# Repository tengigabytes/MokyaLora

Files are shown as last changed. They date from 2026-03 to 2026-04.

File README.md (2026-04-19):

# MokyaLora

An open-hardware standalone Meshtastic feature phone built around the RP2350B dual-core MCU,
with a 36-key physical keyboard, 2.4″ IPS display, SX1262 LoRa radio, and GNSS.
Licensed under CERN-OHL-S-2.0 (hardware) and CC-BY-SA-4.0 (documentation).

## Project Status

### Hardware

| Revision | Status |
|---|---|
| Rev A | **Received 2026-04-02 — bringup in progress** — 21 of 25 steps fully passed; 3 open issues |

**Rev A bringup summary** (see [`docs/bringup/rev-a-bringup-log.md`](docs/bringup/rev-a-bringup-log.md) for full details):

| Step | Component | Result |
|---|---|---|
| 1 | Power rails (1.8 V / 3.3 V) | ✅ PASS |
| 2 | MCU boot + USB CDC | ✅ PASS |
| 3 | I2C sensors (IMU / Mag / Baro / GNSS) | ✅ PASS |
| 4 | TFT LCD (ST7789VI, PIO 8080) | ✅ PASS (via FPC adapter — Issue 5) |
| 5 | LoRa SX1262 (SPI + RF link) | ✅ PASS (TX/RX verified — Step 23) |
| 6 | Keypad (6×6 matrix, 36 keys) | ✅ PASS |
| 7 | Audio — NAU8315 I2S amp + speaker | ✅ PASS |
| 8 | Battery (BQ25622 charger) + vibration motor | ⚠️ CONDITIONAL (charger OK; BQ27441 cold-boot NACK — Issue 10) |
| 9 | Flash + PSRAM (W25Q128JW + APS6404L) | ✅ PASS (QPI 37.5 MHz, 150 Mbit/s, 8 MB validated) |
| 10 | PDM microphone (IM69D130) | ⚠️ PARTIAL (capture/playback OK; background noise) |
| 11 | J-Link SWD debug | ✅ PASS |
| 12 | BQ27441 fuel gauge | ⚠️ CONDITIONAL (SOC readable; learning cycle pending) |
| 13 | TFT fast refresh (DMA) | ✅ PASS (60–80 FPS) |
| 14 | GNSS outdoor RF test | ❌ FAIL (0 satellites — Issue 11) |
| 15 | LoRa RF performance | ✅ PASS (Meshtastic mesh validated) |
| 16 | Core 1 (A–H stages) | ✅ PASS (FreeRTOS SMP, IPC, sensors, SPI) |
| 17 | Meshtastic integration | ✅ PASS (bidirectional mesh messaging) |
| 18–19 | Interactive menu + regression tests | ✅ PASS (51+ commands, TFT menu, 18/20 reliable) |
| 20–21 | Menu consolidation + code modularisation | ✅ PASS (21 source files, ~8580 lines) |
| 23 | LoRa standalone TX/RX | ✅ PASS (6 bug fixes, AES-128-CTR TX) |
| 24 | Core 1 TFT output + menu wrap-around | ✅ PASS |
| 25 | PSRAM DMA error investigation | ⚠️ CONDITIONAL (DMA burst read errors observed, root cause unconfirmed; CPU read workaround) |

**Open issues:** Issue 10 (BQ27441 cold-boot latchup), Issue 11 (GNSS 0 satellites), Issue 14 (PSRAM DMA burst read errors — root cause unconfirmed, no production impact).

### Firmware

| Component | Status |
|---|---|
| Core 0 — Meshtastic modem | **Validated** — LoRa modem running on Rev A (v2.7.15 dev, `rp2350b-mokya` variant); bidirectional mesh messaging confirmed |
| Core 1 — FreeRTOS + UI | **Architecture validated** — FreeRTOS SMP, manual TinyUSB CDC, IPC, I2C sensors all proven on hardware; LVGL integration pending |
| MokyaInput Engine (MIE) | **Phase 1 complete** — full IME (Smart Zh/En, Direct, Bopomofo), C API, 83/83 tests passing |
| Bringup shell | **Active** — `firmware/tools/bringup/`; 51+ commands, TFT interactive menu, 21 source files |

## System Overview

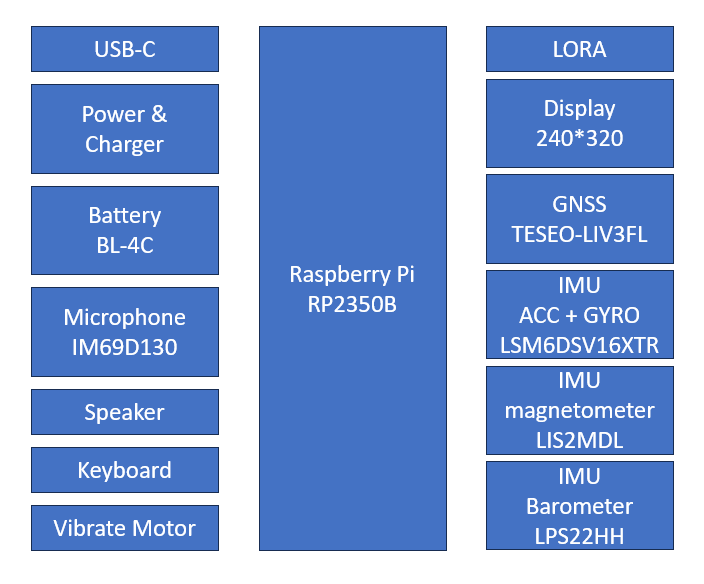
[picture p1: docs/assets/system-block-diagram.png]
System Block Diagram


## PCB Preview (Rev A)

| Front | Back |
|:-----:|:----:|
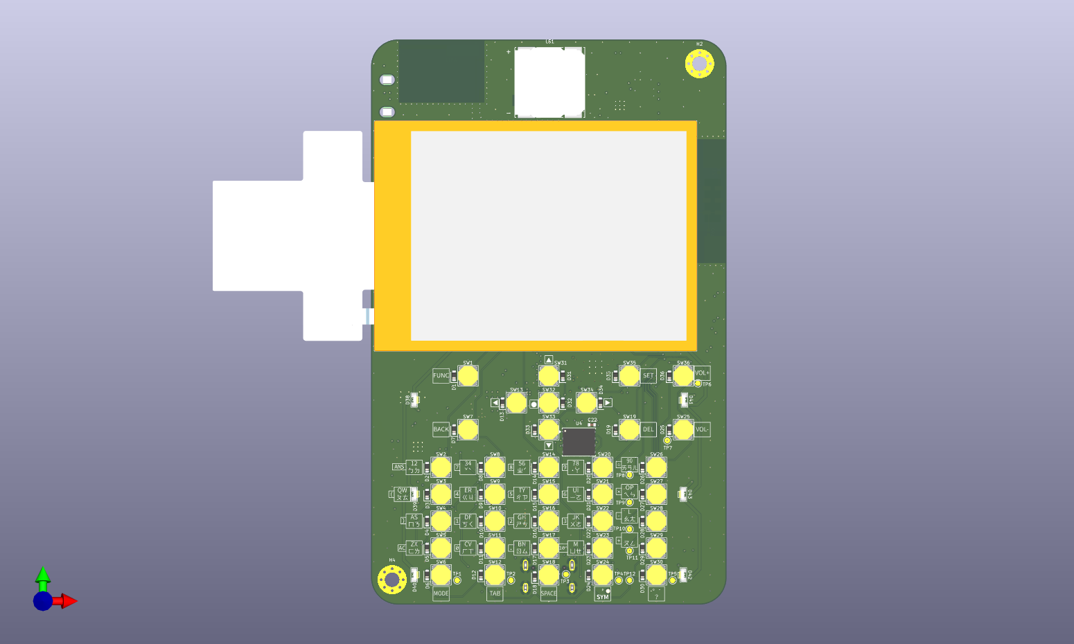
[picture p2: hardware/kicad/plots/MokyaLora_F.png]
PCB Front
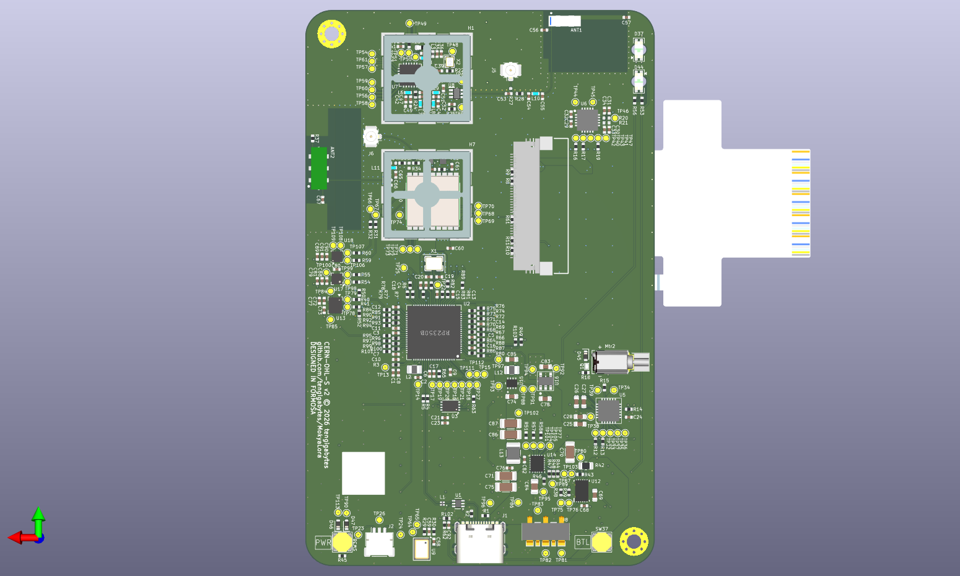
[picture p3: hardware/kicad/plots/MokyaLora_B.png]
PCB Back
|  |  |

## Design Documents

| Document | Description |
|---|---|
| [Schematic (PDF)](hardware/production/rev-a/pdf/MokyaLora.pdf) | Full schematic — all 13 sheets |
| [Assembly Drawing (PDF)](hardware/production/rev-a/pdf/MokyaLora__Assembly.pdf) | Component placement drawing |
| [Bill of Materials (CSV)](hardware/production/rev-a/MokyaLora.csv) | Rev A BOM |
| [Board 3D Model (STEP)](hardware/production/rev-a/MokyaLora.step) | Full-board STEP export |
| [Gerber Files](hardware/production/rev-a/gerber/) | Rev A fabrication outputs |

## Repository Layout

```
MokyaLora/
├── docs/
│   ├── assets/                         # Documentation images (block diagrams, etc.)
│   ├── requirements/                   # Requirements specifications
│   │   ├── system-requirements.md      # System-level spec, operating modes, mandatory HW rules
│   │   ├── hardware-requirements.md    # Full BOM, power tree, GPIO map, keypad matrix, design rules
│   │   └── software-requirements.md   # SRS (WHAT): driver needs, power states, UI/UX, IME requirements
│   ├── design-notes/                   # Design decision records
│   │   ├── power-architecture.md       # Power tree, rail definitions, charger/gauge configuration
│   │   ├── rf-matching.md              # LoRa / GNSS RF frontend, TCXO coupling, antenna rules
│   │   └── mcu-gpio-allocation.md      # Full GPIO pin map, I2C bus allocation
│   ├── bringup/                        # Bring-up and debug logs
│   │   ├── rev-a-bringup-log.md
│   │   └── measurements/               # Oscilloscope / spectrum captures
│   └── manufacturing/                  # Manufacturing-related documents
│       ├── fab-notes.md                # PCB specification, Gerber list, assembly notes
│       └── compliance.md              # Regulatory notes (CE / FCC / NCC)
├── hardware/
│   ├── kicad/                          # KiCad 8 source design files
│   │   ├── MokyaLora.kicad_pro         # Project file
│   │   ├── MokyaLora.kicad_sch         # Top-level schematic (13 sub-sheets)
│   │   ├── MokyaLora.kicad_pcb         # PCB layout
│   │   ├── MokyaLora.kicad_sym         # Project symbol library
│   │   ├── *.kicad_dbl                 # Component database libraries (ODBC: KiCad-Library DSN)
│   │   ├── MokyaLora.pretty/           # Project footprint library (61 footprints)
│   │   ├── packages3D/                 # Component 3D models — see NOTICE for licensing
│   │   ├── FabricationFiles/           # KiCad fabrication output (Gerbers + BOM)
│   │   └── plots/                      # KiCad plot output (schematic PDF)
│   ├── production/                     # Released fabrication snapshots (copied from FabricationFiles)
│   │   └── rev-a/
│   │       ├── gerber/                 # Gerber + drill files
│   │       ├── pdf/                    # Schematic PDF + assembly drawing PDF
│   │       ├── MokyaLora.csv           # Bill of Materials
│   │       └── MokyaLora.step          # Full-board 3D export
│   └── mechanical/                     # Enclosure and stack-up drawings (future)
│       └── enclosure/
├── firmware/                           # Firmware (future — Arduino-Pico + FreeRTOS + LVGL)
│   ├── CMakeLists.txt
│   ├── core0/                          # Core 0 modem firmware [GPL-3.0]
│   │   └── src/                        # Meshtastic stack integration
│   ├── core1/                          # Core 1 UI & application firmware [Apache-2.0]
│   │   └── src/                        # LVGL, FreeRTOS, MIE integration
│   ├── mie/                            # MokyaInput Engine — IME sub-library [MIT]
│   │   ├── CMakeLists.txt              # Builds as static library; no Pico SDK dependency
│   │   ├── include/mie/                # Public headers
│   │   ├── src/                        # Trie-Searcher, IME-Logic
│   │   ├── hal/                        # IHalPort interface + rp2350 / pc adapters
│   │   ├── tools/                      # gen_font.py, gen_dict.py (data pipeline)
│   │   ├── data/                       # Generated .bin assets (gitignored)
│   │   └── tests/                      # C++ unit tests (host build only)
│   ├── shared/
│   │   └── ipc/                        # Inter-core IPC protocol definition [MIT]
│   │       └── ipc_protocol.h          # Sole interface boundary between Core 0 and Core 1
│   └── tools/                          # Flash scripts and test utilities
└── .gitignore
```

## Licenses

| Component | Directory | License |
|---|---|---|
| Hardware design | `hardware/` | CERN-OHL-S-2.0 |
| Documentation | `docs/` | CC-BY-SA-4.0 |
| Core 0 firmware | `firmware/core0/` | GPL-3.0 |
| Core 1 firmware | `firmware/core1/` | Apache-2.0 |
| MokyaInput Engine | `firmware/mie/` | MIT |
| IPC protocol | `firmware/shared/ipc/` | MIT |

See [LICENSE](LICENSE) for the full rationale. License files are also present in each component directory.

## Authorship and Development Approach

| Area | Authorship |
|---|---|
| Requirements — technical concepts and design decisions | Project owner |
| Requirements — document writing and formatting | Assisted by [Claude Code](https://claude.ai/claude-code) |
| Hardware design (schematic, PCB layout) | Project owner |
| Documentation — organisation, formatting, and structure | Assisted by [Claude Code](https://claude.ai/claude-code) |
| Firmware and software development | Assisted by [Claude Code](https://claude.ai/claude-code) |

All technical concepts, design decisions, and hardware choices originate with the project
owner. Claude Code is used as a development tool; all AI-assisted output is reviewed and
accepted by the project owner before being committed.

## Disclaimer

> **This project is an experimental prototype. Use at your own risk.**

### Hardware

- **Prototype status** — Rev A is an unverified first prototype. The design has not been
  independently tested, reviewed, or certified. Do not use this design as the sole basis
  for a production product without thorough independent validation.

- **RF and wireless regulations** — This device incorporates a LoRa radio transmitter.
  Operation of radio transmitters is regulated by law in most jurisdictions (NCC in Taiwan,
  CE/RED in the EU, FCC Part 15 in the US, and equivalents elsewhere). The user is solely
  responsible for ensuring that any use of this design complies with applicable local
  wireless regulations. No regulatory certification (CE, FCC, NCC) has been obtained for
  this design.

- **Battery and electrical safety** — This design includes a lithium-ion battery charging
  circuit. Improper assembly, use of incorrect components, or failure to follow safe
  lithium-ion handling practices may result in fire, injury, or damage to property.
  Always verify the design independently before assembly.

- **No warranty** — This hardware is provided "as-is" without any warranty of any kind,
  express or implied. See [CERN-OHL-S-2.0](LICENSE-CERN-OHL-S-2.0.txt) Section 6 for the
  full disclaimer of warranties and limitation of liability.

### Firmware

- **Bringup firmware** — A hardware validation shell (`firmware/tools/bringup/`) is
  available for Rev A bring-up. It is a development/test tool only and is not intended
  for end-user deployment.

- **MokyaInput Engine (MIE)** — The IME sub-library (`firmware/mie/`) is available as a
  host-buildable static library with unit tests. It has not yet been integrated with
  RP2350B hardware.

- **Core 0 / Core 1** — Application firmware development has not yet started.

- **No warranty** — All firmware is provided "as-is" under its respective open-source
  licence (GPL-3.0 for Core 0, Apache-2.0 for Core 1, MIT for MIE and bringup tools)
  without any warranty of fitness for a particular purpose.

## Contributing

See [CONTRIBUTING.md](CONTRIBUTING.md) for contribution guidelines.

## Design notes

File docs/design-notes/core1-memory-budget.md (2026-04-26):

# Core 1 Memory Budget

Single source of truth for RAM allocations on the Core 1 application image
(`m1_bridge`, loaded at `0x10200000`). Any new task, queue, or large static
buffer MUST be added to the appropriate table below **before** the code is
merged. The build-time log line (see §5) cross-checks this at boot.

Rationale: M3.4.5d uncovered the pattern of growing `configTOTAL_HEAP_SIZE`
reactively after each new task HardFaulted on `vTaskStartScheduler`'s
IDLE-task allocation. Planning upfront is cheaper than SWD archaeology.

---

## 1. RP2350B SRAM

Physical SRAM on RP2350B is **520 KB** at `0x20000000 – 0x20082000`.

| Region | Size | Owner | Notes |
|---|---|---|---|
| Shared IPC window | 24 KB | Core 0 ↔ Core 1 | Fixed, reserved at link time — see firmware-architecture.md §5. |
| Core 1 .text/.rodata/.data/.bss | ~300 KB | m1_bridge image | Driver/LVGL/FreeRTOS code + statics. |
| FreeRTOS heap (heap_4) | **48 KB** | `configTOTAL_HEAP_SIZE` | Task stacks, TCBs, kernel objects. See §3. |
| LVGL heap | **48 KB** | `LV_MEM_SIZE` in `lv_conf.h` | Separate from FreeRTOS. Widgets, styles, fonts, draw buffers. |
| MCU main stack (MSP) | 4 KB | linker `__StackTop` | Pre-scheduler + exception handlers. |
| LVGL framebuffer(s) | see §4 | `display/lvgl_glue.c` | Currently one partial buffer. |
| Slack | — | — | Whatever's left. Goal: keep ≥ 32 KB unused for growth. |

`scripts/build_and_flash.sh` prints the section sizes after each Core 1
link; compare against this table when the numbers drift.

---

## 2. Design rules

1. **Upfront budget.** Adding a new task or any `pvPortMalloc`-caller
   (queue, semaphore, event group, timer) requires updating §3 **in the
   same commit**. No silent growth.
2. **No silent failures.** Every `xTaskCreate` return value and every
   `*_task_start` boolean MUST be checked. Main aborts with a clear log
   line if anything fails — see `main_core1_bridge.c`. No more
   `(void)rc_xxx;`.
3. **Stack sizing method.** Start from an empirical peak:
   - enable `configCHECK_FOR_STACK_OVERFLOW = 2` (already set)
   - run the task under its worst-case path for at least 10 minutes
   - read `uxTaskGetStackHighWaterMark()` via SWD or a runtime CLI
   - round up to high-water + 25 % (not +1 %).
4. **Prefer static allocation for kernel objects.** FreeRTOS supports
   `xQueueCreateStatic` / `xSemaphoreCreateMutexStatic`. We currently use
   dynamic allocation because `configSUPPORT_STATIC_ALLOCATION = 0`.
   Flip only when we actually need to diagnose heap fragmentation.
5. **LVGL heap stays separate.** Widgets, styles, lv_malloc — all from
   `LV_MEM_SIZE`. Never split widgets across FreeRTOS heap.
6. **Reserve ≥ 15 % of `configTOTAL_HEAP_SIZE`** at all times. With the
   current 48 KB heap, that is ≥ 7.2 KB free after all tasks are
   running. The boot-time log prints the figure (and stashes it in
   `g_core1_boot_heap_free` for SWD readback) — `main` panics if we
   cross it. **Threshold was loosened from 20 % to 15 % on 2026-04-24**
   when the Phase 1.6 RTT key-inject task (1 KB TCB/stack) pushed free
   from 9.6 KB down to ~9 KB; see `phase2-log.md` "P1.6 follow-up"
   entry. The original 20 % target was a forward-looking budget for
   "future driver growth", not a hard requirement — 15 % still leaves
   1.6 KB buffer above transient FreeRTOS needs.

---

## 3. FreeRTOS heap budget (`configTOTAL_HEAP_SIZE = 48 KB`)

Heap is consumed by task stacks (4 bytes per word), TCBs (~88 B each on
32-bit V11), and kernel objects (queues/mutexes/semaphores ~80-100 B
each + their storage). `heap_4` adds ~16 B overhead per allocation.

### 3.1 Application tasks

| Task name | File | Stack (words) | Stack (B) | Priority | Purpose |
|---|---|---:|---:|---|---|
| `usb` | `main_core1_bridge.c` | 1024 | 4096 | tskIDLE+2 | TinyUSB device; `tud_task()` + taskYIELD loop. |
| `bridge` | `main_core1_bridge.c` | 1024 | 4096 | tskIDLE+2 | Core 0 ↔ Core 1 IPC pump; HW-FIFO doorbell listener. |
| `lvgl` | `src/display/lvgl_glue.c` | 3072 | 12288 | tskIDLE+2 | `lv_timer_handler()` + draw buffer flush; largest stack because LVGL draw paths nest deeply. |
| `kpad` | `src/keypad/keypad_scan.c` | 512 | 2048 | tskIDLE+2 | PIO+DMA keypad scan, 20 ms debounce, enqueue `key_event_t`. |
| `chg` | `src/power/bq25622.c` | 512 | 2048 | tskIDLE+2 | 1 Hz charger poll + watchdog kick. |
| `sens` | `src/sensor/sensor_task.c` | 512 | 2048 | tskIDLE+2 | Shared tick for LPS22HH / LIS2MDL / LSM6DSV16X. |
| `gps` | `src/sensor/gps_task.c` | 512 | 2048 | tskIDLE+2 | Teseo-LIV3FL NMEA drain + parser. |
| `ime` | `src/ime/ime_task.cpp` | 1024 | 4096 | tskIDLE+3 | Drain `key_event_t` queue → `ImeLogic::process_key`; 20 ms `tick()` for multi-tap / long-press; owns the `ImeLogic` instance + both `TrieSearcher` instances as statics (~3 KB, see §4). Primary consumer of the KeyEvent queue (FA §4.4); the listener callbacks are re-entrancy-free. |
| `key_inject` | `src/keypad/key_inject.c` | 256 | 1024 | tskIDLE+2 | Drain `g_key_inject_buf` ring (SWD transport) → `key_event_push_inject_flags`. Skip-loop when `g_key_inject_mode != SWD`. |
| `key_inj_rtt` | `src/keypad/key_inject_rtt.c` | 256 | 1024 | tskIDLE+2 | Drain SEGGER RTT down-channel 1 → parse binary wire frame → `key_event_push_inject_flags`. Skip-loop when `g_key_inject_mode != RTT`. Stack sized for TRACE()'s 128 B vsnprintf scratch. |
| **App subtotal** |  | | **34,944 B (34.1 KB)** | | |

### 3.2 FreeRTOS internal tasks

| Task | Stack (words) | Stack (B) | Source |
|---|---:|---:|---|
| `IDLE` | 512 (`configMINIMAL_STACK_SIZE`) | 2048 | `tasks.c` creates during `vTaskStartScheduler`. |
| `Tmr Svc` | 512 (`configTIMER_TASK_STACK_DEPTH`) | 2048 | `timers.c`, enabled by `configUSE_TIMERS = 1`. |
| **Kernel subtotal** | | **4096 B (4.0 KB)** | |

### 3.3 Queues, semaphores, misc

| Object | File | Storage | Overhead | Total |
|---|---|---:|---:|---:|
| `i2c_bus_mutex` (mutex) | `src/i2c/i2c_bus.c` | — | ~80 B | ~80 B |
| `KeyEvent queue` (16 × 2 B) | `src/keypad/key_event.c` | 32 B | ~80 B | ~112 B |
| `KeyEvent view queue` (16 × 2 B) | `src/keypad/key_event.c` | 32 B | ~80 B | ~112 B |
| `ime snapshot mutex` | `src/ime/ime_task.cpp` | — | ~80 B | ~80 B |
| Timer queue (10 × ~12 B) | `timers.c` | ~120 B | ~80 B | ~200 B |
| TCBs (9 tasks × ~88 B) | `tasks.c` | — | — | ~792 B |
| Heap_4 per-alloc overhead | `heap_4.c` | — | ~16 B × ~15 blocks | ~240 B |
| **Misc subtotal** | | | | **~1.6 KB** |

### 3.4 Totals

| | Bytes (pre-IME) | Post-M4 IME | Post-P1.6 follow-up (RTT) |
|---|---:|---:|---:|
| §3.1 App tasks | 28,864 | 32,960 | 34,944 |
| §3.2 Kernel tasks | 4,096 | 4,096 | 4,096 |
| §3.3 Queues / TCBs / overhead | ~1,420 | ~1,700 | ~1,900 |
| **Estimated** | **~34.4 KB** | **~38.8 KB** | **~40.9 KB** |
| `configTOTAL_HEAP_SIZE` | 49,152 | 49,152 | 49,152 |
| **Reserve (threshold 15 %)** | **~14.7 KB (30 %)** ✓ | **~10.5 KB (21 %)** ✓ | **~8.2 KB (17 %)** ✓ |

**Measured 2026-04-24 post RTT task (SWD, `g_core1_boot_heap_free`)**:
`xFreeBytesRemaining = 9,312 B (19 %)` — 1.9 KB above the 15 %
panic threshold; ~0.3 KB below the estimate, consistent with
heap_4 fragmentation overhead settling at ~10 %.

**Measured via SWD (2026-04-18, post-M3.4.5d, before IME task lands)**:
`xFreeBytesRemaining = 15,008 B (14.65 KB, 30.5 %)`,
`xMinimumEverFreeBytesRemaining = 15,008 B` — estimate matches reality.
The post-M4 column is projected; re-measure after `ime` task creation
and revisit the stack sizing if the IME state ends up larger than
~3 KB or run_search's prefix-scan working set pushes over 4 KB stack.

---

## 4. Notable static buffers

Not exhaustive — just the ones large enough (≥ 256 B) to care about.

| Buffer | File | Size | Notes |
|---|---|---:|---|
| `s_drain_buf` | `src/sensor/teseo_liv3fl.c` | 256 B | Teseo I2C burst read buffer. |
| `s_gsv` accumulator × 4 | same | ~400 B | Per-talker satellite cycle builders. |
| `s_sat_view` | same | ~200 B | Published 32-sat snapshot. |
| `s_rf_state` | same | ~440 B | RF/signal diagnostics (noise, ANF, CPU, per-sat). Populated only after `teseo_enable_rf_debug_messages(true)` commissioning. |
| `s_line` | same | 96 B | NMEA line accumulator. |
| `ImeLogic` instance (M4) | `src/ime/ime_task.c` | ~3 KB | 50 × `Candidate` (~40 B) ≈ 2 KB + 256 B display + 64 B key_seq + ~200 B per-candidate prefix + state. Static to keep the `ime` task stack small. |
| LVGL draw buffer | `src/display/lvgl_glue.c` | TBD | One partial buffer for ST7789VI; update when the allocation is promoted from `LV_MEM_SIZE` to explicit static. |

Shared-SRAM IPC buffers (SPSC rings + GPS double-buffer) live in the
24 KB IPC window and are **not** in either heap — see §5 of
`firmware-architecture.md`.

---

## 5. Boot-time invariants (implemented in `main_core1_bridge.c`)

After `vTaskStartScheduler()` returns control to the scheduler and the
first task runs, the bridge task logs:

```
[m1] heap: total=49152  free=NNNNN  minEverFree=NNNNN  (target free ≥ 9830 = 20%)
```

If `free < 20 % of total`, this is flagged via IPC `LOG_LINE` at WARN
level so any regression during CI or commissioning is visible on the
host.

Every task-start helper (`lvgl_glue_start`, `bq25622_start_task`,
`sensor_task_start`, `gps_task_start`, `keypad_scan_task_create`) and
every direct `xTaskCreate` call in `main` is wrapped in:

```c
if (rc_foo != pdPASS) { panic("xTaskCreate(foo) failed"); }
```

No `(void)rc_xxx` casts. A panic prints the task name so the failing
allocation is immediately obvious from the USB CDC log (no more SWD
`mem32 ...ED28` archaeology to figure out which task ran out of heap).

---

## 6. Checklist when adding a new task

1. Decide on a stack size — start from **512 words** unless the task has
   a specific reason to be larger (LVGL → 3072 from empirical draw
   recursion, USB → 1024 because TinyUSB lives in globals).
2. Add a row to §3.1 in this file and update §3.4 Totals.
3. If the new subtotal pushes Reserve below 20 %, bump
   `configTOTAL_HEAP_SIZE` **in the same commit** that adds the task.
4. Wire the `*_task_start` helper into `main_core1_bridge.c` with a
   `panic`-on-fail check. Never `(void)rc_xxx`.
5. After the first successful run, read `uxTaskGetStackHighWaterMark()`
   and update the row if the stack can be shrunk (leave +25 % headroom).

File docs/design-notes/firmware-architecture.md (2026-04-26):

# Firmware Architecture

**Project:** MokyaLora (Project MS-RP2350)
**Status:** Phase 2 — Core 0/Core 1 dual-image production firmware (Rev A)
**Last updated:** 2026-04-15

This document is the **single source of truth** for how MokyaLora's dual-core
firmware is built. If it conflicts with the SRS
(`docs/requirements/software-requirements.md`) or with CLAUDE.md on any
implementation detail — memory map, IPC byte layout, build flow, boot sequence,
licence boundary — this document and the normative headers it references
(`ipc_protocol.h`, `ipc_shared_layout.h`, `memmap_core1_bridge.ld`) win.

The SRS specifies **what** the firmware must do (user behaviour, performance
targets, compatibility). This document specifies **how** that is realised.

It covers:

1. Dual-core AMP topology and licence boundary (§1)
2. Full memory map — Flash layout, SRAM partition, PSRAM allocation (§2)
3. Per-core software stacks — from HW peripheral up through driver → HAL → service → app (§3, §4)
4. USB Mode OFF / COMM — charge-only vs composite CDC (Meshtastic + Control) (§4.6); Control Protocol (§4.7)
5. Shared-SRAM IPC — 24 KB byte map, message catalogue, end-to-end flows, doorbell (§5)
6. MIE user-dictionary persistence via IPC (§5.7, planned for M5+)
7. Cross-image non-interference — link, boot, SRAM, SPSC, memory ordering, flash safety (§6)
8. Bus and peripheral ownership (§7)
9. Build system isolation — PlatformIO vs. CMake, ELF vs. BIN, dual-image flashing (§8)
10. Boot sequence, handshake, watchdog discipline and safe mode (§9)
11. UF2 release distribution strategy (§10)
12. Licence compliance for binary distribution (§11)
13. Hardware revision boundary — what survives vs. what is Rev A-only (§12)

Primary sources of truth:

- `firmware/core1/m1_bridge/memmap_core1_bridge.ld` — Core 1 linker script
- `firmware/core0/meshtastic/variants/rp2350/rp2350b-mokya/patch_arduinopico.py` — Core 0 memmap patch
- `firmware/core0/meshtastic/variants/rp2350/rp2350b-mokya/platformio.ini` — Core 0 build config
- `firmware/core1/m1_bridge/CMakeLists.txt` — Core 1 build config
- `firmware/shared/ipc/ipc_protocol.h`, `ipc_shared_layout.h`, `ipc_ringbuf.[ch]` — IPC transport
- `scripts/build_and_flash.sh` — dual-image build + flash driver
- `docs/design-notes/ipc-ram-replan.md` — budget derivation & SWD verification record
- `docs/requirements/software-requirements.md` — normative SRS

---

## 1. Dual-Core AMP Topology

MokyaLora runs the RP2350B's two Cortex-M33 cores as independent AMP images with separate
flash slots, separate SRAM regions, separate schedulers, and separate licences. Core 0 is
launched by the bootrom from `0x10000000`; Core 0 then launches Core 1 via
`multicore_launch_core1_raw()` from `0x10200000`.

| Attribute | Core 0 | Core 1 |
|---|---|---|
| Role | Meshtastic LoRa modem | UI host, IME, power manager, all I2C drivers |
| Licence | GPL-3.0 | Apache-2.0 |
| Flash slot | `0x10000000` (2 MB) | `0x10200000` (2 MB) |
| SRAM region | `0x20000000 – 0x2002BFFF` (176 KB) | `0x2002C000 – 0x20079FFF` (312 KB) |
| Framework | Arduino-Pico + Meshtastic base | Pico SDK + FreeRTOS + LVGL |
| Scheduler | `OSThread` cooperative (`concurrency::Scheduler`)| FreeRTOS V11.3.0 preemptive (single-core port) |
| Boot model | Bootrom → crt0 → `main()` | `multicore_launch_core1_raw()` (no IMAGE_DEF) |
| Build tool | PlatformIO (`pio run`) | CMake + Ninja |
| Owns | SPI1 + SX1262 | I2C ×2, PIO (keypad, LCD), PWM, GPIO, USB CDC |

The sole cross-core compile-time dependency is `firmware/shared/ipc/ipc_protocol.h` (MIT) —
POD types, `<stdint.h>` only. The IPC boundary behaves as a **wire protocol**, not a library
link. There is no C++, no pointers, no project-internal header dependency.

---

## 2. Memory Map — Complete View

RP2350B has three distinct storage resources. Each is partitioned between the two cores at
link time; no run-time allocator ever crosses the boundary.

```
┌─────────────────────────────────────────────────────────────────────────┐
│  W25Q128JW QSPI Flash (16 MB)  — XIP via QMI                            │
│  ┌─────────────────────────────────────────────────────────────────┐    │
│  │  0x10000000 │ Core 0 firmware     │ 2 MB │ GPL-3.0 ELF          │    │
│  │  0x10200000 │ Core 1 firmware     │ 2 MB │ Apache-2.0 BIN       │    │
│  │  0x10400000 │ MIE dict (MDBL)     │ 6 MB │ gen_dict.py → PSRAM  │    │
│  │  0x10A00000 │ MIE font (MIEF)     │ 2 MB │ gen_font.py, XIP     │    │
│  │  0x10C00000 │ LittleFS            │ 4 MB │ settings + msg DB    │    │
│  └─────────────────────────────────────────────────────────────────┘    │
│                                                                         │
│  RP2350B SRAM (520 KB)  — on-chip, 0 wait-state                         │
│  ┌─────────────────────────────────────────────────────────────────┐    │
│  │  0x20000000 │ Core 0 region       │ 176 KB │ Meshtastic image   │    │
│  │  0x2002C000 │ Core 1 region       │ 312 KB │ FreeRTOS+LVGL+MIE  │    │
│  │  0x2007A000 │ Shared IPC          │  24 KB │ NOLOAD rings + GPS │    │
│  │  0x20080000 │ SCRATCH_X (Core 0)  │   4 KB │ task stack         │    │
│  │  0x20081000 │ SCRATCH_Y (Core 0)  │   4 KB │ MSP/ISR stack      │    │
│  └─────────────────────────────────────────────────────────────────┘    │
│                                                                         │
│  APS6404L QSPI PSRAM (8 MB)  — XIP via QMI, Core 1 only                 │
│  ┌─────────────────────────────────────────────────────────────────┐    │
│  │  0x11000000 │ MIE dictionary      │ 4 MB │ DAT + values (XIP)   │    │
│  │  0x11400000 │ Application heap    │ 4 MB │ msg history, node $  │    │
│  └─────────────────────────────────────────────────────────────────┘    │
└─────────────────────────────────────────────────────────────────────────┘
```

### 2.1 Flash Layout (16 MB — W25Q128JW)

| Address | Size  | Content | Owner | Write policy |
|---|---|---|---|---|
| `0x10000000` | 2 MB  | Core 0 firmware (Meshtastic ELF) | Core 0 ELF | J-Link flash or OTA |
| `0x10200000` | 2 MB  | Core 1 firmware (raw `.bin`, no IMAGE_DEF) | Core 1 BIN | J-Link flash or OTA |
| `0x10400000` | 6 MB  | MIE dict (MDBL blob, ~5 MB used) | gen_dict.py | gen + flasher, read-only  |
| `0x10A00000` | 2 MB  | MIE font (MIEF blob, ~250 KB-1 MB used) | gen_font.py | gen + flasher, read-only  |
| `0x10C00000` | 4 MB  | LittleFS — user config, message DB, NodeDB | Core 0 | at runtime (flash-safe) |

Notes:
- The two firmware slots are hard-coded in the linker scripts, not a bootloader. Switching
  to A/B OTA later only requires rewriting the launch sequence in Core 0's early init.
- LittleFS is mounted by Core 0 (Meshtastic's existing persistence layer writes here).
  Core 1 never touches this region directly — any config change goes via `IPC_CMD_SET_CONFIG`
  so Core 0 is the sole flash writer. This keeps the P2-11 flash-write safety discipline
  single-core: only Core 0 needs to coordinate the "park Core 1 + disable IRQ + XIP off"
  dance (see `flash_safety_wrap.c`).
- Assets are two independent partitions so dict and font can be flashed + grown independently.
  **Dict** (`gen_dict.py` → MDBL blob): Core 1 copies the DAT + values sections into PSRAM
  at boot via `mie_dict_load_to_psram` and hands PSRAM pointers to `mie_dict_open_memory`.
  **Font** (`gen_font.py` → MIEF blob): Core 1's font driver (`mie_font.c`) reads glyphs
  directly from flash XIP — no PSRAM copy — so the font occupies no SRAM/PSRAM beyond the
  16-byte `s_blob` descriptor.
- OTA / factory-recovery partition is deferred to M6. Until then, `0x10400000 - 0x10C00000`
  is owned by the asset partitions; the OTA flow will carve its own region in the LittleFS
  quadrant or shrink the dict reservation once compression lands.

### 2.2 SRAM Partition (520 KB on-chip)

Verified by reading both linker scripts and by SWD inspection of both cores' SPs +
`g_ipc_shared.boot_magic` after boot.

```
0x20000000 ┌────────────────────────────────────────────────────┐
           │  Core 0 — Meshtastic (GPL-3.0)               176KB │
           │   .vector + .data + .bss             54 KB         │
           │   .heap (protobuf, NodeDB, router)  122 KB         │
0x2002C000 ├────────────────────────────────────────────────────┤
           │  Core 1 — FreeRTOS + LVGL + MIE (Apache-2.0) 312KB │
           │   LCD framebuffer 240×320×16bpp     150 KB         │
           │   LVGL heap + widgets                48 KB         │
           │   FreeRTOS Heap4 (task stacks+TCB)   32 KB         │
           │   FreeRTOS kernel .bss                8 KB         │
           │   HAL + MIE + App state              28 KB         │
           │   Main stack (__StackBottom..Top)     8 KB         │
           │   Reserve / margin                   38 KB         │
0x2007A000 ├────────────────────────────────────────────────────┤
           │  Shared IPC (NOLOAD, MIT)                     24KB │
           │   Handshake (16 B)                                 │
           │   3 × SPSC ring control + slots (21 KB)            │
           │   GPS double-buffer (260 B)                        │
           │   Reserved tail (3 KB, breadcrumbs at 0x5FC0)      │
0x20080000 ├────────────────────────────────────────────────────┤
           │  SCRATCH_X — Core 0 Arduino-Pico task stack   4KB  │
0x20081000 ├────────────────────────────────────────────────────┤
           │  SCRATCH_Y — Core 0 MSP / ISR stack           4KB  │
0x20082000 └────────────────────────────────────────────────────┘
           __StackTop (Core 0)
```

#### Core 0 SRAM breakdown (176 KB)

| Segment | Size | Contents |
|---|---|---|
| `.vectors` | ~1 KB | Cortex-M33 vector table (ROM copy lives in flash, RAM is writable) |
| `.data` | ~6 KB | Initialised globals (router state, config defaults) |
| `.bss` | ~47 KB  | Zero-init globals: NodeDB static, packet queue arrays, crypto ctx  |
| `.heap` | 122 KB  | Arduino-Pico + Meshtastic dynamic allocations |

Meshtastic's peak heap usage (200 nodes, full NodeDB + pending-packet queue + AES contexts)
sits around 100 KB; 122 KB gives ~20% headroom. The Arduino-Pico **task stack** (8 KB
cooperative `OSThread` stack) lives in `SCRATCH_X`, not in this 176 KB region.

#### Core 1 SRAM breakdown (312 KB)

| Segment | Size | Contents |
|---|---|---|
| Framebuffer | 150 KB  | `uint16_t fb[240*320]` — LVGL direct-mode primary buffer |
| LVGL internal heap | 48 KB | `lv_mem` pool — widgets, styles, image cache |
| FreeRTOS Heap4 | 32 KB | `ucHeap[]` — all task stacks + TCBs + queues (see §4.2) |
| FreeRTOS kernel .bss | 8 KB | task/timer list heads, scheduler state, critical nesting |
| HAL / driver state | 12 KB | I2C buffers, keypad scan buf, GPS NMEA parser |
| MIE runtime state | 10 KB | IME FSM, candidate ring, current syllable parser |
| App state | 6 KB | Message list cursors, LVGL obj pointers, power FSM |
| Main stack | 8 KB | `__StackBottom..__StackTop` — `main()` + ISR entry |
| Reserve / margin | 38 KB | unallocated; absorbs LVGL peak + message cache growth |

Task stacks are **not** a separate segment — under `heap_4` every `xTaskCreate()` call
allocates its stack out of `ucHeap`. Summing the per-task stacks in §4.2 plus ~2 KB of
idle/timer task overhead plus TCBs + queues yields ~28 KB live in Heap4, leaving 4 KB
headroom inside the 32 KB pool for burst queue growth.

Target margin ≥ 10 % of 312 KB (31 KB); current 38 KB margin is **12.2 %**.

#### Shared IPC region (24 KB) — see §5

#### SCRATCH_X / SCRATCH_Y (8 KB)

Owned by Core 0. Arduino-Pico's FreeRTOS port places its task stack in SCRATCH_X and the
MSP (handler-mode) stack in SCRATCH_Y. Core 1's linker script `PROVIDE`s zero-length
`__scratch_[xy]_*` symbols so the SDK's crt0 data-copy table sees an empty copy range and
never touches those addresses.

### 2.3 PSRAM Allocation (8 MB — APS6404L via QMI)

PSRAM is XIP-addressable at `0x11000000` and is accessible by either core via the shared
QMI/QSPI bus. In practice **only Core 1** uses PSRAM; Core 0 does not need it for the
planned workload.

| Address | Size  | Content | Access pattern |
|---|---|---|---|
| `0x11000000`  | 4 MB  | MIE dictionary — DAT + values | CPU random-access, <0.4 ms/query |
| `0x11400000`  | 4 MB  | Application heap | message history, node cache, LV image |

Rules:
- **Framebuffer is NOT in PSRAM.** APS6404L tops out at 12.8 FPS for full-frame reads due to
  QMI per-word overhead, and the DMA burst-read anomaly (Step 25 / Issue 14) is unresolved.
  Framebuffer therefore lives in the 150 KB SRAM block above.
- MIE dict + values are copied from Flash `0x10800000` (assets region) into PSRAM at boot;
  this takes ~40 ms and gives the IME sub-millisecond lookup latency.
- Application heap in PSRAM uses a simple bump allocator (single-writer, LIFO release at
  power-mode transition). No LVGL `lv_mem_alloc` backing in PSRAM because LVGL widgets need
  low-latency SRAM access during redraw.
- Both cores can access PSRAM via QMI but there is no software arbitration — by convention
  Core 0 never touches it under the Phase 2 build.

---

## 3. Core 0 Architecture — Meshtastic Modem

Core 0 is stock Meshtastic with exactly one structural change: the USB/BLE host transport is
replaced with `IPCPhoneAPI`, a subclass of Meshtastic's `PhoneAPI` that writes protobuf
bytes into the shared-SRAM ring instead of a serial or BLE endpoint. Everything above
`IPCPhoneAPI` is unmodified Meshtastic code.

### 3.1 Layered stack (bottom → top)

```
┌──────────────────────────────────────────────────────────────────────┐
│ APPLICATION    Meshtastic modules (modules/*.cpp)                    │
│   TextMessageModule · PositionModule · NodeInfoModule · AdminModule  │
│   Telemetry (device only) · Traceroute · NeighborInfo · Waypoint     │
├──────────────────────────────────────────────────────────────────────┤
│ SERVICE        MeshService · Router · Channels · PKI (CryptoEngine)  │
│                NodeDB · MessageStore (LittleFS persist)              │
├──────────────────────────────────────────────────────────────────────┤
│ TRANSPORT      PhoneAPI  ──(subclass)──►  IPCPhoneAPI                │
│                  │                         │ writes protobuf to      │
│                  │                         │ c0_to_c1 DATA ring      │
│                  └─ IpcSerialStream (replaces Arduino Serial) ◄─ CMD │
├──────────────────────────────────────────────────────────────────────┤
│ RADIO          RadioInterface (abstract) → SX126xInterface           │
│                MeshPacket queue · rx/tx FSM · CryptoEngine           │
├──────────────────────────────────────────────────────────────────────┤
│ SCHEDULER      concurrency::OSThread cooperative loop                │
│                FreeRTOS (single-core, configNUMBER_OF_CORES=1)       │
├──────────────────────────────────────────────────────────────────────┤
│ HAL            Arduino-Pico: SPI, GPIO, PIO-multicore doorbell       │
│                flash_safety_wrap (park Core 1 before XIP off)        │
├──────────────────────────────────────────────────────────────────────┤
│ HW             SX1262 (SPI1 GPIO 24–27) · W25Q128 XIP flash          │
│                SIO FIFO (inter-core doorbell)                        │
└──────────────────────────────────────────────────────────────────────┘
```

### 3.2 Scheduler model

Arduino-Pico cooperative `OSThread` scheduler (`concurrency::Scheduler`) drives all
Meshtastic runLoop work. FreeRTOS inside the Arduino-Pico core is forced to **single-core
mode** (`configNUMBER_OF_CORES=1`) because the upstream SMP port assumes it owns Core 1,
which MokyaLora gives to a separate image. The five framework patches that achieve this are
applied idempotently by `patch_arduinopico.py` at build time (see phase2-log Issue P2-2):

1. `SerialUSB.h` — extern guard under `-DNO_USB`
2. `freertos-main.cpp` — guard SMP call sites
3. `freertos-lwip.cpp` — guard SMP call sites
4. `portmacro.h` — add missing extern decl
5. `port.c` — drop `static` on a function the guard references

### 3.3 Meshtastic module exclusions

Core 0 is trimmed hard to fit 176 KB SRAM + 2 MB flash. From `platformio.ini`:

```
-D MESHTASTIC_EXCLUDE_GPS, _SCREEN, _WIFI, _BLUETOOTH, _I2C, _MQTT,
   _POWERMON, _POWER_FSM, _TZ, _AUDIO, _DETECTIONSENSOR,
   _ENVIRONMENTAL_SENSOR, _AIR_QUALITY_SENSOR, _HEALTH_TELEMETRY,
   _EXTERNALNOTIFICATION, _PAXCOUNTER, _POWER_TELEMETRY, _RANGETEST,
   _REMOTEHARDWARE, _STOREFORWARD, _ATAK, _CANNEDMESSAGES,
   _INPUTBROKER, _SERIAL, _POWERSTRESS
```

Kept: `TextMessage`, `Position`, `NodeInfo`, `Admin`, `Traceroute`, `NeighborInfo`,
`Waypoint`, `PKI`, `DeviceTelemetry`. GPS data arrives via the shared-SRAM GPS buffer —
Core 0 never talks I2C.

### 3.4 Flash-write safety

Core 0 is the sole flash writer (LittleFS + Meshtastic config). Flash erase/program on
RP2350 turns XIP off for the duration — any code running from XIP during that window faults
with IACCVIOL (P2-11).

The `flash_safety_wrap.c` TU `-Wl,--wrap`s `flash_range_erase` and `flash_range_program` to:

1. Raise a doorbell to Core 1: "park for flash write"
2. Wait for Core 1 acknowledge via FIFO
3. Disable all IRQs locally
4. Call the real function
5. Re-enable IRQs, release Core 1

Core 1's reset path for this doorbell is a tight busy-loop in RAM (no XIP fetch), so it is
safe while Core 0's XIP is off.

---

## 4. Core 1 Architecture — UI / App Host

Core 1 is a fresh Apache-2.0 image built with the Pico SDK directly (not Arduino-Pico). It
owns every peripheral that isn't LoRa: the LCD, keypad, all I2C sensors and PMICs, PWM
haptic motor, status LED, USB CDC. Audio (PDM mic + I2S amp) is **not** on the target
architecture — the next hardware revision removes both devices.

> **Writing a new Core 1 driver?** Read
> [`core1-driver-development.md`](core1-driver-development.md) first. It captures
> the RP2350B board-header requirement, GPIO / FreeRTOS / I2C / SysTick rules,
> and the top-down debug playbook distilled from M1–M3.3 incidents.

### 4.1 Layered stack (bottom → top)

```
┌──────────────────────────────────────────────────────────────────────┐
│ APPLICATION    LVGL screens (lv_scr_act view tree)                   │
│   MessagesApp · NodesApp · MapApp · CompassApp · SettingsApp         │
│   StatusBar · NotifyToast · IMEBar                                   │
├──────────────────────────────────────────────────────────────────────┤
│ SERVICE        MIE (IME)  · Power Manager FSM  · IPC Client          │
│                MessageModel (receives IPC_MSG_RX_TEXT)               │
│                NodeModel   (receives IPC_MSG_NODE_UPDATE)            │
│                StatusModel (receives IPC_MSG_DEVICE_STATUS)          │
│                ConfigModel (get/set via IPC_CMD_GET/SET_CONFIG)      │
├──────────────────────────────────────────────────────────────────────┤
│ HAL            Charger (BQ25622)   · Gauge (BQ27441)                 │
│                IMU (LSM6DSV16X)    · Mag (LIS2MDL) · Baro (LPS22HH)  │
│                GPS (Teseo-LIV3FL)  · StatusLED (LM27965)             │
│                HapticMotor (PWM)   · KeypadScan (PIO+DMA) · LCD (PIO)│
│                USB Composite (TinyUSB) — CDC#0 Meshtastic + CDC#1 Ctrl│
├──────────────────────────────────────────────────────────────────────┤
│ DRIVER         I2C abstraction · PIO program loader · DMA dispatch   │
│                TinyUSB device core                                   │
├──────────────────────────────────────────────────────────────────────┤
│ SCHEDULER      FreeRTOS V11.3.0 preemptive (single-core port)        │
│                tasks: UI, IPCRx, KeypadScan, Sensors, Power, USB,    │
│                       UsbCtrl (CDC#1, build-gated)                   │
├──────────────────────────────────────────────────────────────────────┤
│ HW             i2c1 mux (6/7 power · 34/35 sensor+GNSS) · SPI0       │
│                PIO0 (LCD) · PIO1 (keypad) · PWM (motor) · USB        │
│                SIO FIFO (inter-core doorbell)                        │
└──────────────────────────────────────────────────────────────────────┘
```

### 4.2 FreeRTOS task layout

FreeRTOS V11.3.0 RP2350 Cortex-M33 port (community-supported, NTZ variant), single-core.
Heap scheme: `heap_4` (`ucHeap[configTOTAL_HEAP_SIZE]` in `.bss`).

| Task | Priority | Stack | Period / Event | Responsibility |
|---|---|---|---|---|
| `UITask` | 4 (high) | 8 KB | 5 ms tick (LVGL) | LVGL `lv_timer_handler()` + input dispatch |
| `IPCRxTask` | 5 (top)  | 2 KB | FIFO IRQ notify | Drain DATA + LOG rings, route to Models |
| `KeypadScan` | 3 | 1 KB | 8 ms tick | Read PIO scan result, debounce, enqueue |
| `SensorsTask`  | 2 | 2 KB | 50 ms tick | Poll IMU/mag/baro, update model |
| `GPSTask` | 2 | 2 KB | I2C IRQ / 100 ms | Read Teseo, write `IpcGpsBuf` |
| `PowerTask` | 2 | 1.5 KB  | 1 s tick | Poll BQ25622 + BQ27441, run power FSM |
| `USBTask` | 3 | 2 KB | TinyUSB callback | Serve CDC#0 — Meshtastic console + bridged CLI |
| `UsbCtrlTask`  | 3 | 2.5 KB  | CDC#1 RX | Serve CDC#1 — Control Protocol (§4.7) |
| `IMETask` | 3 | 4 KB | Keypad event | Run MIE FSM on input chord |
| `IdleHook` | 0 | — | idle | Feed watchdog, enter WFI |

`UsbCtrlTask` is linked only when `MOKYA_ENABLE_USB_CONTROL` is set; its
TinyUSB descriptor entry is added conditionally by the same flag. See §4.7
for the full gate design.

`UITask` holds the LVGL mutex. All HAL→UI data pushes go through FreeRTOS queues drained by
`UITask`; no other task directly touches LVGL objects.

### 4.3 Display path

Single full-screen framebuffer (240×320×RGB565 = 150 KB) in SRAM, LVGL in
`LV_DISPLAY_RENDER_MODE_DIRECT`. LVGL redraws dirty rectangles; DMA pushes dirty rects to
the NHD 2.4″ LCD via PIO 8080. Target 60–80 FPS. PSRAM is explicitly avoided for display
(see §2.3).

### 4.4 Input path

PIO1 program scans the 6×6 keypad matrix with SDM03U40 Schottky diodes (NKRO), DMA copies
the 6-byte column state into a ring buffer. `KeypadScan` task debounces (20 ms), translates
the matrix (row, col) through `firmware/core1/src/keymap_matrix.h` into a keycode defined
in `firmware/mie/include/mie/keycode.h`, and enqueues a `key_event_t` into the shared
KeyEvent queue consumed by `IMETask` (in IME mode) or `UITask` (in UI-navigation mode).

```c
typedef enum {
    KEY_SOURCE_HW     = 0,   // PIO1 scan via KeypadScan
    KEY_SOURCE_INJECT = 1,   // CDC#1 Control Protocol via UsbCtrlTask (§4.7)
} key_source_t;

typedef struct {
    uint8_t       keycode;     // value from mie/keycode.h, 0x01..0x3F
    uint8_t       pressed : 1;
    key_source_t  source  : 1;
    uint8_t       flags   : 6; // reserved — long-press hint, future use
} key_event_t;
```

The queue is **multi-producer**: `KeypadScan` pushes HW events, `UsbCtrlTask`
pushes INJECT events. Arbitration rule — if HW and INJECT arrive for the same
keycode within the debounce window, HW wins and INJECT returns `ERR_BUSY` to
the host. Once past the queue, both sources are indistinguishable to `IMETask`
/ `UITask` except via the `source` field, which is read for breadcrumb tagging
and for safe-mode rejection (§9.4).

Matrix geometry (6×6) exists only inside `KeypadScan` and `keymap_matrix.h`.
Every layer above the queue — MIE, UI, Control Protocol, host tooling — sees
only keycodes. Adding a non-matrix key (power button, future side button) means
adding a constant to `keycode.h` and an enqueue site; no other layer changes.

### 4.5 Power FSM

```
  ACTIVE ── 60 s no key ──► IDLE (LCD off, IMU WoM armed) ── WoM ──► ACTIVE
    │                         │
    │                         └── 5 min no wake ──► SLEEP (radio low duty,
    │                                                      sensors suspended)
    └── user hold PWR 3 s ──► SHIPPING (all off, BQ25622 ship mode)
```

`IPC_CMD_POWER_STATE` notifies Core 0 whenever the FSM transitions; Core 0 adjusts
transmit cadence + sleep behaviour accordingly.

### 4.6 USB Modes — OFF vs COMM (composite CDC)

Per `software-requirements.md` §1 and §6, the device presents two USB modes
selected by the user on VBUS insertion. Both modes live on Core 1 (Core 0
never touches USB — `-D NO_USB` strips it from the Arduino-Pico build).

| Mode | TinyUSB | Host view | Interfaces |
|---|---|---|---|
| OFF  | dormant | dumb charging sink | Charger manages VBUS only — no enumeration |
| COMM | running | composite device: **two** virtual COM ports | CDC#0 Meshtastic bridge + CDC#1 Control (§4.7) |

COMM is the only TinyUSB-enabled mode. CDC#0 and CDC#1 enumerate together —
there is no "Serial only" or "Control only" sub-mode. Reasons:

- Composite CDC is stable in TinyUSB; adding CDC#1 is one descriptor entry,
  not a mode-switch state machine.
- The two interfaces have independent framings (CDC#0 transparent Meshtastic
  bytes; CDC#1 SLIP+COBS) and independent handlers (`USBTask` vs
  `UsbCtrlTask`). A host opens whichever COM port it needs; the other stays
  idle without any device-side coordination.
- Build flag `MOKYA_ENABLE_USB_CONTROL=OFF` drops CDC#1 entirely from the
  descriptor so a certified shipment sees a single-CDC device. No runtime
  branching.

**Mode selection on VBUS insert (GPIO 1 IRQ):**

```
  VBUS IRQ ──► PowerTask reads settings key IPC_CFG_USB_MODE (M5+) or fallback default
    ├─ "Always charge-only"  → Mode OFF:  leave TinyUSB uninitialised; BQ25622 handles VBUS
    ├─ "Always data"         → Mode COMM: call tud_init(); USBTask + UsbCtrlTask resumed
    └─ "Ask every time"      → Show 3 s LVGL pop-up; OK defaults per pairing history
```

**Runtime switch OFF ↔ COMM (Settings → USB Mode):**

- OFF → COMM: call `tud_init(BOARD_TUD_RHPORT)`; resume `USBTask` and
  `UsbCtrlTask`. Host sees the composite device enumerate within ~2 s.
- COMM → OFF: flush both CDC TX queues; call `tud_disconnect()`; suspend
  both USB tasks. Host sees both COM ports disappear within ~300 ms.

**CDC#0 byte-bridge data flow (COMM steady state):**

```
  PC ──► (CDC#0 OUT) ──► TinyUSB ── CDC#0 RX queue ──► USBTask
          → ipc_ring_push(CMD, IPC_MSG_SERIAL_BYTES, payload≤256)
          → SIO doorbell ──► Core 0 SerialConsole hook consumes bytes
                             drives Meshtastic admin CLI
  Core 0 ──► IPC_MSG_SERIAL_BYTES (DATA) ──► USBTask → CDC#0 IN ──► PC
```

The 256 B slot size matches `IPC_MSG_PAYLOAD_MAX` and allows TinyUSB's 64 B packets to
batch into a single IPC slot, which is the throughput optimization from M1 Part B.

**CDC#1 Control data flow:** see §4.7.

**Relationship to safe mode (§9.4):** safe mode forces **Mode COMM** regardless of setting.
When the device cannot boot normally, the PC is the only recovery surface; charge-only
would strand the user. Within COMM, CDC#1 Control rejects all state-mutating commands
while in safe mode (see §9.4 and Control Protocol §8.3).

### 4.7 USB Control Protocol (CDC#1)

CDC#1 exposes a host-driven control channel used for automated testing,
remote debugging, and development tooling. This section summarises the
integration surface; the wire protocol, command catalogue, ACK semantics,
framing (SLIP+COBS), and HMAC-SHA256 authentication are normatively defined
in [`usb-control-protocol.md`](usb-control-protocol.md).

**Ownership:** `UsbCtrlTask` (FreeRTOS task, priority 3, 2.5 KB stack) owns
the CDC#1 endpoints. It shares nothing with `USBTask` except the TinyUSB
device stack; each task drains its own CDC RX queue.

**Gates (both must be open):**

1. **Build flag** `MOKYA_ENABLE_USB_CONTROL`. Default ON for all current builds
   (no CE/FCC submission planned). OFF drops CDC#1 descriptor and `UsbCtrlTask`
   at link time.
2. **Runtime flag** `settings.usb_control_enabled`. Default OFF at every boot.
   User opens it via Settings UI or via a pre-authorised remote-unlock signed
   by the pairing key (supports remote-debug when the device is not
   physically reachable).

**Injection path (happy case):**

```
  Host ──► (CDC#1 OUT, SLIP+COBS frame) ──► TinyUSB ── CDC#1 RX queue ──► UsbCtrlTask
    ├─ HMAC-authenticate (HELLO/AUTH handshake)
    ├─ parse opcode → validate payload
    ├─ KEY/UI_CMD: enqueue key_event_t{source=INJECT} into KeyEvent queue (§4.4)
    ├─ TYPE:       synthesise commit events to focused text widget
    ├─ SCREEN:     copy framebuffer under LVGL mutex → async stream fragments
    └─ UI_STATE/LOG_TAIL/EVENT_SUB: immediate read-only response

  (after effect observable) ──► build ACK frame ──► (CDC#1 IN) ──► Host
```

**Arbitration with hardware keypad:** HW events win for the same keycode
within the 20 ms debounce window; INJECT events losing arbitration are
dropped with `ERR_BUSY` returned to the host. See §4.4 for the queue
structure and §9.3 for breadcrumb tagging of INJECT events.

**No IPC involvement.** CDC#1 is entirely a Core 1 concern. The Control
Protocol never crosses the IPC boundary; neither `ipc_protocol.h` nor Core 0
know it exists.

---

## 5. Shared IPC — 24 KB Byte Map

All offsets are relative to `0x2007A000`. The layout is declared once in
`firmware/shared/ipc/ipc_shared_layout.h` and both ELF images place a `.shared_ipc` section
at this exact address (NOLOAD).

| Offset | Size | Field | Notes |
|---|---|---|---|
| `0x0000` | 16 B | Handshake | `boot_magic = "MOKY"`, `c0_ready`, `c1_ready`, `flash_lock` |
| `0x0010` | 16 B | `_pad` | alignment to 0x20 |
| `0x0020` | 32 B | `c0_to_c1_ctrl` | DATA ring control (head/tail/stats) |
| `0x0040` | 32 B | `c0_log_to_c1_ctrl` | LOG  ring control |
| `0x0060` | 32 B | `c1_to_c0_ctrl` | CMD  ring control |
| `0x0080` | 8,448 B  | `c0_to_c1_slots[32]` | 32 × 264 B — protobuf frames |
| `0x2180` | 4,224 B  | `c0_log_to_c1_slots[16]` | 16 × 264 B — log lines (best-effort) |
| `0x3200` | 8,448 B  | `c1_to_c0_slots[32]` | 32 × 264 B — host commands |
| `0x5300` | 260 B | `gps_buf` | NMEA double-buffer (see §5.3) |
| `0x5404` | 3,068 B  | `_tail_pad` | reserved — breadcrumbs at `0x5FC0` (64 B) |
| **Total**  | **24 KB**| | |

### 5.1 Three rings — why three, and slot counts

Core 0's `writeStream()` loop on a `want_config_id` interleaves ~40 protobuf frames with
`LOG_DEBUG/LOG_INFO` lines. On a single ring the log bytes consume slots that the protobuf
stream needs, creating 12–49 ms per-frame gaps. Splitting into three rings:

- **`c0_to_c1` (DATA, 32 slots, blocking on full)** — protobuf only. Producer blocks if
  full; consumer (Core 1 `IPCRxTask`) drains with priority.
- **`c0_log_to_c1` (LOG, 16 slots, best-effort)** — `IPC_MSG_LOG_LINE` only.
  **If the ring is full, the producer drops the line rather than blocking.** Prevents log
  starvation of the data path.
- **`c1_to_c0` (CMD, 32 slots)** — commands from Core 1 (send text, set config, etc.).

Each slot is an `IpcRingSlot` of 264 bytes: `IpcMsgHeader` (4 B) + `uint8_t payload[256]` +
4 B ring metadata.

### 5.2 Message catalogue — direction and owner

Enumerated in `firmware/shared/ipc/ipc_protocol.h`. **Direction** indicates the producer.

| ID | Name | Dir | Ring  | Purpose |
|---|---|---|---|---|
| `0x01` | `IPC_MSG_RX_TEXT` | C0→C1 | DATA  | Incoming text message received |
| `0x02` | `IPC_MSG_NODE_UPDATE`  | C0→C1 | DATA  | Node list entry added/updated |
| `0x03` | `IPC_MSG_DEVICE_STATUS`| C0→C1 | DATA  | Periodic status (batt, GPS, RSSI, uptime)  |
| `0x04` | `IPC_MSG_TX_ACK` | C0→C1 | DATA  | Tx ACK (sending/delivered/failed) |
| `0x05` | `IPC_MSG_CHANNEL_UPDATE`| C0→C1| DATA  | Channel config changed |
| `0x06` | `IPC_MSG_SERIAL_BYTES` | C0→C1 | DATA  | Raw CLI bytes (M1 byte bridge) |
| `0x07` | `IPC_MSG_CONFIG_VALUE` | C0→C1 | DATA  | Config get reply / unsolicited push |
| `0x08` | `IPC_MSG_CONFIG_RESULT`| C0→C1 | DATA  | Config set/commit OK/err |
| `0x09` | `IPC_MSG_REBOOT_NOTIFY`| C0→C1 | DATA  | Core 0 about to reboot — detach USB |
| `0x81` | `IPC_CMD_SEND_TEXT` | C1→C0 | CMD | Send text message |
| `0x82` | `IPC_CMD_SET_CHANNEL`  | C1→C0 | CMD | Set active channel |
| `0x83` | `IPC_CMD_SET_TX_POWER` | C1→C0 | CMD | LoRa TX power (dBm) |
| `0x84` | `IPC_CMD_REQUEST_STATUS`| C1→C0| CMD | Immediate DEVICE_STATUS push |
| `0x85` | `IPC_CMD_SET_NODE_ALIAS`| C1→C0| CMD | Assign user alias to node ID |
| `0x86` | `IPC_CMD_POWER_STATE`  | C1→C0 | CMD | Notify power FSM transition |
| `0x87` | `IPC_CMD_REBOOT` | C1→C0 | CMD | Request reboot |
| `0x88` | `IPC_CMD_FACTORY_RESET`| C1→C0 | CMD | Wipe persistent config |
| `0x89` | `IPC_CMD_GET_CONFIG` | C1→C0 | CMD | Request config value by key |
| `0x8A` | `IPC_CMD_SET_CONFIG` | C1→C0 | CMD | Set config value by key |
| `0x8B` | `IPC_CMD_COMMIT_CONFIG`| C1→C0 | CMD | Commit pending (save + reboot if needed) |
| `0xF0` | `IPC_MSG_LOG_LINE` | both  | LOG | Debug log, best-effort |
| `0xFE` | `IPC_MSG_PANIC` | both  | LOG | Cross-core panic notification (M6) |
| `0xFF` | `IPC_BOOT_READY` | both  | — | Handshake (also written to shared region)  |

### 5.3 Ring API

```c
bool ipc_ring_push(IpcRingCtrl *ctrl, IpcRingSlot *slots,
                   uint32_t slot_count,      // 32 for data/cmd, 16 for log
                   uint8_t msg_id, uint8_t seq,
                   const void *payload, uint16_t payload_len);

bool ipc_ring_pop (IpcRingCtrl *ctrl, IpcRingSlot *slots,
                   uint32_t slot_count,
                   IpcRingSlot *out);
```

The `slot_count` parameter lets one implementation serve all three rings.

### 5.4 GPS double-buffer (out-of-band, not a ring)

`IpcGpsBuf` at `0x5300`: `uint8_t buf[2][128]` + a single-byte `write_idx` (0 or 1) that
the writer (Core 1 `GPSTask`) flips atomically after a full NMEA sentence is committed. The
reader (Core 0 `PositionModule`) always reads `buf[write_idx ^ 1]`, so producer and consumer
never touch the same slot. No locking, no doorbell needed — the `write_idx` flip *is* the
signal.

### 5.5 End-to-end flows

**A. Sending a text from UI → LoRa air** (C1 → C0, polled in M2, doorbell in M5):

```
  User types in IMEBar ──► MIE emits UTF-8
    ──► MessagesApp.send()
        ──► IpcClient.sendText(to, chan, text)
             ipc_ring_push(CMD, IPC_CMD_SEND_TEXT, IpcPayloadText)
             [M5: doorbell_set_other_core(IPC_DOORBELL_NUM)]
                                                              ▼
  M2 now:   Core 0 SerialConsole::runOnce() polls every 5 ms (OSThread tick)
  M5 plan:  Core 0 SIO_IRQ_BELL ──► IPCPhoneAPI wakes instantly
    ──► PhoneAPI.handleToRadio(ToRadio{...SendText})
        ──► MeshService.sendToMesh()
            ──► Router.send()
                ──► SX126xInterface.send() ──► SPI1 ──► SX1262 air
  Core 0: on tx complete, IPC_MSG_TX_ACK ──► DATA ring ──► UI toast
```

**B. Incoming text from LoRa → UI** (C0 → C1, doorbell-driven in M2):

```
  SX1262 RX IRQ ──► SX126xInterface.handleDio1()
    ──► Router.receive() ──► TextMessageModule.handleReceived()
        ──► IPCPhoneAPI.sendOnToRadio(ToRadio{FromRadio{RxText}})
             ipc_ring_push(DATA, IPC_MSG_RX_TEXT)
             doorbell_set_other_core(IPC_DOORBELL_NUM) ──────┐
                                                             ▼
  Core 1 SIO_IRQ_BELL ──► ipc_doorbell_isr
    ──► xTaskNotifyFromISR(bridge_task / IPCRxTask in M4+)
        ──► ipc_ring_pop(DATA) ──► MessageModel.append()
            ──► xQueueSend(UIQueue)
                ──► UITask drains ──► LVGL redraw ──► LCD DMA
```

**C. GPS NMEA pipe (no ring involved):**

```
  Core 1 GPSTask (100 ms):
    i2c1 read from Teseo 0x3A ──► NMEA parser
    on full sentence:
      idx = g_gps.write_idx ^ 1
      memcpy(g_gps.buf[idx], sentence, len)
      g_gps.len[idx] = len
      __dmb()
      g_gps.write_idx = idx      // commit

  Core 0 PositionModule runOnce (1 s):
    idx = g_gps.write_idx ^ 1
    parse g_gps.buf[idx] ──► Position protobuf
    emit via mesh + IpcPhoneAPI
```

**D. Config read/write round trip (M4+):**

```
  SettingsApp.read(KEY)
    ──► IpcClient.getConfig(KEY)
        ipc_ring_push(CMD, IPC_CMD_GET_CONFIG, {key})
                                                ▼
  Core 0 ConfigAdapter (IPCPhoneAPI extension):
    translate IPC key ──► AdminModule get-config
    reply IPC_MSG_CONFIG_VALUE ──► DATA ring
                                                ▼
  Core 1 IPCRxTask ──► ConfigModel.update(key, bytes)
    ──► SettingsApp refreshes widget
```

### 5.6 Doorbell mechanism

RP2350 SIO **doorbell registers** (`SIO_DOORBELL_OUT_SET` / `SIO_DOORBELL_IN_*`) are
used as per-core notification bits, **not** the inter-core FIFO — the FIFO is reserved
for the bootrom `multicore_launch_core1_raw` handshake and re-using it would conflict.
Payload data always travels through shared SRAM; doorbells carry only "ring has data"
and "park request" signals.

Doorbell bit allocation (`IPC_DOORBELL_NUM = 0`, `IPC_FLASH_DOORBELL = 1`):

| Bit | Direction | Purpose | ISR owner |
|-----|---|---|---|
| 0 | C0 → C1 | Ring slot pushed — wake `bridge_task` | Core 1 |
| 0 | C1 → C0 | Ring slot pushed — *currently unused; polled* | (M5 — see below) |
| 1 | C0 → C1 | Flash-park request (P2-11 safety) | Core 1 |

**Current M2 asymmetry:** Only Core 1 has a doorbell ISR. Core 1 → Core 0 ring-push
notification is not wired — Core 0 still discovers incoming CMD traffic via
`SerialConsole::runOnce()` polling on its 5 ms OSThread tick. Upgrading Core 0 to a
doorbell ISR is deferred to M5, when `IPCPhoneAPI` replaces `SerialConsole` as the
Core 0 IPC receive path.

Notes:
- `SIO_IRQ_BELL` is shared across all doorbell bits — the ISR must clear only the bits
  it owns and leave others set (see `project_sio_irq_bell_shared` memory).
- During flash write (P2-11 fix), Core 1 parks on a RAM-resident busy loop, disables
  all interrupts, and WFE-spins until `flash_lock` clears; the park is signalled via
  `IPC_FLASH_DOORBELL` bit 1 before Core 0 disables interrupts.
- The Arduino-Pico FreeRTOS port's own `prvDoorbellInterruptHandler` is disabled by
  `MOKYA_DOORBELL_PATCH` — see §6.8.

### 5.7 MIE user-dictionary persistence (planned, M5+)

SRS §5.4 requires the MIE smart-correction layer to persist learned per-user weights
so that frequently-used candidates promote on repeat sessions. LittleFS lives in flash
region `0x10C00000 – 0x10FFFFFF` (§2.1) and is owned exclusively by Core 0 under the
single-writer flash-safety discipline (§6.7). MIE runs on Core 1, so every user-dict
write must tunnel through IPC.

**Proposed message additions (reserved IDs, pending implementation at M5):**

| ID | Name | Dir | Ring  | Payload |
|---|---|---|---|---|
| `0x0A` | `IPC_MSG_USER_DICT_ACK` | C0→C1 | DATA  | `uint16_t chunk_id`, `uint8_t result` |
| `0x0B` | `IPC_MSG_USER_DICT_CHUNK` | C0→C1 | DATA  | boot-time streaming of stored user-dict entries to Core 1 |
| `0x8C` | `IPC_CMD_USER_DICT_PUT` | C1→C0 | CMD | `uint16_t chunk_id` + up to 240 B of serialised `(key_hash32, delta_i16)` tuples |
| `0x8D` | `IPC_CMD_USER_DICT_COMMIT` | C1→C0 | CMD | Empty — flush outstanding chunks to flash |
| `0x8E` | `IPC_CMD_USER_DICT_LOAD` | C1→C0 | CMD | Empty — request full-file stream at boot  |

The IDs `0x0A`, `0x0B`, `0x8C`..`0x8E` are currently unused in `IpcMsgId`; they will be
reserved in `ipc_protocol.h` at M5 kickoff.

**Flow — online learning:**

```
Core 1 IMETask accumulates dirty weights (candidate commits promoting tier)
  ──► dirty_count > 32  OR  idle ≥ 30 s:
        serialise as (key_hash32, delta_i16) tuples (6 B each)
        split into ≤ 240 B chunks (~40 tuples per chunk)
        for each chunk_id: ipc_ring_push(CMD, IPC_CMD_USER_DICT_PUT, ...)
        last chunk followed by ipc_ring_push(CMD, IPC_CMD_USER_DICT_COMMIT)
Core 0 UserDictStore handler:
  LittleFS open "/mie/user.dict" (append mode)
  for each received chunk: decode tuples, append log record
  on COMMIT: fsync via flash_safety_wrap
  reply IPC_MSG_USER_DICT_ACK{chunk_id, result} per chunk (DATA ring)
Core 1 on ERR ACK: retry once; on second failure emit toast + stop learning
  until next boot (writes dropped rather than blocking IME).
```

**Flow — boot-time reload:**

```
Core 1 boot (after c0_ready + c1_ready):
  IMETask → ipc_ring_push(CMD, IPC_CMD_USER_DICT_LOAD)
Core 0:
  read "/mie/user.dict" record-by-record;
  batch records into ≤ 240 B IPC_MSG_USER_DICT_CHUNK frames;
  final chunk has a sentinel flag (high bit of chunk_id)
Core 1 applies each record as a live weight overlay on the PSRAM dict.
```

**Storage format (`/mie/user.dict`):**

- Append-only log of 6-byte records: `uint32 key_hash + int16 delta_weight`.
- File is rewritten (compacted) as a deduplicated snapshot every 1024 records, or when
  the file exceeds 128 KB. Compaction runs entirely on Core 0 during an idle window.

**Why not let Core 1 write flash directly?**
P2-11 discipline requires a "park other core + disable IRQ" dance around every
`flash_range_erase` / `flash_range_program` (XIP is off while flash is writing). Having
a single flash writer keeps the protocol one-way and simple. Two-way flash ownership
would require each core to park the other, which doubles the complexity and introduces
a possible live-lock surface.

---

## 6. Cross-Image Non-Interference

Two independently-linked ELF images share the chip. The following mechanisms guarantee
they cannot corrupt each other's memory at compile-time, link-time, boot-time, or runtime.

### 6.1 Link-time — matching NOLOAD region + nm verification

Both `patch_arduinopico.py` (Core 0) and `memmap_core1_bridge.ld` (Core 1) declare the
identical `SHARED_IPC` MEMORY region:

```
SHARED_IPC (rw) : ORIGIN = 0x2007A000, LENGTH = 24K
```

Both emit `.shared_ipc (NOLOAD)` at `0x2007A000`. Post-link CI check: `nm` both ELFs and
assert `g_ipc_shared` resolves to the identical address. Any layout drift between the two
headers becomes a build-break, not a silent memory stomp.

### 6.2 Boot model — no IMAGE_DEF on Core 1

Core 1's linker script `/DISCARD/`s `.embedded_block`, `.embedded_end_block`, `.boot2`, and
`.binary_info_header`. Core 1's image therefore has **no IMAGE_DEF header** at word 0;
instead, the first two flash words are the M33 vector table — `SP = __StackTop`,
`PC = mokya_core1_reset_handler` (Thumb bit set).

Core 0 boots Core 1 with `multicore_launch_core1_raw(pc, sp, vtor)`, which reads SP and PC
directly from those two flash words. If Core 1 ever regained an IMAGE_DEF block it would
overwrite word 0 with `0xffffded3` and instantly fault on launch.

Core 1's SDK runtime_init hooks are also selectively disabled so Core 1 doesn't re-init
clocks or resets that Core 0 already owns:

```
PICO_RUNTIME_SKIP_INIT_CLOCKS=1
PICO_RUNTIME_SKIP_INIT_EARLY_RESETS=1
PICO_RUNTIME_SKIP_INIT_POST_CLOCK_RESETS=1
PICO_RUNTIME_SKIP_INIT_SPIN_LOCKS_RESET=1
PICO_RUNTIME_SKIP_INIT_BOOT_LOCKS_RESET=1
PICO_RUNTIME_SKIP_INIT_BOOTROM_LOCKING_ENABLE=1
PICO_RUNTIME_SKIP_INIT_USB_POWER_DOWN=1
```

### 6.3 SRAM non-overlap

Core 0 memmap has `LENGTH = 176 KB` starting at `0x20000000`. Core 1 memmap has
`LENGTH = 312 KB` starting at `0x2002C000`. Regions are back-to-back, zero gap, zero
overlap. The Core 1 linker asserts `__StackLimit >= __HeapLimit` inside its region. Core 1
never places data in `SCRATCH_X`/`SCRATCH_Y`; those 8 KB belong to Core 0.

### 6.4 Ring ownership — SPSC partition

Each SPSC ring is strictly single-producer, single-consumer:

- **`head`** is written only by the producer. Consumer reads it.
- **`tail`** is written only by the consumer. Producer reads it.
- **`slots[i]`** is owned by the producer while `(head - tail) < slot_count`; ownership
  transfers to the consumer when the producer publishes `head++`.

No shared mutable state is written by both sides. No spinlock, no atomic RMW.

### 6.5 Memory ordering

Every `head`/`tail` publish is surrounded by `__dmb()`:

- Producer: write `slots[head % N]` → `__dmb()` → `head++` → `__dmb()` → FIFO push.
- Consumer: read FIFO → `__dmb()` → read `head` → read `slots[tail % N]` → `__dmb()` →
  `tail++`.

### 6.6 GPS double-buffer atomicity

`write_idx` is a single `uint8_t` — reads and writes are naturally atomic on Cortex-M33.
The reader always reads `buf[write_idx ^ 1]`, guaranteeing it never observes an in-progress
write.

### 6.7 Flash-write safety (P2-11 discipline)

Only Core 0 writes flash. Before every `flash_range_erase` / `flash_range_program`, Core 0:
1. Raises the "park" doorbell bit to Core 1.
2. Spins until Core 1 acks that it has entered its RAM-resident park loop.
3. Disables local IRQs.
4. Calls the real function (XIP off during this window).
5. Re-enables IRQs, releases Core 1.

See `flash_safety_wrap.c`. Core 1's park loop is in `.data` (copied to RAM at boot), so it
runs without XIP.

### 6.8 FreeRTOS doorbell-handler patch (`MOKYA_DOORBELL_PATCH`)

The Arduino-Pico FreeRTOS-Kernel port (`RP2350_ARM_NTZ`) registers
`prvDoorbellInterruptHandler` on `SIO_IRQ_BELL` at scheduler start and uses it to drive
`pico_sync`'s cross-core spin-lock blocking. That handler takes
`spin_lock_blocking(pxCrossCoreSpinLock)` on entry — when Core 1 fires our IPC doorbell,
Core 0's copy of the same handler would deadlock (or endlessly re-enter) because the lock
is held in Core 1's own critical section.

`patch_arduinopico.py` wraps the entire doorbell-registration block in `#if 0` (marker:
`MOKYA_DOORBELL_PATCH`). Our ISR (`ipc_doorbell_isr` on Core 1, planned Core 0 ISR at M5)
takes over `SIO_IRQ_BELL` exclusively.

**Consequence (design constraint):** MokyaLora **must not** use any `pico_sync` cross-core
primitive (`spin_lock_blocking`, `critical_section`, `mutex_enter_*` in blocking mode) on
objects shared between cores, because the FreeRTOS back-off path is gone. Safe because our
IPC uses SPSC rings + doorbell, never lock-based sharing.

---

## 7. Bus & Peripheral Ownership

Each peripheral has exactly one owner. No register of a foreign-owned peripheral is ever
read or written across the IPC boundary.

| Bus / Peripheral | Owner  | Devices / Pins |
|---|---|---|
| Sensor + GNSS bus (GPIO 34/35, `i2c1`) | Core 1 | LSM6DSV16X 0x6A · LIS2MDL 0x1E · LPS22HH 0x5D · Teseo 0x3A |
| Power bus (GPIO 6/7, `i2c1`) | Core 1 | BQ25622 0x6B · BQ27441 0x55 · LM27965 0x36 |
| SPI1 (GPIO 24–27) | Core 0 | SX1262 LoRa |
| PIO0 | Core 1 | 6×6 keypad matrix (GPIO 36–47), continuous PIO+DMA scan |
| PIO1 | Core 1 | LCD 8-bit 8080 parallel, NHD-2.4″ |
| PWM | Core 1 | Haptic motor (GPIO 9) |
| USB CDC | Core 1 | TinyUSB device — console + bridged CLI |
| Flash (QMI / XIP) | shared | XIP read both cores; writes only Core 0 |
| PSRAM (QMI / XIP) | Core 1 | read only; bump-allocator heap + dict assets |

Note (Rev A): both buses map to the `i2c1` SDK peripheral — GPIO 6/7 and GPIO 34/35 are
I2C1-only on RP2350 (mod-4 = 2/3 rule; no I2C0 pinmux alternative on either pair).
Firmware time-multiplexes `i2c1` between the two pin pairs via a FreeRTOS mutex —
drivers use `firmware/core1/src/i2c/i2c_bus.c` (`i2c_bus_acquire` /
`i2c_bus_release`). Rev B should reroute the sensor bus to a mod-4 = 0/1 GPIO pair
(e.g. 32/33) so `i2c0` and `i2c1` can run concurrently — see
`docs/design-notes/mcu-gpio-allocation.md` for the full rationale.

---

## 8. Build System & Toolchain Isolation

The dual-licence boundary is reinforced by using **two separate build tools**: Core 0 uses
PlatformIO (to stay on the same toolchain as upstream Meshtastic), Core 1 uses CMake+Ninja
(to track the Pico SDK directly without Arduino-Pico). Neither build can accidentally link
the other's objects.

### 8.1 Core 0 build — PlatformIO

Config: `firmware/core0/meshtastic/variants/rp2350/rp2350b-mokya/platformio.ini`.

- Extends `rp2350_base` (upstream Meshtastic RP2350 variant).
- Pre-scripts:
  - `patch_arduinopico.py` — applies the five framework patches (see §3.2). Idempotent;
    CI re-runs safely.
  - `wire_shared_ipc.py` — injects the `.shared_ipc` NOLOAD region into the Arduino-Pico
    default linker script at build time.
- Injects `-D NO_USB` + `-D configNUMBER_OF_CORES=1`, adds the `MESHTASTIC_EXCLUDE_*`
  trim list.
- Wraps flash functions: `-Wl,--wrap=flash_range_erase -Wl,--wrap=flash_range_program`.
- `lib_ignore`s `BluetoothOTA`, `lvgl`, `SdFat`, `SD` — none belong on Core 0.
- Output: `firmware/core0/meshtastic/.pio/build/rp2350b-mokya/firmware.elf` — flashed at
  `0x10000000`.

### 8.2 Core 1 build — CMake + Ninja

Config: `firmware/core1/m1_bridge/CMakeLists.txt`.

- `PICO_PLATFORM=rp2350-arm-s`, `PICO_BOARD=pico2` (closest match for RP2350B).
- Pulls in FreeRTOS-Kernel + `RP2350_ARM_NTZ` community port as subdirectory.
- Linker script override: `pico_set_linker_script(core1_bridge memmap_core1_bridge.ld)`.
- `pico_add_extra_outputs()` is **not** called (would invoke picotool and need IMAGE_DEF).
  Instead a POST_BUILD custom command `objcopy -O binary` produces
  `build/core1_bridge/core1_bridge.bin` — flashed raw at `0x10200000`.
- `core1_reset.S` is listed **first** in `add_executable()` so its `.vectors` input section
  lands at offset 0 of the output `.text`. The linker script `KEEP (*core1_reset.S.obj(.vectors))`
  belts-and-braces this.
- Compile defs disable SDK runtime_init hooks that would fight Core 0 for hardware state
  (see §6.2 list).
- Libraries: `pico_stdlib`, `hardware_resets`, `hardware_irq`, `hardware_sync`,
  `hardware_exception`, `tinyusb_device`, `FreeRTOS-Kernel`, `FreeRTOS-Kernel-Heap4`.
  **Not** linked: `pico_multicore` — doorbell uses raw SIO register writes to avoid
  multicore init side-effects.

### 8.3 Why Core 0 ships as ELF but Core 1 ships as raw `.bin`

The two images use different flash-load artefacts. This asymmetry is deliberate and
follows from the boot model, not a build-system quirk.

**Semantic — Core 1 is not a bootable Pico image.**
Core 0 boots via the RP2350 bootrom, which validates an IMAGE_DEF block at `0x10000000`.
ELF is the natural format: program headers carry the load address, and the IMAGE_DEF lives
inside a regular `.text` input section.

Core 1's linker script `/DISCARD/`s `.embedded_block` / `.binary_info_header` / `.boot2`
(§6.2). If Core 1 carried an IMAGE_DEF, its magic word would overwrite word 0 of the image
— but word 0 must be `SP = __StackTop` for `multicore_launch_core1_raw()` to read. So
Core 1 is semantically **a payload blob at a fixed offset**, not a bootable image. Using
`.bin` reflects that — there is no header, no metadata, just bytes destined for
`0x10200000`.

**Tooling — picotool needs IMAGE_DEF, which Core 1 has explicitly removed.**
`pico_add_extra_outputs()` would normally emit `.uf2` via picotool, but picotool refuses
to process an image without IMAGE_DEF. The CMakeLists therefore skips that call and runs
`objcopy -O binary` in a POST_BUILD step to produce `core1_bridge.bin` directly. Downstream
UF2 conversion (`picotool uf2 convert --offset 0x10200000`, §10.2) takes the `.bin` plus
an explicit offset — bypassing IMAGE_DEF inference entirely.

**Operational — explicit address is auditable.**
J-Link's `loadbin core1_bridge.bin 0x10200000` writes the load address on the same line as
the file. Using `loadfile core1_bridge.elf` would technically work (J-Link reads program
headers) but the address would be buried inside the linker script. For an image whose
load-bearing property **is** its offset, surfacing the offset in the flash command makes
mistakes harder.

**Core 1 ELF still exists.**
`build/core1_bridge/core1_bridge.elf` is produced by the linker and retained for
**debugging only** (GDB symbol load, SWD source-level stepping, `nm` for the
`g_ipc_shared` coherency check in §6.1 / §11.5). It is never written to flash.

Summary table:

| Artefact | Flash? | Purpose |
|---|---|---|
| `firmware.elf` (Core 0)  | yes | J-Link `loadfile`, debug symbols, UF2 source |
| `firmware.uf2` (Core 0)  | yes (BOOTSEL) | End-user drag-drop install |
| `core1_bridge.elf` | **no** | Debug symbols, `nm` coherency checks only |
| `core1_bridge.bin` | yes | J-Link `loadbin 0x10200000`, UF2 source (raw bytes)  |
| `core1.uf2` | yes (BOOTSEL) | Produced from `.bin` + explicit `--offset` |

### 8.4 Licence boundary enforcement at build

| Rule | Enforced by |
|---|---|
| Core 1 cannot `#include` any Meshtastic header | Separate include paths; no Meshtastic path in CMake |
| `firmware/shared/ipc/` may only `#include <stdint.h>` / `<stddef.h>` | Code review + compile (`ipc_protocol.h` is checked) |
| Core 0 cannot link Core 1 objects | PlatformIO `build_src_filter` excludes `firmware/core1/`|
| Core 1 cannot link Core 0 objects | CMake `add_executable()` list is explicit |
| `nm g_ipc_shared` must match on both ELFs | CI post-link check |
| Layout drift in `ipc_shared_layout.h` breaks both builds | Single source of truth for offsets |

### 8.5 Dual-image build + flash (`scripts/build_and_flash.sh`)

```
  ┌─ Core 0 ─────────────────────────────────────────────────────────┐
  │ python -m platformio run -e rp2350b-mokya                        │
  │   -d firmware/core0/meshtastic                                   │
  │ → firmware.elf  (flash at 0x10000000)                            │
  └──────────────────────────────────────────────────────────────────┘
  ┌─ Core 1 ─────────────────────────────────────────────────────────┐
  │ cmake --build build/core1_bridge                                 │
  │ → core1_bridge.bin  (flash at 0x10200000)                        │
  └──────────────────────────────────────────────────────────────────┘
  ┌─ Flash via J-Link ───────────────────────────────────────────────┐
  │ JLink.exe -device RP2350_M33_0 -if SWD -speed 4000 \             │
  │   -CommanderScript <<EOF                                         │
  │     connect                                                      │
  │     r                                                            │
  │     loadfile  firmware.elf                                       │
  │     loadbin   core1_bridge.bin 0x10200000                        │
  │     r                                                            │
  │     g                                                            │
  │     qc                                                           │
  │   EOF                                                            │
  └──────────────────────────────────────────────────────────────────┘
```

Variants:

- `bash scripts/build_and_flash.sh` — full dual rebuild + flash both slots.
- `bash scripts/build_and_flash.sh --core1` — skip PlatformIO, rebuild + flash Core 1 only.
  Used when iterating on UI / IME / HAL without touching Meshtastic. ~4× faster.
- Core 0 only — run `pio run` directly and `loadfile firmware.elf` by hand.

After flash, USB CDC needs ~3 s to re-enumerate before `python -m meshtastic --port COMxx
--info` will succeed.

### 8.6 Core 1 CMake configure (one-time)

```
PICO_SDK_PATH=/c/pico-sdk cmake -S firmware/core1/m1_bridge \
    -B build/core1_bridge -G Ninja
```

Requires: VS Build Tools 2019 (MSVC for CMake host tools), ARM GCC (Thumb target),
Ninja, Pico SDK at `C:\pico-sdk`, FreeRTOS-Kernel submodule initialised.

---

## 9. Boot Sequence

Two cores, two timelines — Core 0 launches Core 1 and both then race to mark themselves
ready in the shared handshake block. Time flows downward.

```
    CORE 0                                        CORE 1
    ─────────────────────────────────             ─────────────────────────────
    Power-on / reset                              (halted — no clock yet)
      │
      ▼
    Bootrom
      │ reads IMAGE_DEF at 0x10000000
      ▼
    Arduino-Pico crt0
      │ clocks · resets · QSPI XIP on
      │ .data copy · .bss clear
      ▼
    Core 0 main()
      │ (1) ipc_shared_init()
      │     — zero 24 KB, write "MOKY" magic,
      │       clear c0_ready / c1_ready
      │ (2) multicore_launch_core1_raw(
      │         pc   = word[1] @ 0x10200000,
      │         sp   = word[0] @ 0x10200000,
      │         vtor = 0x10200000 ) ───────────► Core 1 wakes
      │                                              │
      │ (3) setup() — Meshtastic init                ▼
      │     SX1262, NodeDB, LittleFS,            Core 1 crt0
      │     IPCPhoneAPI                              │ selected runtime_init_*
      │                                              │ (no clocks, no resets)
      │ (4) busy-wait on                             ▼
      │     g_ipc_shared.c1_ready                Core 1 main()
      │     (timeout 2 s → set                       │ (1) hardware_exception setup
      │      g_ipc_shared.c1_failed,                 │ (2) tusb_init() → USB CDC
      │      continue without UI)                    │ (3) ipc_client_init()
      │                                              │     install SIO_IRQ_BELL ISR
      │                    ◄──── c1_ready = 1 ──     │ (4) publish c1_ready
      │                                              │ (5) vTaskStartScheduler()
      │ (5) c0_ready = 1 ────────►                   │     preemption begins
      │                                              ▼
      ▼                                          FreeRTOS tasks running
    OSThread loop() runs Meshtastic
      ─────────────── steady state ───────────────
      Core 0 and Core 1 exchange ring frames + doorbells (§5.5)
```

### 9.1 Handshake

- `boot_magic = "MOKY"` distinguishes a warm IPC region from uninitialised SRAM. Either
  core can detect a missing magic and skip stale-ring assumptions on first boot.
- Each core writes its `*_ready` flag after its transport is fully up. Once both flags are
  set, normal IPC is permitted.
- `IPC_BOOT_READY` may additionally be pushed on the LOG ring as a human-readable marker
  for the CDC console.

### 9.2 Failure modes

| Condition | Core 0 action | User-visible effect |
|---|---|---|
| Core 1 fails to set `c1_ready` within 2 s | Set `c1_failed`; continue headless | LoRa modem runs; LCD stays off |
| `g_ipc_shared.boot_magic != "MOKY"` | Reinit shared region; re-launch Core 1 once | Transient LCD blank, recovers within ~1 s |
| Watchdog reset loop (>3 hits in 10 s) | Enter safe mode — CDC only, radio off | USB CDC responds to admin only |

### 9.3 Shared-IPC tail pad (SWD post-mortem / operational counters)

The final 64 B of the shared region (`0x2007FFC0 – 0x2007FFFF`) lives inside
`g_ipc_shared._tail_pad`, outside both cores' heaps and task stacks, so it survives a
watchdog-induced reset. It holds **operational counters** that live code keeps updated,
plus a single permanent assert tag. It is **not** a free-for-all scratchpad — every slot
must appear in the table below before code writes to it.

**Allocated slots:**

| Address | Writer | Purpose |
|---|---|---|
| `0x2007FFC4` | `main_core1_bridge.c` | `rx total` — bytes drained from `c0_to_c1` → CDC IN |
| `0x2007FFC8` | `main_core1_bridge.c` | `tx total` — bytes drained from CDC OUT → `c1_to_c0`  |
| `0x2007FFCC` | `main_core1_bridge.c` | USB state: bit0=mounted, bit1=cdc_connected (DTR) |
| `0x2007FFF8` | `lv_conf.h` `LV_ASSERT_HANDLER`| LVGL assert stamp `0xA55E1700` before spinning |

**Free:** `0x2007FFC0`, `0x2007FFD0 – 0x2007FFF4`, `0x2007FFFC` (13 × 4 B slots).

**Lifecycle discipline.** Debug breadcrumbs are discouraged by default (prefer `printf`
over CDC or SWD `mem32 <named-symbol>`). When a breadcrumb is genuinely necessary for an
investigation, it is part of the PR that introduces it and must be removed in the same
commit that lands the root-cause fix. Solved-issue breadcrumbs from P2-5/6, P3-2, P3-3,
and the M1.1-B bring-up sentinel were released in the dev-Sblzm 2026-04-18 cleanup; do
not reintroduce them. Before adding any new slot, `grep -rn "0x2007FF" firmware/` to
verify the address is free and update this table in the same diff.

**Watchdog-survive post-mortem ring (future).** Section 9.4 describes a planned 1-byte
event ring dumped by the safe-mode console after a WDT-induced reset. That ring is not
yet implemented; when it is, it will claim a documented sub-range of the free region
above and this table will be extended.

### 9.4 Watchdog Discipline & Safe Mode

Hardware: the single RP2350 watchdog runs an 8 s timeout and is fed by Core 1's
`IdleHook` (§4.2). Core 0 does not feed the WDT directly — the WDT instance is claimed
by Core 1, and any Core 1 deadlock > 8 s (UI task starving IdleHook, or a task spinning
in a critical section) resets BOTH cores via chip reset. Core 0 has its own OSThread
watchdog watchdog'd by internal heartbeats; if it deadlocks, Core 1 stops receiving IPC
frames and the LCD posts a "radio disconnected" toast within 2 s, but this does not
reset the chip.

**Boot counter — `WATCHDOG_SCRATCH[0..3]`:**

On the reset path Core 0's earliest crt0 reads the four watchdog scratch registers,
which survive a warm reset but are cleared on cold power cycle. The layout is:

| Scratch | Purpose |
|---|---|
| `[0]` | `"MOKY"` magic — if absent, treat all fields below as zero |
| `[1]` | Consecutive WDT-triggered boots (clears on clean 10 s uptime)|
| `[2]` | Reserved — last-known-good breadcrumb offset |
| `[3]` | Pending-mode flag: 0 normal, 1 OTA-BOOTSEL, 2 safe-mode-lock |

If `SCRATCH[1] ≥ 3` **or** `SCRATCH[3] == 2`, boot diverts to safe mode instead of
normal init. A clean 10 s uptime in normal mode clears `SCRATCH[1]` back to 0.

**Safe-mode service matrix:**

| Service | State in safe mode | Rationale |
|---|---|---|
| Core 0 Meshtastic stack | minimal init | bring up SPI1 + NodeDB read-only; no Tx |
| LoRa radio (SX1262) | OFF | eliminate radio IRQ as WDT trigger |
| Core 1 LVGL UI task | suspended | eliminate LVGL deadlock as WDT trigger |
| Core 1 `IPCRxTask` | running | required to serve CDC console |
| Core 1 `USBTask` + TinyUSB  | running (Mode COMM forced) | primary out-of-band recovery path; CDC#1 Control read-only (see §4.7 / Control Protocol §8.3) |
| J-Link SWD | always on | hardware — independent of firmware state |
| LCD (PIO + DMA) | OFF | avoid any PIO/DMA path implicated in fault |
| Keypad scan (PIO1) | OFF | only PWR key read via direct GPIO poll |
| Sensor / Power I2C polling  | 5 s cadence | battery status still reported over CDC |
| Flash writes | ALLOWED | needed to clear config that caused fault |
| Watchdog | disabled | prevent loop if recovery command takes > 8 s  |

**User-visible indicators:**

- Status LED (LM27965 channel A) runs a distinctive 0.5 Hz red slow-blink pattern.
- CDC banner on enumeration: `MOKY-SAFE-MODE rev=<git-sha> wdt_count=<N>` followed by
  a `breadcrumb` dump from §9.3.
- No LCD output — by design: user must connect a PC + CDC to recover.

**Exit paths from safe mode:**

| Trigger | Action |
|---|---|
| CDC command `safe-mode exit` | Clear `SCRATCH[1,3]`; reboot |
| CDC command `factory-reset` | Wipe LittleFS; clear `SCRATCH[1,3]`; reboot |
| CDC command `reboot-ota` | Set `SCRATCH[3]=1`; reboot into BOOTSEL (§10.5) |
| Hold PWR 10 s continuously | Clear `SCRATCH[1,3]`; reboot |
| USB disconnect for > 60 s | Assume attempt made; reboot once into normal mode |

**Instrumentation:** the breadcrumb ring (§9.3) is dumped over CDC immediately after
the banner. This is the primary post-mortem tool — any deadlock or fault visible through
the breadcrumb sequence is diagnosable remotely without J-Link access.

---

## 10. Release Distribution — UF2 Strategy

J-Link SWD is the development-time flashing path (§8.5). For end-user distribution
MokyaLora ships `.uf2` files that the RP2350 bootrom can write via drag-and-drop BOOTSEL
mass-storage mode — no J-Link required.

### 10.1 Why a combined UF2

UF2 blocks are 512 bytes each and **self-describe** their target flash address. That means
two UF2 streams covering non-overlapping address ranges can be concatenated into a single
file; the bootrom writes each block to its own target. MokyaLora's two slots are
`0x10000000` (Core 0) and `0x10200000` (Core 1) — non-overlapping — so one combined UF2 can
install both images in a single drag-drop.

### 10.2 Build flow (`scripts/build_uf2.sh`)

```sh
# Core 0 — ELF → UF2 (address taken from IMAGE_DEF, defaults to 0x10000000)
picotool uf2 convert \
    firmware/core0/meshtastic/.pio/build/rp2350b-mokya/firmware.elf \
    build/dist/core0.uf2 \
    --family rp2350-arm-s

# Core 1 — raw .bin → UF2, MUST specify --offset because there is no IMAGE_DEF
picotool uf2 convert \
    build/core1_bridge/core1_bridge.bin \
    build/dist/core1.uf2 \
    --offset 0x10200000 \
    --family rp2350-arm-s

# Merge — each UF2 block is self-describing; cat is safe.
# Bootrom tolerates inconsistent numBlocks across concatenated streams.
cat build/dist/core0.uf2 build/dist/core1.uf2 > build/dist/mokyalora-full.uf2
```

### 10.3 Artefacts shipped

| File | Contents | Typical size | When to use |
|---|---|---|---|
| `core0.uf2` | Core 0 only, target `0x10000000` | ~1.5 MB | Iterating on Meshtastic without touching UI |
| `core1.uf2` | Core 1 only, target `0x10200000` | ~200–400 KB  | Iterating on UI/IME/HAL |
| `mokyalora-full.uf2` | Core 0 + Core 1 concatenated | ~1.5–2 MB | First-time install, general end-user update |

### 10.4 Hard rules

1. **Family ID = `rp2350-arm-s`** (`0xe48bff59`). Never use the `absolute` family — it
   would allow the UF2 to be written onto a mismatched RP2040/RP2350 variant.
2. **Core 1 UF2 must pass `--offset 0x10200000`.** Core 1's `.bin` has no IMAGE_DEF; the
   bootrom does not — and must not — infer its address from the image.
3. **Core 1 must stay without IMAGE_DEF** (see §6.2). The bootrom validates IMAGE_DEF only
   at `0x10000000` to decide which image to boot; raw bytes at `0x10200000` are simply
   programmed to flash and later launched by Core 0 via `multicore_launch_core1_raw()`.
4. **`.uf2` are byte-stream compatible** — do not run them through ELF-level strip/patch
   tools. If a block's target or payload changes, regenerate from the source ELF/BIN.

### 10.5 Entering BOOTSEL for in-place update

First-time users hold BOOTSEL during power-on. For in-place updates of a running device a
USB command is preferable. Two options, in order of effort:

- **Short-term (M5):** Meshtastic's existing `reboot_ota` admin command reboots Core 0;
  pair it with a Pico SDK `reset_usb_boot(0, 0)` call on reset path when a magic flag is
  set in the watchdog scratch register. User runs `meshtastic --reboot-ota` and the device
  re-appears as a BOOTSEL mass-storage drive.
- **Long-term (M6+):** full OTA via Meshtastic protocol. The 4 MB OTA region at
  `0x10400000` (see §2.1) stages a downloaded combined image, then a mini bootloader swaps
  slots on next reset. No BOOTSEL needed.

---

## 11. Licence Compliance for Binary Distribution

Shipping a combined `mokyalora-full.uf2` mixes GPL-3.0 (Core 0 / Meshtastic), Apache-2.0
(Core 1 / MIE), and MIT (shared IPC) in a single file. This is legally clean provided the
distribution is structured as **GPL-3.0 §5 mere aggregation**, not a combined work.

### 11.1 Why this is aggregation, not a combined work

The architecture already satisfies the separate-and-independent-works test:

- Separate flash slots, separate SRAM regions, separate ELF/BIN — no link-time overlap
- IPC is a wire protocol (shared-SRAM SPSC rings), structurally equivalent to UART / network
- Core 1 `#include`s zero Meshtastic headers; shared header is MIT only
- Two independent build tools (PlatformIO vs. CMake) — Core 0 objects cannot accidentally
  be linked into Core 1 or vice versa
- Each image is developed, built, and debugged independently. The MIE sub-library ships a
  full host-only build (`firmware/mie/tests`) that runs on PC without either core, proving
  Core 1's IME logic is not a derivative of Meshtastic code

UF2 concatenation is analogous to putting two independent packages onto the same ISO —
GPL-3.0 §5 explicitly permits this.

### 11.2 Hard rules that must not break (audit triggers)

| Rule | Where enforced |
|---|---|
| `firmware/shared/ipc/` headers `#include` only `<stdint.h>` / `<stddef.h>`| Code review; compile breakage if violated |
| Core 1 image never `#include`s a Meshtastic header | Separate include paths; CMake sources list  |
| Core 0 image never `#include`s a Core 1 header | PlatformIO `build_src_filter` |
| Release scripts never link Core 0 objects into Core 1 (or vice versa) | `build_and_flash.sh`, `build_uf2.sh` |
| The MIT shared header keeps MIT licence (compatible with both sides) | File header + `LICENSE-MIT` |

A violation of any row promotes the two images from "aggregated" to "combined work", which
would force Apache-2.0 Core 1 code under GPL-3.0. Treat these as release blockers.

### 11.3 Release bundle contents

A distributable release zip alongside the UF2 MUST include:

| File | Source / notes |
|---|---|
| `mokyalora-full.uf2` | combined image (plus optional `core0.uf2`, `core1.uf2`) |
| `COPYING` | GPL-3.0 full text — applies to Core 0 |
| `LICENSE-APACHE-2.0` | applies to Core 1, MIE, shared code that is Apache |
| `LICENSE-MIT` | applies to `firmware/shared/ipc/` |
| `NOTICE` | Apache-2.0 §4 attributions (Meshtastic + third-party NOTICEs too) |
| `THIRD_PARTY_LICENSES.md` | RadioLib, FreeRTOS-Kernel, Pico SDK, TinyUSB, LVGL, Crypto, etc.|
| `WRITTEN_OFFER.txt` | GPL-3.0 §6 three-year written offer for corresponding source |
| `README.md` | Pointers to public source (Meshtastic fork + MokyaLora repo) |
| `BUILD.md` (or link) | How to rebuild the UF2 from source |

### 11.4 Source availability

Even though both repos are public on GitHub, GPL-3.0 §6 still requires a written offer
valid for three years from the distribution date. The `WRITTEN_OFFER.txt` must:

- Identify the exact Meshtastic fork branch (`tengigabytes/firmware@feat/rp2350b-mokya`)
  and commit hash built into the shipped binary
- Offer to provide the corresponding source on physical medium, or via a download URL
- Name a contact address that will remain valid for at least three years

The build system should embed the Core 0 git commit hash into the binary (`git describe`
at compile time) and print it in the release notes so downstream users can correlate a UF2
to an exact source tree.

### 11.5 Release pipeline additions

`scripts/build_uf2.sh` should, beyond building the UF2s:

1. Produce `build/dist/mokyalora-<version>.zip` containing all files in §11.3
2. Fail the build if `firmware/shared/ipc/` has grown any non-MIT `#include`
3. Fail the build if `nm core0.elf` and `nm core1_bridge.elf` disagree on
   `g_ipc_shared`'s address (same check already used during dev)
4. Embed `git describe --always --dirty` output for both repos into the zip's
   `VERSION.txt`

These checks are the automatic half of §11.2 — they catch licence-boundary drift before a
release is shipped.

---

## 12. Hardware Revision Boundary

MokyaLora firmware targets a specific hardware revision (currently Rev A), but the
architecture is intentionally partitioned between **revision-agnostic** components that
survive HW bumps unchanged and **Rev A-specific** components that will change or be
removed. This section is the forward-compatibility contract — any future HW revision
only needs to rewrite the "Rev A specific" column.

### 12.1 Revision-agnostic (survives HW bumps unchanged)

| Layer | Component(s) |
|---|---|
| Dual-core partition | GPL Core 0 / Apache Core 1 separation (§1) |
| Flash + SRAM layout | 2 MB / 2 MB firmware slots, 24 KB shared IPC region (§2) |
| IPC protocol | `ipc_protocol.h`, `ipc_shared_layout.h`, SPSC ring primitives (§5) |
| Boot model | Core 0 ELF + Core 1 BIN + `multicore_launch_core1_raw` (§6, §9)  |
| Flash-write safety | `flash_safety_wrap.c` discipline (§6.7) |
| Build tooling | PlatformIO + CMake + `scripts/build_and_flash.sh` (§8) |
| Licence compliance | §11 aggregation rules and release pipeline |
| MIE engine | `firmware/mie/` sub-library (Core 1 SERVICE layer, §4.1) |
| UI framework | LVGL + FreeRTOS tasks (§4.2) |
| USB CDC byte bridge | `IPC_MSG_SERIAL_BYTES` (§4.6, §5.5) |
| Watchdog / safe mode | Scratch-register boot counter (§9.4) |

### 12.2 Rev A specific (may change or disappear)

| Layer / Component | Rev A state | Expected in next revision |
|---|---|---|
| Audio frontend | IM69D130 PDM mic + NAU8315 amp + CMS-131304 speaker populated | **Removed.** No PDM PIO program, no I2S task; firmware already has no audio task — removing the HW drops ~0 KB of Core 1 RAM |
| Battery | Nokia BL-4C ~890 mAh (BQ27441 Design Capacity = 1000 mAh) | Possibly larger; update `GaugeMonitor` init constant |
| Sensor bus mix | IMU 0x6A · Mag 0x1E · Baro 0x5D · GPS 0x3A on `i2c1` GPIO 34/35  | Unchanged unless part numbers change |
| Power bus mix | BQ25622 0x6B · BQ27441 0x55 · LM27965 0x36 on GPIO 6/7 (`i2c1`)  | Rev B should move sensor bus to a mod-4=0/1 pair to free `i2c0`; Rev A time-muxes `i2c1` |
| GNSS LNA / SAW | BGA725L6 LNA + B39162B4327P810 SAW | Unchanged unless antenna retuned |
| Optional wireless | None | Bluetooth may be added via companion nRF52 on SPI0 / I2C / UART. Core 0 already sets `-D MESHTASTIC_EXCLUDE_BLUETOOTH`, so the integration point would be Core 1 |
| USB transport | TinyUSB CDC via RP2350 native USB | Unchanged |
| SWD / J-Link | 3-pin test point | Unchanged |

### 12.3 Migration checklist (template for the next HW bump)

When producing Rev B (or later), run this checklist before Core 0 / Core 1 firmware is built:

1. Update `docs/design-notes/mcu-gpio-allocation.md` — the authoritative GPIO /
   I2C pin map.
2. Update `docs/requirements/system-requirements.md` §2 system architecture and
   §5 spec summary (user-visible specs only).
3. Update `docs/requirements/hardware-requirements.md` — per-subsystem component
   tables, power tree, keypad matrix, mandatory design rules.
4. If **audio is removed**: delete any PDM/I2S PIO program files; no firmware task to remove
   (none was ever created on Rev A). Update §12.2 to move audio row out of this table.
5. If **battery capacity** changes: update BQ27441 `Design Capacity` constant in
   `GaugeMonitor` init; re-run fuel-gauge learning cycle.
6. If a **new peripheral bus** is added: reserve the owner in §7 ownership table; allocate a
   new FreeRTOS task entry in §4.2 if polling is needed; extend `IpcConfigKey` if the
   peripheral exposes user-facing settings.
7. Re-run RAM usage SWD sweep (§2.2 Core 1 breakdown) and update this document.
8. Bump the firmware-architecture.md `Last updated` date at the top.
9. If the flash layout changes, update §2.1 **and** the two linker scripts; run the
   `nm g_ipc_shared` CI coherency check to catch any drift.

### 12.4 Forward compatibility guarantees

The shared IPC ABI (`ipc_protocol.h`) is **not** a backwards-compatible contract today.
When Core 0 and Core 1 images are built from incompatible ABI versions, results are
undefined. Until M6, the project ships the two images as a paired release (single
combined UF2 per §10), so ABI skew is avoided by construction rather than by version
negotiation.

**M6+ plan:** extend the boot handshake magic from `"MOKY"` (4 B) to `"MOKY" + uint16_t
ipc_abi_version + uint16_t reserved` (8 B). Core 0 refuses to launch Core 1 if the ABI
versions disagree, and the status LED enters safe mode with a distinct pattern.

---

## 13. Relationship to Other Documents

| Document | Scope |
|---|---|
| `docs/requirements/system-requirements.md` | System-level spec — architecture, operating modes, mandatory HW rules |
| `docs/requirements/hardware-requirements.md` | Full BOM, power tree, GPIO map, keypad matrix |
| `docs/requirements/software-requirements.md` | SRS — what the firmware must do (behaviour, performance) |
| `docs/design-notes/firmware-architecture.md` | **This doc** — how the firmware is actually built (HOW)  |
| `docs/design-notes/ipc-ram-replan.md` | Derivation / budget record for the 176/312 split |
| `docs/design-notes/mie-architecture.md` | MIE (MokyaInput Engine) internals |
| `docs/bringup/phase2-log.md` | Per-milestone bring-up log, issue IDs (P2-n) |
| `firmware/shared/ipc/ipc_protocol.h` | Message IDs + payload structs (normative) |
| `firmware/shared/ipc/ipc_shared_layout.h` | 24 KB byte map (normative) |
| `firmware/core1/m1_bridge/memmap_core1_bridge.ld`| Core 1 linker script (normative) |
| `firmware/core0/...patch_arduinopico.py` | Core 0 framework patches (normative) |
| `scripts/build_and_flash.sh` | Dual-image build + flash driver |

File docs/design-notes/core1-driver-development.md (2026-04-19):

# Core 1 Driver Development Guide

**Scope.** This document describes the constraints, init rules, and
debugging playbook for writing new peripheral drivers inside the
Core 1 `m1_bridge` image (Apache-2.0, `firmware/core1/`). Core 0
(Meshtastic, GPL-3.0) follows Arduino-Pico conventions and is out of
scope here.

It distils lessons from M1 (USB bridge), M2 (doorbell + flash
safety), M3.1/M3.2 (display + LVGL), and M3.3 (keypad — Phase A
PIO+DMA scan, Phase B 20 ms debounce + multi-producer KeyEvent
queue). Every rule here is a rule **because something silently broke
once**. If you are about to add a new driver, read this before
writing code.

---

## 1. What Core 1 Inherits vs Does Itself

Core 0 boots the RP2350, runs the stock Pico SDK `runtime_init_*`
hooks, then calls `multicore_launch_core1_raw()` from `initVariant()`.
Core 1's crt0 then runs with several hooks deliberately skipped
(see `firmware/core1/m1_bridge/CMakeLists.txt`):

| Hook | Done by | Consequence for Core 1 |
|---|---|---|
| `runtime_init_clocks` | Core 0 | `clock_get_hz(clk_*)` returns **0** on Core 1 |
| `runtime_init_early_resets` | Core 0 | All peripherals already out of reset |
| `runtime_init_post_clock_resets` | Core 0 | IO_BANK0, PADS_BANK0, PIO0/1, DMA, etc. all out of reset |
| `runtime_init_spin_locks_reset` | Core 0 | `spin_lock_claim` is safe |
| `runtime_init_bootrom_locking_enable` | Core 0 | Core 1 does not enter this path |
| `runtime_init_usb_power_down` | Core 0 | USB-CTRL left in whatever state Core 0 gave it; we re-init it |
| `runtime_init_install_ram_vector_table` | Core 1 (kept)  | FreeRTOS needs writable VTOR |
| `runtime_init_mutex` | Core 1 (kept)  | C runtime mutex init |
| `runtime_init_per_core_*` | Core 1 (kept)  | NVIC priorities etc. |

**Implication.** Do not call `unreset_block_wait` or `clock_configure`
from Core 1 code — you will fight Core 0 or no-op harmlessly depending
on the peripheral. Do not call `clock_get_hz()` for timing — Core 1
always sees 0. Use the system-clock constant (150 MHz) or read QMI /
PLL registers directly if you really need runtime values.

---

## 2. Pico SDK Board Header Must Match Silicon

**MokyaLora Rev A uses RP2350B (48 GPIOs).** The Pico SDK gates a
lot of behaviour on `PICO_RP2350A`:

```c
// src/rp2350/hardware_regs/include/hardware/platform_defs.h
#if PICO_RP2350A
#define NUM_BANK0_GPIOS _u(30)
#else
#define NUM_BANK0_GPIOS _u(48)
#endif
```

`check_gpio_param(gpio)` in `hardware_gpio/include/hardware/gpio.h`
is the macro every GPIO entrypoint calls:

```c
static inline void check_gpio_param(uint gpio) {
    invalid_params_if(HARDWARE_GPIO, gpio >= NUM_BANK0_GPIOS);
}
```

In a release build (`PARAM_ASSERTIONS_ENABLED_HARDWARE_GPIO=0`) this
compiles to a no-op and the SDK function **returns without doing
anything** when `gpio >= NUM_BANK0_GPIOS`. There is no error, no
log — the pad register stays at its boot-time default
(`0x00000116`: ISO=1, IE=0, PDE=1, FUNCSEL stays at `0x1F` = NULL).

The stock `pico2` / `pico2_w` board headers both define
`PICO_RP2350A 1`, so any MokyaLora build that inherits from them
silently drops every GPIO write to pins 30–47. **Display works
(GPIO 6–22, in range) but keypad fails (GPIO 36–47, out of range).**

**Fix that shipped in M3.3 Phase A:**
`firmware/core1/m1_bridge/boards/mokya_rev_a.h` defines
`PICO_RP2350A 0` plus MokyaLora-specific flash/variant fields. The
CMakeLists appends the boards/ directory to `PICO_BOARD_HEADER_DIRS`
and sets `PICO_BOARD mokya_rev_a`:

```cmake
list(APPEND PICO_BOARD_HEADER_DIRS "${CMAKE_CURRENT_SOURCE_DIR}/boards")
set(PICO_BOARD mokya_rev_a CACHE STRING "MokyaLora Rev A (RP2350B)" FORCE)
```

**Rule.** Never change `PICO_BOARD` to a stock value for the Core 1
image without verifying `PICO_RP2350A 0`. If you bring in another SDK
subsystem that depends on board-specific pins, extend `mokya_rev_a.h`
rather than swap boards.

---

## 3. GPIO Driver Rules

### 3.1 Use the SDK, not raw registers

```c
gpio_init(pin);
gpio_set_dir(pin, GPIO_OUT);
gpio_put(pin, 1);
gpio_pull_up(pin);
// ...
```

The SDK's `gpio_set_function(pin, GPIO_FUNC_SIO)` (called implicitly
by `gpio_init`) does three important things on RP2350:

1. Clears `ISO` in the pad register (so the pad actually connects).
2. Sets `IE=1` (input buffer on) and clears `OD`.
3. Writes `FUNCSEL` in IO_BANK0 ctrl.

If you bypass the SDK with direct pad writes, you **must** replicate
all three steps, including the ISO clear. Previous debug sessions
wrote `IE|PUE` to the pad register and forgot ISO — the pad stayed
isolated, the pin did nothing, and the symptom was identical to
"GPIO not initialised" which made diagnosis circular.

### 3.2 High GPIOs (30–47) are behind `gpio_hi_*`

SIO has separate register pairs for GPIO 0–31 (`gpio_out`, `gpio_oe`,
`gpio_in`) and 32–47 (`gpio_hi_out`, `gpio_hi_oe`, `gpio_hi_in`).
The SDK handles this internally — **if** `NUM_BANK0_GPIOS` is 48. If
it is 30 (wrong board header), every SDK call that uses the high-GPIO
path short-circuits.

SWD reference for GPIO 32–47:
- `SIO_BASE + 0x008` — `gpio_hi_in`
- `SIO_BASE + 0x014` — `gpio_hi_out`
- `SIO_BASE + 0x034` — `gpio_hi_oe`

Bit `N - 32` is the bit for GPIO `N`.

### 3.3 Register cheatsheet for SWD diagnosis

| Register | Address (GPIO N) | Healthy for input with pull-up  | Healthy for output | Reset default (unhealthy) |
|---|---|---|---|---|
| `PADS_BANK0_GPIO{N}` | `0x40038004 + N*4` | `0x5A` (IE=1 PUE=1 PDE=0 ISO=0) | `0x56` (IE=1 PUE=0 PDE=1 ISO=0) \* | `0x116` (ISO=1 IE=0 PDE=1) |
| `IO_BANK0 GPIO{N} ctrl` | `0x40028004 + N*8` | `0x05` (FUNCSEL=SIO) | `0x05` | `0x1F` (FUNCSEL=NULL) |
| `SIO gpio_hi_in` | `0xD0000008` | bit N-32 reflects pull | bit N-32 reflects own output | (IE=0 so reads undefined) |
| `SIO gpio_hi_out` | `0xD0000014` | any | what you wrote | 0 |
| `SIO gpio_hi_oe` | `0xD0000034` | bit clear (input) | bit set | 0 |

\* Output pads currently keep the reset-default PDE=1; this is
intentional (the output driver dominates) but you can clear it with
`gpio_disable_pulls()` if you want the cleanest state.

Pad register bit layout (RP2350):

```
bit 8: ISO        (must be 0 to use the pad)
bit 7: OD         (output disable)
bit 6: IE         (input enable)
bits 5..4: DRIVE  (00=2mA, 01=4mA, 10=8mA, 11=12mA)
bit 3: PUE        (pull-up enable)
bit 2: PDE        (pull-down enable)
bit 1: SCHMITT
bit 0: SLEWFAST
```

### 3.4 PIO on high GPIOs — `pio_set_gpio_base(pio, 16)` is mandatory

A PIO instance can address only 32 consecutive GPIOs at a time. On
RP2350B the PIO's "GPIO base" register selects whether the SM pinctrl
fields refer to GPIOs 0–31 (default) or 16–47. Any peripheral that
lives on GPIO 32–47 (keypad columns/rows, sensor-bus pins on some
revisions) **must** call `pio_set_gpio_base(pio, 16)` **before**
`pio_sm_init`. Skip it and `pio_sm_init` returns
`PICO_ERROR_BAD_ALIGNMENT` — a silent failure in release builds where
the assertion is compiled out.

The SDK helpers `sm_config_set_out_pins()`, `sm_config_set_in_pins()`
etc. accept raw GPIO numbers (36–47) and stash the high bits in
`pio_sm_config.pinhi` when `PICO_PIO_USE_GPIO_BASE=1` (automatically
set for RP2350B via our board header). `pio_sm_init()` then validates
the config against the current `gpiobase`; mismatch → error.

Standard keypad init sequence:

```c
pio_set_gpio_base(pio0, 16);        /* required BEFORE sm init */
uint sm = pio_claim_unused_sm(pio0, true);
uint off = pio_add_program(pio0, &keypad_scan_program);
keypad_scan_program_init(pio0, sm, off, ROW_BASE, COL_BASE, clkdiv);
pio_sm_set_enabled(pio0, sm, true);
```

`pio_gpio_init(pio, pin)` itself takes the raw GPIO number — the SDK
adjusts internally.

### 3.5 PIO + DMA continuous-scan pattern

For periodic scanners (keypad, sensor polling) the canonical zero-CPU
pattern is PIO + 2 DMA channels, both in ring mode:

- **TX DMA** streams a fixed mask table from RAM into the PIO TX FIFO.
  `channel_config_set_ring(&cfg, false, N)` makes read-addr wrap at a
  2^N-byte boundary, so the table loops forever without CPU attention.
- **RX DMA** drains PIO RX FIFO into a mirror buffer in RAM.
  `channel_config_set_ring(&cfg, true, N)` wraps write-addr so the
  buffer always holds the latest `2^N` results.
- Both channels use 8-bit transfers even though the PIO FIFO is
  32-bit wide: an 8-bit DMA transfer pops one full FIFO word and keeps
  the low byte, advancing memory by 1 byte. Align the RAM buffers to
  `2^N` so ring mode doesn't partially wrap.
- Use `dma_start_channel_mask((1u << tx) | (1u << rx))` to start both
  simultaneously, then `pio_sm_set_enabled()`.
- `transfer_count = 0xFFFFFFFFu` gives ~5.8 days at our scan rate
  before the channels exhaust. Chain a pair of channels per direction
  (each chained_to the other) if uptime demand exceeds that.

The consumer task just reads the RX mirror buffer — no PIO FIFO
interaction. Single-byte DMA-concurrent reads of individual ring slots
are safe; composite reads across multiple slots may catch one slot
mid-write. For keypad that is fine because debounce absorbs the
single-row staleness. For higher-integrity snapshots (sensor triplets
that must agree), add a double-buffer with a DMA-complete IRQ to
signal "buffer A is stable".

---

## 4. FreeRTOS Rules on Core 1

### 4.1 Heap is 32 KB total — size tasks accordingly

`configTOTAL_HEAP_SIZE = 32 * 1024` (heap_4). All task stacks, TCBs,
queue control blocks, and `pvPortMalloc` allocations come out of this
one pool. Check `xFreeBytesRemaining` via SWD after boot.

Current post-boot allocation (M3.4.2):

| Consumer | Bytes  |
|---|---|
| `usb_device_task` stack  | 4096 |
| `bridge_task` stack | 4096 |
| `lvgl_task` stack | 12288 |
| `keypad_scan_task` stack | 2048 |
| `charger_task` stack (BQ25622) | 2048 |
| `KeyEvent` queue (16 × 2 B + ctrl) | ~112 |
| `i2c_bus` mutex | ~80 |
| Idle task stack | 2048 |
| Timer service task stack | 2048 |
| TCBs + queues | ~1.5 KB |
| **Free** | ~3 KB |

**Rule.** Add a new task → drop an existing task's stack high-water
margin, or raise `configTOTAL_HEAP_SIZE` in `FreeRTOSConfig.h`. Do
not assume there is headroom.

### 4.2 Always check `xTaskCreate` return code

```c
BaseType_t rc = xTaskCreate(fn, "name", stack_words, NULL, prio, NULL);
if (rc != pdPASS) { /* heap exhausted — task does not exist */ }
```

Silent failure (`(void)rc;`) is how M3.3 Phase A cost a full debug
cycle. The task was never created; there was no symptom other than
"the driver doesn't work". Either assert, or publish `rc` to a
named SWD-readable variable while the driver is still experimental.

### 4.3 Priority starvation is the default, not the exception

Core 1 runs `configUSE_PREEMPTION=1` with time-slicing. The scheduler
always picks the **highest-priority ready task**; round-robin only
rotates within equal priority. Strictly-lower priorities run only
when every higher-priority task blocks.

Several of our tasks **never block** in their outer loop:

- `usb_device_task`: `for(;;) { tud_task(); taskYIELD(); }` — always ready.
- `bridge_task`: blocks on `xTaskNotifyWait(10 ms)` when idle, but spins busy under traffic.
- `lvgl_task`: `vTaskDelay(pdMS_TO_TICKS(next))` — yields properly.

A new task at priority `tskIDLE_PRIORITY + 1` will be starved by
`usb_device_task` at priority `tskIDLE_PRIORITY + 2`.

**Rule for I/O tasks.** Match the priority of the existing round-robin
group (currently `tskIDLE_PRIORITY + 2`). Only put work at a strictly
lower priority if it is genuinely optional and tolerant of arbitrary
delay — there is no such work in the current image.

### 4.4 SysTick override required

Core 1 skips `runtime_init_clocks`, so `configured_freq[clk_sys]`
stays 0 and the default `vPortSetupTimerInterrupt()` loads the
SysTick with `0xFFFFFF`, making tick rate collapse to ~9 Hz. Core 1's
`main_core1_bridge.c` overrides `vPortSetupTimerInterrupt()` with the
known 150 MHz constant. Do not remove this override. If you change
`configTICK_RATE_HZ`, update the override too.

---

## 5. I2C Rules

`i2c_init(i2c_inst, baud)` computes the SCL timing divisor from
`clock_get_hz(clk_peri)`. On Core 1 this returns 0 → garbage baud
→ inconsistent NACKs (P3-3 symptom).

**Pattern that works** (see `display.c::backlight_init`):

```c
i2c_init(BL_I2C, 100 * 1000);                 // brings peripheral out of reset
i2c_set_baudrate_core1(BL_I2C, 100 * 1000);   // fix up timing with known 150 MHz
gpio_set_function(PIN_SDA, GPIO_FUNC_I2C);
gpio_set_function(PIN_SCL, GPIO_FUNC_I2C);
gpio_pull_up(PIN_SDA);
gpio_pull_up(PIN_SCL);
```

`i2c_set_baudrate_core1` is MokyaLora's replacement — it mirrors the
SDK's baud-rate logic but uses the 150 MHz constant for `clk_peri`.

---

## 6. Flash & Interrupts

Core 1 can read flash (XIP) freely. **Core 0 owns flash writes**, and
any write path on Core 0 is wrapped via `--wrap=flash_range_erase` /
`--wrap=flash_range_program` to trigger the park protocol:

1. Core 0 sets `flash_lock = REQUEST`, fires `IPC_FLASH_DOORBELL`.
2. Core 1's doorbell ISR calls `flash_park_handler()` (RAM-resident):
   - ACKs with `flash_lock = PARKED`, `__sev()` wakes Core 0.
   - Disables all IRQs on Core 1.
   - `__wfe()` spins in RAM until Core 0 clears the lock.
3. Core 0 completes the write, clears `flash_lock`, `__sev()`.
4. Core 1 restores IRQs and returns.

**Rule.** Never add code that writes flash from Core 1. Never disable
the `flash_range_*` wraps on Core 0. If you ever need to flash-write
from Core 1, you must reverse the roles — this has not been designed
and is not worth doing for anything currently on the roadmap.

---

## 7. Debugging Playbook
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

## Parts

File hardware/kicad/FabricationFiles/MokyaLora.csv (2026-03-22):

Reference | Qty | Value | DNP | Footprint | MPN | Manufacturer
H3,H5 | 2 | 36003160S |  |  | 36003160S | Wurth Elektronik
H1,H7 | 2 | 36103166S |  | MokyaLora:36103166S | 36103166S | Wurth Elektronik
J8 | 1 | 009155003301006 |  | MokyaLora:009155003301006 | 009155003301006 | Kyocera AVX
U8 | 1 | 4259-63 |  | MokyaLora:SOT65P210X110-6N | 4259-63 | Peregrine Semiconductor
J3 | 1 | 54132-4062 |  | MokyaLora:54132-4062_1 | 54132-4062
X1 | 1 | 12MHz |  | MokyaLora:Crystal_SMD_3225-4Pin_3.2x2.5mm | ABM8-272-T3 | ABRACON
C93 | 1 | 1pF |  | MokyaLora:C_0402_1005 | AC0402BRNPO9BN1R0 | YAGEO
C94 | 1 | 1.5pF |  | MokyaLora:C_0402_1005 | AC0402BRNPO9BN1R5 | YAGEO
C42,C95 | 2 | 1.8pF |  | MokyaLora:C_0402_1005 | AC0402BRNPO9BN1R8 | YAGEO
C65,C96 | 2 | 2pF |  | MokyaLora:C_0402_1005 | AC0402BRNPO9BN2R0 | YAGEO
C97 | 1 | 2.2pF |  | MokyaLora:C_0402_1005 | AC0402BRNPO9BN2R2 | YAGEO
C47 | 1 | 2.4pF |  | MokyaLora:C_0402_1005 | AC0402BRNPO9BN2R4 | YAGEO
C49 | 1 | 2.4pF | DNP | MokyaLora:C_0402_1005 | AC0402BRNPO9BN2R4 | YAGEO
C98 | 1 | 2.7pF |  | MokyaLora:C_0402_1005 | AC0402BRNPO9BN2R7 | YAGEO
C99 | 1 | 3pF |  | MokyaLora:C_0402_1005 | AC0402BRNPO9BN3R0 | YAGEO
C46,C100 | 2 | 3.3pF |  | MokyaLora:C_0402_1005 | AC0402BRNPO9BN3R3 | YAGEO
C101 | 1 | 4.3pF |  | MokyaLora:C_0402_1005 | AC0402BRNPO9BN4R3 | YAGEO
C103 | 1 | 4.7pF |  | MokyaLora:C_0402_1005 | AC0402BRNPO9BN4R7 | YAGEO
C102 | 1 | 5.6pF |  | MokyaLora:C_0402_1005 | AC0402BRNPO9BN5R6 | YAGEO
C104 | 1 | 6.8pF |  | MokyaLora:C_0402_1005 | AC0402BRNPO9BN6R8 | YAGEO
C105 | 1 | 8.2pF |  | MokyaLora:C_0402_1005 | AC0402BRNPO9BN8R2 | YAGEO
C63,C64,C66 | 3 | 0.5pF | DNP | MokyaLora:C_0402_1005 | AC0402BRNPO9BNR50 | YAGEO
C67 | 1 | 0.5pF |  | MokyaLora:C_0402_1005 | AC0402BRNPO9BNR50 | YAGEO
C51,C57 | 2 | 3pF |  | MokyaLora:C_0402_1005 | AC0402CRNPO9BN3R0 | YAGEO
C54,C55 | 2 | 3.3pF |  | MokyaLora:C_0402_1005 | AC0402CRNPO9BN3R3 | YAGEO
C56 | 1 | 4pF |  | MokyaLora:C_0402_1005 | AC0402CRNPO9BN4R0 | YAGEO
C45 | 1 | 8.2pF | DNP | MokyaLora:C_0402_1005 | AC0402DRNPO9BN8R2 | YAGEO
C48 | 1 | 8.2pF |  | MokyaLora:C_0402_1005 | AC0402DRNPO9BN8R2 | YAGEO
R8,R9,R10,R11,R12,R13,R16,R17,R19,R23,R24,R28,R31,R32,R34,R36,R37,R38,R39,R40,R41,R54,R55,R57,R58,R59,R60,R61 | 28 | 0 |  | MokyaLora:R_0402_1005 | AC0402FR-070RL | YAGEO
R27,R35 | 2 | 0 | DNP | MokyaLora:R_0402_1005 | AC0402FR-070RL | YAGEO
R20,R21 | 2 | 100k | DNP | MokyaLora:R_0402_1005 | AC0402FR-07100KL | YAGEO
R30 | 1 | 100k |  | MokyaLora:R_0402_1005 | AC0402FR-07100KL | YAGEO
R43 | 1 | 1.8M |  | MokyaLora:R_0402_1005 | AC0402FR-071M8L | YAGEO
R49,R50,R52,R103 | 4 | 2.2k |  | MokyaLora:R_0402_1005 | AC0402FR-072K2L
R48 | 1 | 30.1k |  | MokyaLora:R_0402_1005 | AC0402FR-0730K1L | YAGEO
R47 | 1 | 5.23k |  | MokyaLora:R_0402_1005 | AC0402FR-075K23L | YAGEO
R14,R15 | 2 | 8.25k |  | MokyaLora:R_0402_1005 | AC0402FR-078K25L | YAGEO
R6,R26,R63,R90,R91,R92,R93,R94,R95,R96,R97,R98,R99,R100,R101 | 15 | 1k |  | MokyaLora:R_0402_1005 | AC0402FR-7W1KL | YAGEO
R7,R18,R33,R51,R53,R56,R102 | 7 | 10k |  | MokyaLora:R_0402_1005 | AC0402FR-7W10KL | YAGEO
R65 | 1 | 10 |  | MokyaLora:R_0402_1005 | AC0402FR-7W10RL | YAGEO
R4,R5,R64,R66,R67,R68,R69,R70,R71,R72,R73,R74,R75,R76,R77,R78,R79,R80,R81,R82,R83,R84,R85,R86,R87,R88,R89 | 27 | 22 |  | MokyaLora:R_0402_1005 | AC0402FR-7W22RL | YAGEO
R3 | 1 | 33 |  | MokyaLora:R_0402_1005 | AC0402FR-7W33RL | YAGEO
R25,R29 | 2 | 100 |  | MokyaLora:R_0402_1005 | AC0402FR-7W100RL | YAGEO
R22 | 1 | 220 |  | MokyaLora:R_0402_1005 | AC0402FR-7W220RL | YAGEO
R46 | 1 | 470 |  | MokyaLora:R_0402_1005 | AC0402FR-7W470RL | YAGEO
R45,R62 | 2 | 4.7k |  | MokyaLora:R_0402_1005 | AC0402FR-7W4K7L | YAGEO
R1,R2 | 2 | 5.1k |  | MokyaLora:R_0402_1005 | AC0402FR-7W5K1L | YAGEO
C39 | 1 | 10pF |  | MokyaLora:C_0402_1005 | AC0402FRNPO9BN100 | YAGEO
C61 | 1 | 120pF |  | MokyaLora:C_0402_1005 | AC0402FRNPO9BN121 | YAGEO
C19,C20 | 2 | 15pF |  | MokyaLora:C_0402_1005 | AC0402FRNPO9BN150 | YAGEO
C50 | 1 | 39pF |  | MokyaLora:C_0402_1005 | AC0402FRNPO9BN390 | YAGEO
C53 | 1 | 39pF |  | MokyaLora:C_0402_1005 | AC0402GRNPO9BN390 | YAGEO
C44,C59 | 2 | 47pF |  | MokyaLora:C_0402_1005 | AC0402JRNPO9BN470 | YAGEO
C52,C62 | 2 | 1nF |  | MokyaLora:C_0402_1005 | AC0402JRX7R9BB102 | YAGEO
C82 | 1 | 47nF |  | MokyaLora:C_0402_1005 | AC0402KPX7R7BB473 | YAGEO
C23,C35,C37,C77,C79,C89 | 6 | 1uF |  | MokyaLora:C_0402_1005 | AC0402KRX5R5BB105 | YAGEO
C80 | 1 | 220nF |  | MokyaLora:C_0402_1005 | AC0402KRX5R5BB224 | YAGEO
C38,C68 | 2 | 470nF |  | MokyaLora:C_0402_1005 | AC0402KRX5R5BB474 | YAGEO
C3,C4,C5,C6,C7,C9,C10,C11,C12,C13,C14,C15,C16,C17,C18,C21,C22,C24,C32,C33,C34,C36,C40,C41,C58,C72,C73,C81,C88,C90,C91 | 31 | 100nF |  | MokyaLora:C_0402_1005 | AC0402KRX7R6BB104 | YAGEO
C60 | 1 | 10nF |  | MokyaLora:C_0402_1005 | AC0402KRX7R8BB103 | YAGEO
C76,C92 | 2 | 100nF |  | MokyaLora:C_0402_1005 | AC0402KRX7R8BB104 | YAGEO
C43 | 1 | 47nF |  | MokyaLora:C_0402_1005 | AC0402KRX7R8BB473 | YAGEO
C25,C26,C27,C28,C69,C78,C83 | 7 | 1uF |  | MokyaLora:C_0603_1608 | AC0603KRX7R7BB105 | YAGEO
C84 | 1 | 4.7uF |  | MokyaLora:C_0805_2012 | AC0805KKX7R7BB475 | YAGEO
L2 | 1 | 3.3u |  | MokyaLora:L_0806_2016 | AOTA-B201610S3R3-101-T | ABRACON
U3 | 1 | APS6404L-SQN-ZR |  | MokyaLora:Winbond_USON-8-1EP_3x2mm_P0.5mm_EP0.2x1.6mm | APS6404L-SQN-ZR | AP Memory
FL1 | 1 | B4327 |  | MokyaLora:B39162B4327P810 | B39162B4327P810 | Qualcomm
U11 | 1 | BGA123N6 |  | MokyaLora:BGA725L6E6327 | BGA123N6E6327XTSA1 | Infineon
L3 | 1 | 80 |  | MokyaLora:B_0402_1005 | BLM15PX800SN1D | Murata
U14 | 1 | BQ25622RYKR |  | MokyaLora:WQFN-HR18__RYK_TEX | BQ25622RYKR | TI
U12 | 1 | BQ27441DRZR-G1A |  | MokyaLora:DRZ0012A | BQ27441DRZR-G1A | TI
C1,C2,C8,C29,C30,C31 | 6 | 4.7uF |  | MokyaLora:C_0402_1005 | CC0402KRX5R6BB475 | YAGEO
C74,C85 | 2 | 10uF |  | MokyaLora:C_0603_1608 | CC0603KRX5R6BB106 | YAGEO
C75 | 1 | 1uF |  | MokyaLora:C_1206_3216 | CC1206JKX7R8BB105 | YAGEO
C70,C71,C86,C87 | 4 | 10uF |  | MokyaLora:C_1206_3216 | CC1206KKX7R8BB106 | YAGEO
LS1 | 1 | CMS-131304-SMT-TR |  | MokyaLora:SPKR_CMS-131304-SMT-TR | CMS-131304-SMT-TR | Same Sky
L12 | 1 | 2.2u |  | MokyaLora:L_0806_2016 | DFE201612E-2R2M=P2 | Murata
L13 | 1 | 1.5u |  | MokyaLora:L_1210_3225 | DFE322520F-1R5M | Murata
L1 | 1 | 90 |  | MokyaLora:FIL_DLM0NSN900HY2D | DLM0NSN900HY2D | Murata
X2 | 1 | 32MHz |  | MokyaLora:Crystal_SMD_2016-4Pin_2.0x1.6mm | ECS-TXO-20CSMV4-320-AY-TR | ECS
Mtr2 | 1 | HD-EMB1104-SM-2 |  | MokyaLora:PUI_HD-EMB1104-SM-2 | HD-EMB1104-SM-2 | PUI Audio
U9 | 1 | IM69D130 |  | MokyaLora:Infineon_PG-LLGA-5-1 | IM69D130 | Infineon
U17 | 1 | LIS2MDL |  | MokyaLora:LGA-12_2x2mm_P0.5mm | LIS2MDL | STM
U5 | 1 | LM27965 |  | MokyaLora:SQA24A | LM27965SQ | TI
U18 | 1 | LPS22HH |  | MokyaLora:ST_HLGA-10_2x2mm_P0.5mm_LayoutBorder3x2y | LPS22HH | STM
L22 | 1 | 10n |  | MokyaLora:L_0402_1005 | LQW15AN10NG80D | Murata
L23 | 1 | 12n |  | MokyaLora:L_0402_1005 | LQW15AN12NG80D | Murata
L6,L24 | 2 | 15n |  | MokyaLora:L_0402_1005 | LQW15AN15NG80D | Murata
L25 | 1 | 18n |  | MokyaLora:L_0402_1005 | LQW15AN18NG80D | Murata
L8,L14 | 2 | 2.2n |  | MokyaLora:L_0402_1005 | LQW15AN2N2G80D | Murata
L15 | 1 | 3.3n |  | MokyaLora:L_0402_1005 | LQW15AN3N3G80D | Murata
L16 | 1 | 3.9n |  | MokyaLora:L_0402_1005 | LQW15AN3N9G80D | Murata
L4,L7 | 2 | 47n |  | MokyaLora:L_0402_1005 | LQW15AN47NG80D | Murata
L17 | 1 | 4.7n |  | MokyaLora:L_0402_1005 | LQW15AN4N7G80D | Murata
L18 | 1 | 5.6n |  | MokyaLora:L_0402_1005 | LQW15AN5N6G80D | Murata
L19 | 1 | 6.8n |  | MokyaLora:L_0402_1005 | LQW15AN6N8G80D | Murata
L11,L20 | 2 | 8.2n |  | MokyaLora:L_0402_1005 | LQW15AN8N2G80D | Murata
L9,L10,L21 | 3 | 9.1n |  | MokyaLora:L_0402_1005 | LQW15AN9N1G80D | Murata
U13 | 1 | LSM6DSV16XTR |  | MokyaLora:LGA-14_3x2.5mm_P0.5mm_LayoutBorder3x4y | LSM6DSV16XTR | STM
D37,D44 | 2 | LTST-C235KGKRKT |  | MokyaLora:LED_LiteOn_LTST-C235KGKRKT | LTST-C235KGKRKT | LiteOn
D38,D39,D40,D41,D42,D43 | 6 | LTW-482DS5 |  | MokyaLora:LTW-482DS5 | LTW-482DS5 | LiteOn
ANT1 | 1 | M620720 |  | MokyaLora:M620720 | M620720 | Kyocera AVX
ANT2 | 1 | M830120 |  | MokyaLora:SON225P300X800X143-6N | M830120 | Kyocera AVX
L5 | 1 | 15u |  | MokyaLora:L_0603_1608 | MLZ1608N150LT000 | TDK
H2,H4 | 2 | MountingHole_Pad |  | MokyaLora:MountingHole_2.7mm_M2.5_Pad_Via | MountingHole_Pad
U6 | 1 | NAU8315YG |  | MokyaLora:QFN50P400X400X80-21N | NAU8315YG | Nuvoton
R44 | 1 | 10k |  | MokyaLora:R_0402_1005 | NCU15XH103FBSRC | Murata
LCD2 | 1 | NHD-2.4-240320AF-CSXP |  | MokyaLora:NHD-2.4-240320AF-CSXP | NHD-2.4-240320AF-CSXP | Newhaven Display
R42 | 1 | 10m |  | MokyaLora:R_0805_2012 | PA0805FRE470R01L | YAGEO
U2 | 1 | RP2350B |  | MokyaLora:RP2350-QFN-80-1EP_10x10_P0.4mm_EP3.4x3.4mm_ThermalVias | SC1510-A4 | Raspberry Pi
D1,D2,D3,D4,D5,D6,D7,D8,D9,D10,D11,D12,D13,D14,D15,D16,D17,D18,D19,D20,D21,D22,D23,D24,D25,D26,D27,D28,D29,D30,D31,D32,D33,D34,D35,D36,D45,D46,D47 | 39 | ~ |  | MokyaLora:D_SOD-523 | SDM03U40 | Diodes
J2 | 1 | SM03B-SRSS-TB |  | MokyaLora:JST_SH_SM03B-SRSS-TB_1x03-1MP_P1.00mm_Horizontal | SM03B-SRSS-TB | JST
Q1 | 1 | SSM3K56ACT |  | MokyaLora:CST3_TOS | SSM3K56ACT,L3F | Toshiba
SW1,SW2,SW3,SW4,SW5,SW6,SW7,SW8,SW9,SW10,SW11,SW12,SW13,SW14,SW15,SW16,SW17,SW18,SW19,SW20,SW21,SW22,SW23,SW24,SW25,SW26,SW27,SW28,SW29,SW30,SW31,SW32,SW33,SW34,SW35,SW36,SW37,SW38 | 38 | SWT0105-003516JSA |  | MokyaLora:SWT0105 | SWT0105-003516JSA | GCT
U7 | 1 | SX1262IMLTRT |  | MokyaLora:QFN-24-1EP_4x4mm_P0.5mm_EP2.6x2.6mm | SX1262IMLTRT | Semtech
U10 | 1 | TESEO-LIV3FL |  | MokyaLora:TESEOLIV3FL | TESEO-LIV3FL | STMicroelectronics
TP1,TP2,TP3,TP4,TP5,TP6,TP7,TP8,TP9,TP10,TP11,TP12,TP13,TP14,TP15,TP16,TP17,TP18,TP19,TP20,TP21,TP22,TP23,TP24,TP25,TP26,TP27,TP28,TP29,TP30,TP31,TP32,TP33,TP34,TP35,TP36,TP37,TP38,TP39,TP40,TP41,TP42,TP43,TP44,TP45,TP46,TP47,TP48,TP49,TP50,TP51,TP52,TP53,TP54,TP55,TP56,TP57,TP58,TP59,TP60,TP61,TP62,TP63,TP64,TP65,TP66,TP67,TP68,TP69,TP70,TP71,TP72,TP73,TP74,TP75,TP76,TP77,TP78,TP79,TP80,TP81,TP82,TP83,TP84,TP85,TP86,TP87,TP88,TP89,TP90,TP91,TP92,TP93,TP94,TP95,TP96,TP97,TP98,TP99,TP100,TP101,TP102,TP103,TP104,TP105,TP106,TP107,TP108,TP109,TP110,TP111,TP112,TP113 | 113 | TestPoint_Small |  | MokyaLora:TestPoint_Pad_D1.0mm | test point
U15 | 1 | TPS62840DLCR |  | MokyaLora:VSON8_2P1X1P6_TEX | TPS62840DLCR | TI
U16 | 1 | TPS7A2033PDBVR |  | MokyaLora:DBV0005A-IPC_C | TPS7A2033PDBVR | TI
J5,J6 | 2 | U.FL |  | MokyaLora:U.FL_Hirose_U.FL-R-SMT-1_Vertical | U.FL-R-SMT-1 | Hirose
J1 | 1 | USB4105-GF-A |  | MokyaLora:USB_C_Receptacle_GCT_USB4105-xx-A_16P_TopMnt_Horizontal | USB4105-GF-A | GCT
U1 | 1 | USBLC6-2P6 |  | MokyaLora:SOT-666 | USBLC6-2P6 | STM
U4 | 1 | W25Q128JWPIQ |  | MokyaLora:WSON-8-1EP_6x5mm_P1.27mm_EP3.4x4.3mm | W25Q128JWPIQ | Winbond

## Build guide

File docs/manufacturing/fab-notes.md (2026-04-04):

# Fabrication Notes

**Project:** MokyaLora Rev A

---

## Authoritative Reference

All PCB specifications (layer stack-up, board thickness, copper weights, surface finish,
impedance requirements, drill rules, via-in-pad requirements) and assembly instructions
(reflow profile, connector orientations, SMT placement side) are defined in the
**Assembly PDF**, which is generated directly from the KiCad design and is the single
source of truth:

- [`hardware/production/rev-a/pdf/MokyaLora__Assembly.pdf`](../../hardware/production/rev-a/pdf/MokyaLora__Assembly.pdf)

Do not duplicate those specifications here — update the KiCad design and regenerate
the PDF instead.

---

## Fabrication Status

| Milestone | Date | Notes |
|---|---|---|
| Gerber files generated | 2026-03-22 | `hardware/production/rev-a/gerber/` |
| BOM finalised | 2026-03-22 | `hardware/production/rev-a/MokyaLora.csv` |
| Submitted to manufacturer | 2026-03-22 | PCB fabrication + SMT assembly |
| Board received | 2026-04-02 | |
| Bring-up started | 2026-04-02 | 7 issues found — see `docs/bringup/rev-a-bringup-log.md` |

---

## Fabrication Output Files

| File | Location |
|---|---|
| Gerber + drill files | `hardware/production/rev-a/gerber/` |
| Bill of Materials | `hardware/production/rev-a/MokyaLora.csv` |
| Schematic PDF | `hardware/production/rev-a/pdf/MokyaLora.pdf` |
| Assembly drawing PDF | `hardware/production/rev-a/pdf/MokyaLora__Assembly.pdf` |
| Board 3D model (STEP) | `hardware/production/rev-a/MokyaLora.step` |

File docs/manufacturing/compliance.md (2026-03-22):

# Compliance Notes

**Project:** MokyaLora Rev A

> This document is a placeholder. Regulatory compliance work is deferred until after Rev A hardware validation.

---

## Applicable Regulations (Target Markets)

| Region | Standard | Scope |
|---|---|---|
| EU | CE — RED 2014/53/EU | Radio equipment (LoRa 868 MHz) |
| US | FCC Part 15 | Unlicensed intentional radiator |
| TW | NCC | Radio type approval |

## LoRa Frequency Plan

| Region | Band | Frequency | Notes |
|---|---|---|---|
| EU | EU868 | 863–870 MHz | Duty-cycle limited per ETSI  |
| US | US915 | 902–928 MHz | FHSS, limited power |

**Current design target:** EU868. US915 requires confirming SX1262 crystal / filter component values.

## Open Items

- [ ] Determine target frequency bands before PCB Rev A tape-out.
- [ ] Engage test lab for pre-compliance scan after Rev A build.
- [ ] Verify SX1262 TX power limits comply with local regulations.
- [ ] Add regulatory markings to silkscreen (CE / FCC ID placeholder).

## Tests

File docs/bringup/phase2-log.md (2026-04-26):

# Phase 2 Firmware Log

**Plan:** `~/.claude/plans/groovy-petting-alpaca.md` (Phase 2 — RP2350B 韌體生產化)
**Phase 2 started:** 2026-04-11
**Scope:** Dual-core production firmware — Core 0 Meshtastic LoRa modem, Core 1 FreeRTOS + LVGL + MIE UI/IME, IPC via shared-SRAM SPSC ring.

Phase 2 is tracked by **milestone** (M1.0, M1.0b, M1.1, ...), not by step number.
Hardware bring-up log (Steps 1–26) lives in [rev-a-bringup-log.md](rev-a-bringup-log.md).

---

## Milestone 1 — Meshtastic USB → IPC byte-level bridge

**Goal:** PC Web Serial Console can talk to Meshtastic through Core 1's USB CDC, with Core 0 reaching the host only via the shared-SRAM SPSC ring. Every line of code in M1 is production code — no throwaway loopback.

### M1.0 — Core 0 `NO_USB` + `IpcSerialStream` build spike

**Date:** 2026-04-11
**Result:** ✅ COMPLETE — build ✅ PASS, flash ✅ PASS, boot ✅ PASS (Meshtastic reaches `loop()`)

**Goal:** Prove Core 0 Meshtastic firmware can build with Arduino-Pico's built-in `SerialUSB` disabled, with the framework `Serial` global replaced by a stub `IpcSerialStream` that will later route bytes through the shared-SRAM SPSC ring to Core 1.

**Changes applied to `variants/rp2350/rp2350b-mokya/`:**

| File | Change |
|---|---|
| `platformio.ini` | `-DNO_USB`; single-core FreeRTOS flags (`-DconfigNUMBER_OF_CORES=1` + `configUSE_CORE_AFFINITY=0`, `configRUN_MULTIPLE_PRIORITIES=0`, `configUSE_PASSIVE_IDLE_HOOK=0`, `configUSE_TASK_PREEMPTION_DISABLE=0`); `extra_scripts` registers `patch_arduinopico.py`; `build_src_filter` adds `ipc_serial_stub.cpp`; `lib_deps` override drops `environmental_base`/`environmental_extra`; `lib_ignore += SdFat SD`; adds `MESHTASTIC_EXCLUDE_AIR_QUALITY_SENSOR=1` |
| `variant.h` | Removed `#define DEBUG_RP2040_PORT Serial`; added `#include "ipc_serial_stub.h"` so the `extern Serial` declaration reaches every Meshtastic TU via `configuration.h` |
| `ipc_serial_stub.h` (new) | `IpcSerialStream : public Stream` (no-op read/write, `begin()`/`end()` stubs, `operator bool`); `extern IpcSerialStream Serial;` |
| `ipc_serial_stub.cpp` (new) | Single `IpcSerialStream Serial;` global |
| `patch_arduinopico.py` (new) | Idempotent pre-build script that patches five framework locations: (1) `SerialUSB.h` — `extern SerialUSB Serial;` guarded by `#if !NO_USB` with `// MOKYA_NO_USB_PATCH` marker; (2) `freertos/freertos-main.cpp` — SMP-only calls (`vTaskCoreAffinitySet`, `vTaskPreemptionDisable/Enable`, IdleCoreN task creation) guarded by `#if configNUMBER_OF_CORES > 1`; (3) `freertos/freertos-lwip.cpp` — lwIP task core-affinity call guarded the same way; (4) `FreeRTOS-Kernel/.../RP2350_ARM_NTZ/non_secure/portmacro.h` — added missing `extern volatile uint32_t ulCriticalNesting;` declaration for the single-core path; (5) `.../port.c` — removed the `static` qualifier on `ulCriticalNesting` so `wiring_private.cpp` can link against `portGET_CRITICAL_NESTING_COUNT()`. All blocks marked with `// MOKYA_SMP_PATCH` or `// MOKYA_NO_USB_PATCH`. |

**Upstream Meshtastic latent bug worked around:**
`src/modules/Telemetry/Sensor/AddI2CSensorTemplate.h:17` unconditionally references `ScanI2CTwoWire` under `#if WIRE_INTERFACES_COUNT > 1`, but `ScanI2CTwoWire.h` wraps its body in `#if !MESHTASTIC_EXCLUDE_I2C`. Two-phase name lookup resolves the non-dependent name at template definition time, so the header fails to parse whenever `MESHTASTIC_EXCLUDE_I2C=1` is combined with a telemetry sensor TU that hits `AirQualityTelemetry.cpp`. Workaround: `-DMESHTASTIC_EXCLUDE_AIR_QUALITY_SENSOR=1` (orthogonal to M1.0 — aligned with existing Core 0 no-sensor policy).

**Build result (final, single-core FreeRTOS):**

| Metric | Value |
|---|---|
| RAM | 10.4 % (54 384 / 524 288 bytes) |
| Flash |  7.7 % (283 128 / 3 665 920 bytes) |
| ELF | 4 594 508 bytes |
| BIN | 295 436 bytes |
| UF2 | 591 360 bytes |
| Build time | 79.3 s |

**Flash + boot verification (J-Link, `RP2350_M33_0`):**

1. Download: 327 680 bytes @ 264 KB/s, verified OK.
2. Reset + run, then halt after 1.5 s with HW breakpoint on `setup` (`0x10005AD4`) →
   **hit**. PC = `0x10005AD4`, using PSP (`CONTROL=0x02`), LR = `__core0` FreeRTOS task caller.
   Meshtastic `setup()` reached through Arduino-Pico FreeRTOS task dispatch — proves
   `initVariant()` → `setup()` path works under `-DNO_USB` and Core 0 does not hang
   waiting for `USB.initted` (the `#ifndef NO_USB` guard in `freertos-main.cpp::__core0`
   correctly skips the wait loop).
3. Reset + run, then halt after 5 s with HW breakpoint on `loop` (`0x10005944`) →
   **hit** at CycleCnt ≈ 346 M (~2.3 s at 150 MHz). Meshtastic `setup()` completed and
   `loop()` is executing — full Core 0 firmware boot verified.
4. Between breakpoints, idle PC samples land on `vApplicationIdleHook` (`0x1002A472`),
   i.e. FreeRTOS scheduler is alive and switching to the idle task when `__core0`
   task yields.

**Rationale notes:**
- `DEBUG_RP2040_PORT` removal (A1-lite): Arduino-Pico's `DEBUGV` macro expands to `Serial.printf(...)` inside framework library TUs (e.g. `LittleFS.h`), but those TUs are compiled independently and cannot see our variant-level `Serial` injection. When `DEBUG_RP2040_PORT` is undefined, `debug_internal.h:23-27` makes `DEBUGV` a no-op, which is exactly what Core 0 wants.
- `lib_deps` override dropping `environmental_base`/`environmental_extra`: those sets pull in Adafruit sensor libraries (`Adafruit_BusIO`, `Adafruit_Sensor`, `Adafruit_BMP280`, `Adafruit_DPS310`, `Adafruit_MCP9808`, `Adafruit_INA219/260`, `Adafruit_MPU6050`, `Adafruit_LSM6DS`, `Adafruit_AHTX0`, `Adafruit_LIS3DH`). Their .cpp files reference the framework `Serial` global unconditionally (e.g. `Adafruit_Sensor.cpp:11` has an unguarded `Serial.println(...)`) and compile as independent TUs that never see our stub, so `-DNO_USB` is fatal for them. Core 0 has no sensors anyway.
- `lib_ignore += SdFat SD`: `framework-arduinopico/libraries/SdFat/` has header-inline `ls(&Serial, ...)` methods in `FatFile.h`, `FsFile.h`, `ExFatFile.h`, `FsVolume.h`, `FatVolume.h`, `ExFatVolume.h`. Any TU including these headers fails under `-DNO_USB`. PIO's LDF drags SdFat in because `src/FSCommon.cpp:17` has `#include <SD.h>` gated by `HAS_SDCARD` — LDF doesn't evaluate preprocessor, so the include is always scanned. Core 0 has no SD card.
- Single-core FreeRTOS (option C of M1.0 A3 triage): `rp2350_base.build_flags` inherits `-D__FREERTOS=1` which in Arduino-Pico 5.4.4 defaults to FreeRTOS **SMP** (`configNUMBER_OF_CORES=2`). SMP is fatal for MokyaLora at M1.0: the RP2350 port (`FreeRTOS-Kernel/portable/ThirdParty/GCC/RP2350_ARM_NTZ/non_secure/port.c`) launches Core 1 from Core 0's `xPortStartScheduler` via `multicore_launch_core1(prvDisableInterruptsAndPortStartSchedulerOnCore)`, and Core 1's passive-idle task crashes in `vStartFirstTask` before any user code can run (HardFault with CFSR 0x101 IACCVIOL+IBUSERR, MMFAR = `0x2000C5AC` inside Core 1's own PSP). MokyaLora's architecture plan puts Core 1 under a **separate Apache-2.0 image** (loaded from `0x10200000` in M1.0b onwards), so Core 0's FreeRTOS must stay single-core. Override with `-DconfigNUMBER_OF_CORES=1` (and the three SMP-only feature flags that FreeRTOS requires off in single-core mode: `configUSE_CORE_AFFINITY`, `configRUN_MULTIPLE_PRIORITIES`, `configUSE_TASK_PREEMPTION_DISABLE`). Arduino-Pico's framework sources assume SMP unconditionally, so `patch_arduinopico.py` also guards the SMP call sites in `freertos-main.cpp` / `freertos-lwip.cpp` and fixes the single-core linkage of `ulCriticalNesting` in port.c / portmacro.h.

### M1.0b — Dual-image Core 1 boot spike

**Date:** 2026-04-11
**Result:** ✅ COMPLETE — Core 0 hands execution to a separate Apache-2.0 Core 1 image at flash `0x10200000`; both cores run concurrently and Core 1 writes its sentinel.

**Goal:** Prove Core 0 (Meshtastic, GPL-3.0) can load a minimal Apache-2.0 Core 1 image from a second flash region and launch it via `multicore_launch_core1_raw()`, without sharing any toolchain, linker script, or source tree between the two cores. This validates the license boundary and the dual-image flash layout before M1.1 adds the SPSC IPC ring.

**New files in this repo:**

| File | Purpose |
|---|---|
| `firmware/core1/test/m1_bootspike/src/main_core1_bootspike.c` | Bare-metal Core 1 proof-of-life: zero .bss, write sentinel `0xC1B00701` to `0x20078000`, `dmb`, `wfi` forever. Apache-2.0. No Pico SDK, no libc, no peripherals. |
| `firmware/core1/test/m1_bootspike/memmap_core1_bootspike.ld` | Linker script — FLASH origin `0x10200000`/64 KB, RAM `0x20040000`/64 KB, `__stack_top__ = 0x20050000`, vector table aligned to 128 B in `.vectors`. No boot2, no IMAGE_DEF — Core 1 is launched by Core 0, not by bootrom. |
| `firmware/core1/test/m1_bootspike/CMakeLists.txt` | Standalone CMake project (`-mcpu=cortex-m33 -mthumb -mfloat-abi=softfp -mfpu=fpv5-sp-d16`, `-nostdlib -nostartfiles`, `--gc-sections`). Emits `.elf` + `.bin` via objcopy. |
| `firmware/core1/test/m1_bootspike/toolchain-arm-none-eabi.cmake` | Toolchain file pointing at `arm-none-eabi-gcc` (Arm GNU Toolchain). Sets `CMAKE_TRY_COMPILE_TARGET_TYPE=STATIC_LIBRARY` so CMake doesn't try to link a crt0 during compiler detection. |

**New/changed files in `firmware/core0/meshtastic/variants/rp2350/rp2350b-mokya/` (submodule):**

| File | Change |
|---|---|
| `variant.cpp` (new) | Implements `initVariant()` — reads the Core 1 vector table at `0x10200000` (word[0]=MSP, word[1]=reset handler), calls `multicore_reset_core1()`, then `multicore_launch_core1_raw(entry, sp, 0x10200000)`. Writes four 32-bit debug breadcrumbs to `0x20078010..0x2007801C` (phase marker, Core 1 SP, Core 1 entry, post-launch sentinel snapshot) so the whole boot path can be verified over SWD without a working UART. |
| `platformio.ini` | `build_src_filter += +<../variants/rp2350/rp2350b-mokya/variant.cpp>` |

**Memory layout:**

```
Flash (16 MB W25Q128JW, XIP @ 0x10000000):
  0x10000000..0x101FFFFF   Core 0 Meshtastic image (2 MB window)
  0x10200000..0x1020FFFF   Core 1 bootspike image  (64 KB window)

SRAM (520 KB, base 0x20000000):
  0x20040000..0x2004FFFF   Core 1 bootspike RAM (64 KB; __stack_top__ = 0x20050000)
  0x20078000               Core 1 sentinel (0xC1B00701 when alive)
  0x20078010..0x2007801C   Core 0 debug breadcrumbs (see table below)
```

**Debug breadcrumbs (`0x20078010`):**

| Offset | Meaning |
|---|---|
| `+0x00` | Phase marker: `0x11` entered `initVariant`, `0x12` vector table read, `0x12A` `multicore_reset_core1` returned, `0x13` `multicore_launch_core1_raw` returned, `0x14` sentinel snapshot captured |
| `+0x04` | Core 1 initial SP (should be `0x20050000`) |
| `+0x08` | Core 1 reset handler address (should be `0x102000Dx` with Thumb bit) |
| `+0x0C` | Sentinel value snapshot after Core 0 spins ~100k NOPs (should be `0xC1B00701`) |

**Build commands:**

```sh
# Core 1 bootspike (standalone CMake, bare-metal arm-none-eabi)
cmake -S firmware/core1/test/m1_bootspike \
      -B build/core1_bootspike \
      -DCMAKE_TOOLCHAIN_FILE="$(pwd)/firmware/core1/test/m1_bootspike/toolchain-arm-none-eabi.cmake" \
      -DCMAKE_MAKE_PROGRAM="C:/ProgramData/chocolatey/bin/ninja.exe" \
      -G Ninja
cmake --build build/core1_bootspike

# Core 0 Meshtastic (PlatformIO, from submodule root)
cd firmware/core0/meshtastic
pio run -e rp2350b-mokya
```

**Flash sequence (J-Link Commander, `RP2350_M33_0`):**

```
connect
r
loadfile "<core0 .elf>"                       // flashes 0x10000000 region
loadbin "<core1_bootspike.bin>" 0x10200000    // flashes 0x10200000 region
r
g
qc
```

**Verification (J-Link Commander after run, both cores):**

1. Halt Core 0 (`RP2350_M33_0`), dump memory:
   - `mem32 0x20078000 1` → `0xC1B00701` ✅ (sentinel written by Core 1)
   - `mem32 0x20078010 4` → `0x00000014 0x20050000 0x102000Dx 0xC1B00701` ✅ (all four phases hit)
   - Core 0 PC sample inside `loop()` (Meshtastic) ✅
2. Attach to Core 1 (`RP2350_M33_1`), halt:
   - PC ∈ `0x102000C0..0x102000E0` (inside the bootspike reset handler / WFI loop) ✅
   - MSP = `0x20050000` ✅ (the SP written by our vector table)

**Why `multicore_reset_core1()` is needed (Issue P2-3):**
`multicore_launch_core1_raw()` expects Core 1 to be sitting in the bootrom FIFO handler so the four-word launch handshake (`0, 0, 1, VTOR, SP, ENTRY`) is echoed back correctly. On first entry to `initVariant()` on a cold reset, Core 1 is **not** in that clean state — something in Arduino-Pico / Pico SDK / FreeRTOS single-core startup leaves it either parked somewhere else or with residual FIFO state. Without `multicore_reset_core1()`, Core 0 hangs inside `multicore_launch_core1_raw` (breadcrumb stuck at phase `0x12` — vector table read but `_raw` never returns). Calling `multicore_reset_core1()` first (which asserts `PSM_FRCE_OFF_PROC1` and pushes Core 1 back to the bootrom handler, exactly like Arduino-Pico's own `restartCore1()`) makes the handshake complete immediately. Root cause of the disturbance is deferred — tracked as Issue P2-3.

**Build result (Core 1 bootspike):**

| Metric | Value |
|---|---|
| .text / .rodata | ~240 bytes |
| .bss | 0 |
| ELF | `build/core1_bootspike/core1_bootspike.elf` |
| BIN | `build/core1_bootspike/core1_bootspike.bin` |

**Rationale notes:**
- Bare-metal, no Pico SDK: the spike touches no peripherals and has no libc, so pulling in `pico_sdk` would only add boot2, XIP setup, and runtime init that Core 1 must avoid (Core 0 has already configured XIP and clocks by the time this image runs).
- Vector table at start of flash image: `multicore_launch_core1_raw(entry, sp, vtor)` writes `vtor` into Core 1's `VTOR` register via the bootrom handshake, so the first two words at `0x10200000` *must* be `{MSP, reset_handler|1}`. We don't rely on this for Phase 2 interrupts yet — the spike runs with interrupts off — but keeping the layout honest means M1.1+ can enable Core 1 exceptions without relocating anything.
- `reset_handler` cannot be `static`: the linker script's `ENTRY(reset_handler)` requires an externally visible symbol. Without this the ELF silently falls back to `0x102000C0` and emits a linker warning.
- Stack at `0x20050000`: we reserve 64 KB of SRAM (`0x20040000..0x2004FFFF`) for Core 1 bootspike scratch, well clear of Core 0 FreeRTOS heap (top of SRAM, downward) and the SPSC ring / sentinel area planned at `0x20078000+`.
- `initVariant()` as the launch hook: Arduino-Pico calls `initVariant()` from the `__core0` FreeRTOS task before Meshtastic `setup()`, which means (a) FreeRTOS is already running so we can use normal C++ globals, but (b) no Meshtastic subsystem has started yet so there is no chance of FIFO contention with code that might also want to talk to Core 1 later.

### M1.1-A — Core 1 `m1_bridge` ring validator (bare metal)

**Date:** 2026-04-12
**Result:** ✅ COMPLETE — Core 1 drains `c0_to_c1` ring to completion; head advances from `0x9CB` to `0x1391` (2 502 slots consumed); overflow counter stays at 0.

**Goal:** Successor to the M1.0b bootspike. Same dual-image launch path (`multicore_launch_core1_raw` from Core 0 `initVariant`), but this image is linked against the shared SPSC ring code and actively drains `c0_to_c1` messages + echoes to `c1_to_c0`. No USB yet — M1.1-A proves the ring contract, M1.1-B layers TinyUSB on top.

**New shared/ipc files (MIT, compiled into both cores):**

| File | Purpose |
|---|---|
| `firmware/shared/ipc/ipc_shared_layout.h` | `IpcSharedSram` POD at `0x2007A000..0x20080000` (24 KB), two 32-slot `IpcRingSlot` arrays + 32 B `IpcRingCtrl` blocks with SPSC head/tail/overflow fields. `_Static_assert` on total size. |
| `firmware/shared/ipc/ipc_ringbuf.c/.h` | SPSC push/pop using GCC `__atomic_*` builtins (acquire/release DMB on Cortex-M33); defines `g_ipc_shared` in `.shared_ipc` NOLOAD section; `ipc_shared_init()` zeroes the region and publishes `IPC_BOOT_MAGIC`. |
| `firmware/shared/ipc/ipc_protocol.h` | Added `IPC_MSG_SERIAL_BYTES` (0x06), `IPC_MSG_PANIC` (0xFE), `IPC_MSG_PAYLOAD_MAX`, `IPC_RING_SLOT_COUNT`. |

**New `firmware/core1/m1_bridge/` image (Apache-2.0, bare-metal):**

| File | Purpose |
|---|---|
| `memmap_core1_bridge.ld` | Carves RAM `0x20040000..0x20050000` (64 KB), maps `.shared_ipc` NOLOAD to `SHARED_IPC` region at `0x2007A000` so `nm` reports matching `g_ipc_shared` addresses on both cores. |
| `src/main_core1_bridge.c` | Own `reset_handler` that copies `.data`, zeros `.bss` (but NOT the NOLOAD `.shared_ipc` region), spins on `boot_magic`, pushes a LOG_LINE greeting, stamps `c1_ready`, and loops popping `SERIAL_BYTES` messages and echoing them back. Tiny local `memcpy`/`memset` stubs satisfy `ipc_ringbuf.c` without pulling in newlib (`-nostdlib`). |
| `CMakeLists.txt` | Standalone CMake project, same `-mcpu=cortex-m33 -mthumb -mfloat-abi=softfp` + `-nostdlib -nostartfiles` as the M1.0b bootspike. |

**Critical gotcha:** The bridge MUST NOT `wfe` when the ring is empty — Core 0 `ipc_ring_push` issues no `sev`, so a WFE sleep is terminal. Plain spin works until M1.1-B replaces it with FreeRTOS task scheduling.

**SWD verification:**

| Breadcrumb | Before | After traffic | Meaning |
|---|---|---|---|
| `c0_to_c1_ctrl.head` | `0x9CB` | `0x1391` | Core 0 pushed 2 502 slots |
| `c0_to_c1_ctrl.tail` | — | `0x1391` | Core 1 fully drained |
| `c0_to_c1_ctrl.overflow` | 0 | 0 | No producer back-pressure |
| `boot_magic` | — | `'MOKY'` | Core 0 published `IPC_BOOT_MAGIC` |
| `c1_ready` | 0 | 1 | Core 1 reached `main()` loop |
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

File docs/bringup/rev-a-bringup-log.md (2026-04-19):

# Rev A Bring-Up Log

**Board revision:** Rev A
**Submitted to manufacturer:** 2026-03-22
**Board received:** 2026-04-02
**Bring-up started:** 2026-04-02

For build/flash scripts, shell commands, and source layout see
[bringup-tooling.md](bringup-tooling.md).

---

## Pre-Power Checklist

- [x] Visual inspection: no solder bridges, correct component orientation.
- [x] Continuity check: VSYS, 1.8 V, 3.3 V rails to GND (expect open before power).
- [x] Resistance to GND: VSYS rail > 10 Ω, no short.
- [x] USB-C CC1 / CC2 pull-down resistors (5.1 kΩ) present — USB-C correctly negotiates 5 V.

---

## Bring-Up Sequence

### Step 1 — Power Rails

| Rail | Expected  | Measured | Pass/Fail |
|---|---|---|---|
| VSYS | 3.5–4.2 V | USB-C 5 V input OK | ✅ PASS |
| 1.8 V  | 1.80 V | 1.8 V | ✅ PASS |
| 3.3 V  | 3.30 V | 3.3 V | ✅ PASS |

**Quiescent current:** ~30 mA (measured with firmware loaded; original target < 20 mA was specified for no-firmware condition).

### Step 2 — MCU Boot

**Result: ✅ PASS**

- SWD connect and flash: OK via **J-Link** (Pi Debug Probe incompatible — requires 3.3 V VTREF; MCU logic is 1.8 V — see Issue 7).
- USB CDC / virtual COM port: OK.
- RP2350B USB Hello World example: runs correctly.

### Step 3 — I2C Bus Scan & Sensor Verification

#### Bus Scan

| Address | Device | Bus  | Result | Notes |
|---|---|---|---|---|
| 0x6B | BQ25622 | I2C0 | ✅ PASS | After TP101 fix (Issue 2) |
| 0x55 | BQ27441 | I2C0 | ⚠️ CONDITIONAL | Cold boot NACK — see Issue 9 (BIE) + Issue 10 (latchup). Workaround: boot without battery → charge_on → insert battery |
| 0x6A | LSM6DSV16X | I2C1 | ✅ PASS | |
| 0x1E | LIS2MDL | I2C1 | ✅ PASS | After R54/R55 jumper fix (Issue 3) |
| 0x5D | LPS22HH | I2C1 | ✅ PASS | Address is **0x5D** (SA0 = 3.3 V); design docs incorrectly stated 0x5C — see Issue 4 |
| 0x3A | Teseo-LIV3FL | I2C1 | ✅ PASS | |
| 0x36 | LM27965 | I2C0 | ✅ PASS | |

#### Sensor Live Readings

**LSM6DSV16X IMU (0x6A)** — ✅ PASS

Init sequence per datasheet: SW reset → CTRL3=0x44 (BDU+IF_INC) → CTRL8=0x00 (±2g) → CTRL6=0x01 (±250dps) → CTRL1=0x06 (120 Hz HP) → CTRL2=0x06 (120 Hz HP). STATUS=0x07 (XLDA+GDA+TDA all set).

| Channel | Value | Note |
|---|---|---|
| Accel X/Y/Z | −0.038 / +0.020 / +0.911 g | Z≈1g confirms gravity on horizontal board |
| Gyro X/Y/Z  | +6.95 / +2.41 / −13.73 dps | Static offset; within normal range |
| Temperature | +28.1 °C | Consistent with ambient |

> **Note:** CTRL1/CTRL2 ODR field is `[3:0]` (not `[7:4]` as in older LSM6D devices). Writing `0x40` incorrectly selects ODR-triggered + power-down mode. Correct value for 120 Hz HP mode is `0x06`.

**LPS22HH Barometer (0x5D)** — ✅ PASS

Init sequence: SW reset → CTRL_REG2=0x10 (IF_ADD_INC) → CTRL_REG1=0x02 (BDU, ODR=power-down) → ONE_SHOT trigger → poll STATUS 0x27 until P_DA+T_DA set.

| Channel | Value |
|---|---|
| Pressure | 1004.12 hPa |
| Temperature | 28.12 °C |

> Conversion: `hPa = raw_24bit / 4096.0`; `°C = raw_int16 / 100.0`

**LIS2MDL Magnetometer (0x1E)** — ✅ PASS

Init sequence: SW reset → CFG_REG_A=0x80 (comp_temp_en, 10 Hz, continuous) → CFG_REG_B=0x02 (OFF_CANC every ODR) → CFG_REG_C=0x10 (BDU) → poll STATUS 0x67 bit3 (ZYXDA).

| Channel | Value |
|---|---|
| Mag X/Y/Z | +3.0 / −295.5 / +222.0 mGauss |

> Sensitivity fixed at 1.5 mGauss/LSB. Values consistent with Earth's magnetic field at this location.

**Teseo-LIV3FL GNSS (0x3A)** — ⚠️ CONDITIONAL (I2C streaming confirmed; outdoor RF test pending)

I2C read returns live NMEA sentences. `$PSTMGETSWVER` proprietary command ACKed. Indoor test only — no fix expected. 300-byte stream sample:

| NMEA sentence | Decode |
|---|---|
| `$GNGSA,A,1,…,PDOP=99.0` | Fix=1 (no fix); all satellite slots empty |
| `$GPGLL,…,V` | Position void (no fix) |
| `$PSTMCPU,15.21,-1,98` | ST proprietary: chip temp 15.21 °C, freq ~98 MHz |
| `$GPRMC,033936,V` | Status void; UTC 03:39:36 |
| `$GPGGA,…,0 sats,Fix=0` | 0 satellites tracked |

Teseo-LIV3FL confirmed operational (I2C, NMEA streaming, proprietary commands). **RF chain performance (outdoor fix acquisition, TTFF, sensitivity) not yet tested** — requires outdoor test with clear sky view. See Step 14.

### Step 4 — Display

**Result: ✅ PASS** (via FPC adapter — Rev A connector pinout mismatch bypassed; see Issue 5)

| Item | Result | Notes |
|---|---|---|
| ST7789VI hardware reset | ✅ PASS | nRST GPIO21 toggled correctly |
| ST7789VI init sequence | ✅ PASS | SWRESET → SLPOUT → COLMOD(RGB565) → MADCTL → gamma → CASET/RASET → INVON → DISPON |
| LM27965 backlight (Bank A 40%) | ✅ PASS | brightness code 0x16, GP=0x21 |
| PIO 8080 write (pio1, clkdiv=4) | ✅ PASS | 128 ns write cycle — within ST7789VI 1.8 V VDDI spec |
| Solid colour fills (R/G/B/W/K) | ✅ PASS | Visual confirm |
| SMPTE colour bars (8 × 30 px) | ✅ PASS | Visual confirm |
| Hue gradient + scroll (90 frames) | ✅ PASS | Visible but response sluggish — see Step 13 |
| Checkerboard (32×32 px) | ✅ PASS | Visual confirm |
| Bouncing block (80 frames) | ✅ PASS | Motion smooth at 40 ms/frame |
| Backlight fade (LM27965 Bank A) | ✅ PASS | Smooth fade in/out across all 32 codes |

**Firmware notes:**
- pio1 used (not pio0) to avoid `gpio_base` conflict: pio0 has `gpio_base=16` (set by NAU8315 amp driver for GPIO 30–32); TFT data bus is GPIO 13–20, requiring `gpio_base ≤ 13` → only pio1 (default base=0) is compatible.
- side-set = nWR (GPIO 12); out = D[7:0] (GPIO 13–20); DCX (GPIO 11) and nCS (GPIO 10) CPU-controlled (SIO), as they change only at command/data phase boundaries.
- `tft_flush()` waits TX FIFO empty + 1 µs before toggling DCX, preventing data/command interleave glitches.
- Display inversion (`INVON`, 0x21) required for correct colour on this IPS panel — without it colours are inverted.
- Issue 5 (FPC connector pinout mismatch) bypassed using a FPC adapter board for Rev A validation. Rev B must correct the connector pinout.

### Step 5 — LoRa

**Result: ✅ PASS** (SPI, calibration, RX, TX, RF link all verified — see Step 23 for full TX/RX validation)

| Item | Result | Notes |
|---|---|---|
| SX1262 SPI response | ✅ PASS | GetStatus: ChipMode=2 (STBY_RC), CmdStatus=5 (POR normal) |
| RegSyncWord (0x0740/41) | ✅ PASS | Meshtastic 0x2B → reg 0x20 0xB0 (RadioLib encoding with controlBits=0x00) |
| Calibrate + CalibrateImage | ✅ PASS | GetDeviceErrors = 0x0020 (XOSC flag only — cosmetic false positive, see note) |
| RxGain (0x08AC) | ✅ PASS | Write 0x96, readback 0x96 (boosted LNA confirmed) |
| SetRx → ChipMode=5 | ✅ PASS | RX mode entered successfully |
| RSSI (923.125 MHz, 5 samples) | ✅ PASS | −114.0 dBm consistent (indoor noise floor) |
| GetStats | ✅ PASS | RxOk=0 CrcErr=0 HdrErr=0 (no packets; no crash) |
| OCP (0x08E7) | ✅ PASS | 0x38 = 140 mA (correct formula: value × 2.5 mA). Written after SetPaConfig+SetTxParams |
| TX link test | ✅ PASS | Meshtastic-format TX: TxDone 132 ms (SF9/BW250k); node `!4d4f4b59` visible on mesh — see Step 23 |
| RX link test | ✅ PASS | 25 packets received from node `538EEBE7` (SF9/BW250k, 920.125 MHz, continuous mode, 0 CRC errors) — see Step 23 |
| RF performance (sensitivity, range) | ⏳ PENDING | Requires outdoor test — see Step 15 |

**Firmware notes:**
- GPIO: nRST=23, MISO=24, nCS=25, SCK=26, MOSI=27, BUSY=28, DIO1=29 (matches schematic)
- SPI1, Mode 0, MSB first, 1 MHz; CS controlled manually (not via SPI1_CSn hardware)
- `SetDIO3AsTCXOCtrl` (0x97, voltage=0x02 1.8V, timeout=500 µs) must be called even though TCXO is always-on. Without it PLL calibration fails.
- `GetDeviceErrors = 0x0020` (XOSC_START bit): cosmetic false positive — SX1262 startup-detection flags XOSC even when always-on TCXO is running. Chip is fully functional.

### Step 6 — Keypad

**Result: ✅ PASS**

| Item | Result | Notes |
|---|---|---|
| Matrix scan direction | ✅ PASS | ROW = output (drive LOW), COL = input pull-up; diode Anode=COL / Cathode=ROW enforces this direction |
| All 36 keys detected | ✅ PASS | SW1–SW36 confirmed via key_monitor |
| 1 kΩ series resistors (R90–R101) | ✅ PASS | No impact at 1.8 V: Vf ~0.3 V < VIL 0.54 V with pull-up idle at 1.8 V |

**Firmware (r, c) matrix — confirmed by physical testing:**

| r \ c | C0 | C1 | C2 | C3 | C4 | C5 |
|---|----|----|----|----|----|----|
| R0 | FUNC | BACK | LEFT | DEL | VOL- | UP |
| R1 | 1/2 | 3/4 | 5/6 | 7/8 | 9/0 | OK |
| R2 | Q/W | E/R | T/Y | U/I | O/P | DOWN |
| R3 | A/S | D/F | G/H | J/K | L | RIGHT |
| R4 | Z/X | C/V | B/N | M | ㄡㄥ | SET |
| R5 | MODE | TAB | SPACE | SYM | 。.？ | VOL+ |

> Note: this (r, c) order reflects the physical GPIO-to-switch wiring order in the schematic, not the logical Row/Col in hardware-requirements.md.

**Firmware notes:**
- Bringup scan: GPIO polling, ROW-major (ROW driven LOW one at a time, COL read). Not the production PIO+DMA scan.
- GPIO 36–47 are above the 32-bit GPIO bank boundary; verified functional on RP2350B.
- Initial firmware had scanning direction inverted (COL drive, ROW read = reverse bias = no detection). Corrected to ROW drive / COL read.

### Step 7 — Audio (NAU8315 Amplifier)

**Result: ✅ PASS**

| Item | Result | Notes |
|---|---|---|
| NAU8315 I2S format | ✅ PASS | FSL pin floating → Standard I2S mode confirmed |
| NAU8315 gain | ✅ PASS | GAIN pin floating → Mode 5 = 6 dB (valid, defined state per datasheet) |
| PIO I2S driver | ✅ PASS | 48 828 Hz sample rate (clkdiv=40.0); 16-bit stereo |
| Speaker output | ✅ PASS | Little Bee melody plays correctly at 40% amplitude |

**Firmware notes:**
- GPIO 32 (AMP_DAC_PIN) is above the 32-GPIO boundary. `pio_set_gpio_base(pio0, 16)` **must** be called before `pio_add_program_at_offset()`; calling it after causes `PICO_ERROR_INVALID_STATE` and the state machine silently fails to start.
- Click/pop suppression: transitions between notes push zero samples to FIFO rather than using `sleep_ms`, which would drain the FIFO abruptly.

### Step 8 — Battery & Motor

| Item | Result | Notes |
|---|---|---|
| Vibration motor (HD-EMB1104-SM-2) | ✅ PASS | PWM drive via SSM3K56ACT OK |
| BQ25622 charger I2C + register dump | ✅ PASS | After TP101 fix (Issue 2); see register dump below |
| BQ25622 VREG/IINDPM write + charging enable | ✅ PASS | VREG=4100 mV, IINDPM=100 mA, EN_CHG=1 confirmed; see charging dump below |
| BQ25622 ADC (IBUS/IBAT/VBUS/VPMID/VBAT/VSYS) | ✅ PASS | ADC_EN=1, 12-bit continuous; all 6 channels read correctly |
| BQ27441 fuel gauge I2C presence | ❌ FAIL | NACK even with charging current flowing — Issue 9; SLEEP mode wakeup sequence required |
| BQ27441 SOC / capacity readout | ⏳ PENDING | Blocked by Issue 9 |

**BQ25622 register dump (at power-on, no battery, charging disabled by firmware):**

| Register | Value | Field decode |
|---|---|---|
| PART_INFO (0x38) | 0x0A | PN=1 (BQ25622 ✅), DEV_REV=2 |
| CTRL1 (0x16) | 0x80 | EN_CHG=0 (charging disabled at startup) |
| STATUS0 (0x1D) | 0x10 | VSYS_STAT=1 — no battery; system powered from VBUS only |
| STATUS1 (0x1E) | 0x04 | CHG=Not Charging, VBUS=Unknown Adapter |
| FAULT (0x1F) | 0x00 | No faults ✅ |

> **Register map correction (2026-04-04):** Earlier dump incorrectly listed VREG at 0x06 and IINDPM at 0x00. Correct addresses: VREG = REG0x04 (bytes 0x04/0x05, 10 mV/step, POR=4200 mV); IINDPM = REG0x06 (bytes 0x06/0x07, 20 mA/step, POR=3200 mA). Register 0x00 does not exist. STATUS1 VBUS field for BQ25622 only defines 000/100/111; "Adj. HV DCP" in original dump was the BQ25620 decode — corrected to "Unknown Adapter".

**BQ25622 charging operation dump (VREG=4100 mV, IINDPM=100 mA, battery installed):**

| Register | Value | Field decode |
|---|---|---|
| VREG (0x04/05) | lo=0xD0 hi=0x0C | 4100 mV ✅ |
| IINDPM (0x06/07) | lo=0x50 hi=0x00 | 100 mA ✅ |
| CTRL1 (0x16) | 0xA1 | EN_CHG=1, EN_HIZ=0, WATCHDOG=01 |
| STATUS0 (0x1D) | 0x08 | IINDPM_STAT=1 (100 mA limit active), all others 0 |
| STATUS1 (0x1E) | 0x0C | CHG=CC (Trickle/Pre/Fast), VBUS=Unknown Adapter |
| FAULT (0x1F) | 0x00 | No faults ✅ |

**BQ25622 ADC readings (12-bit continuous, battery installed, charging active):**

| Channel | Value | Notes |
|---|---|---|
| VBUS | 5014 mV | USB-C 5 V input ✅ |
| VPMID | 5002 mV | Mid-point between VBUS and charge path ✅ |
| VBAT | 3966 mV | Battery voltage, BL-4C normal range ✅ |
| VSYS | 3981 mV | System output voltage ✅ |
| IBUS | +84 mA | Input current, within IINDPM=100 mA limit ✅ |
| IBAT | +52 mA | Battery charge current (system load ≈ 32 mA) ✅ |

**Firmware notes:**
- Correct register addresses confirmed from SLUSEG2D: VREG=REG0x04 (10 mV/step), IINDPM=REG0x06 (20 mA/step), ADC_CTRL=REG0x26, ADC_FUNC_DIS=REG0x27.
- `bq25622_enable_charge()` sets VREG and IINDPM before EN_CHG=1; both values confirmed via readback.
- ADC requires explicit enable: write 0x80 to REG0x26 (ADC_EN=1, continuous, 12-bit). POR=disabled. Wait ≥ 300 ms for full channel-scan cycle after enabling.
- REG0x27 (ADC_FUNC_DIS) POR=0x00; all channels enabled by default — no write needed.
- `charge_scan` command: enables charging + 500 ms delay + Bus B I2C scan (to probe BQ27441 wakeup).
- `adc` command: enables ADC (12-bit continuous) + 300 ms wait + reads all 6 channels.

> ICHG POR = 1040 mA (REG0x02, 80 mA/step). Production driver must also configure ICHG, VINDPM (REG0x08), and enable charging via CTRL1[EN_CHG].

**LM27965 register dump (at power-on, all LEDs off):**

| Register | Value | Field decode |
|---|---|---|
| GP (0x10) | 0x20 | All banks disabled ✅ (bit5 always 1 per datasheet) |
| BANK_A (0xA0) | 0xE0 | brightness code = 0 (TFT backlight, off) |
| BANK_B (0xB0) | 0xE0 | brightness code = 0 (keyboard BL + D3B green, off) |
| BANK_C (0xC0) | 0xFC | brightness code = 0 (D1C red indicator, off) |

### Step 9 — Memory (Flash & PSRAM)

| Item | Result | Notes |
|---|---|---|
| W25Q128JW Flash JEDEC ID | ✅ PASS | `EF 60 18` — Winbond W25Q128JW confirmed |
| Flash SR1/SR2/SR3 | ✅ PASS | SR2 QE bit set (QSPI enabled); boot config intact |
| Flash XIP read | ✅ PASS | First 32 bytes match programmed firmware image |
| Internal SRAM (16 KB pattern test) | ✅ PASS | 5 patterns including address-based — all PASS; static used 313 KB / 520 KB (60%), free 206 KB |
| APS6404L PSRAM Read ID | ✅ PASS | `0D 5D 4B 12 A4 31 D5 9F` — APS6404L confirmed (MF=0x0D AP Memory, KGD=0x5D) |
| APS6404L PSRAM SPI write+readback | ✅ PASS | Wrote `DE AD BE EF` @ 0x000000, read back `DE AD BE EF` — MATCH (`psram_probe` direct mode) |
| APS6404L PSRAM XIP write+readback | ✅ PASS | XIP pair: `0xA55A1234` + `0x12345678` — MATCH; 4 KB pattern test (1024 words) — PASS |
| APS6404L PSRAM full capacity (8 MB) | ✅ PASS | Two-pass write+verify (address pattern `0xA5000000\|i`): 2,097,152 words checked — **0 errors** |
| J-Link SWD read of PSRAM | ✅ PASS | `mem32 0x15000000 4` → `DEADBEEF A5A5A5A5 CAFEBABE 12345678` — matches firmware-written sentinel; QMI M1 XIP responds to AHB-AP while CPU halted |

**PSRAM diagnostics (Issue 8 resolved — 3 bugs found and fixed):**

| Bug | Root cause | Fix |
|-----|---|-----|
| SIO register addresses | Used RP2040 offsets; RP2350 has interleaved `GPIO_HI_*` regs | `OUT_SET=0x18, OUT_CLR=0x20, OE_SET=0x38` |
| QMI CS1N ≠ GPIO0 | `ASSERT_CS1N` only drives internal QSPI CS1 pad, not GPIO0 | SIO drives physical CE# + `ASSERT_CS1N` for clock generation |
| PSRAM XIP address | Used `+0x800000` (still M0/Flash); XIP bit 24 selects M0/M1 | Changed to `+0x1000000` (bit 24=1 → M1/CS1) |

**Boot-time PSRAM init** (`psram_init()` in `bringup_sram.c`, called at top of `bringup_repl_init()`):

| Step | Action |
|---|---|
| 1 | GPIO0 = SIO output HIGH (FUNCSEL=5) + internal pull-up (PUE=1, PDE=0) |
| 2 | Enter QMI direct mode, set `ASSERT_CS1N` (for clock generation) |
| 3 | SIO CS toggle: Reset Enable (0x66), Reset (0x99), wait 100 µs, Read ID (0x9F) |
| 4 | Enter QPI (0x35); configure M1: timing (base from M0, CLKDIV=2, RXDELAY=0, COOLDOWN=2), rfmt/rcmd=0xEB (QPI Fast Read, 7 dummy clocks), wfmt/wcmd=0x38 (QPI Write) |
| 5 | Switch GPIO0 to XIP_CS1 (FUNCSEL=9) while still in direct mode (M1 idle) |
| 6 | Clear `ASSERT_CS1N`, exit direct mode → M1 XIP engine takes over GPIO0 |
| 7 | Enable `XIP_CTRL_WRITABLE_M1` for write access via uncached alias (0x15000000) |

**Additional firmware notes (2026-04-05):**
- `psram_full` bringup command: two-pass (write all 8 MB → verify all 8 MB) test using address-based pattern. Progress printed every 1 MB. Confirms full chip capacity and data retention across the entire 8 MB range.
- `psram_jlink` bringup command: writes four sentinel words (`DEADBEEF A5A5A5A5 CAFEBABE 12345678`) to PSRAM XIP uncached base, reads back via firmware, prints J-Link `mem32` command for out-of-band verification.
- RP2350 `XIP_NOCACHE_NOALLOC_BASE` = `0x14000000` (not `0x13000000` as on RP2040); PSRAM uncached XIP address = `0x15000000`.
- J-Link SWD PSRAM access: QMI M1 XIP engine continues to service AHB-AP bus requests while the CPU is halted via SWD. `mem32 0x15000000 N` works reliably for runtime PSRAM inspection and debug.

**XIP speed optimization (2026-04-05):**

PSRAM init upgraded from SPI mode to QPI mode (Enter QPI 0x35, read cmd 0xEB, write cmd 0x38).
DUMMY_LEN empirically determined as 28 bits (7 QPI clocks) — APS6404L needs one extra clock beyond the 6 specified in datasheet (mode byte slot consumed in QPI).

Systematic CLKDIV × RXDELAY sweep (`psram_sweep`, 256 KB per combination, RXDELAY 0–7):

| CLKDIV | RXDELAY | SCK (MHz) | Throughput | Result | Notes |
|---|---|---|---|---|---|
| 1 | 0 | 75 | 300 Mbit/s | ❌ FAIL | ~150–260 errors / 256 KB (0.3 %), random bit errors |
| 1 | 1 | 75 | 300 Mbit/s | ❌ FAIL | ~190–240 errors / 256 KB (0.3 %) |
| 1 | 2–7 | 75 | — | ❌ FAIL | 100 % errors — QMI sampling past valid window |
| **2** | **0** | **37.5** | **150 Mbit/s** | **✅ PASS** | **0 errors / 256 KB; 8 MB full validation: 0 errors** |
| 2 | 1–7 | 37.5 | — | ❌ FAIL | 100 % errors |
| 3 | 0–7 | 25 | — | ❌ FAIL | 100 % errors — RXDELAY=0 already past valid window |

Flash (`W25Q128JW`) speed sweep (`flash_sweep`, single-word vector table read):

| CLKDIV | RXDELAY | SCK (MHz) | Throughput | Result | Notes |
|---|---|---|---|---|---|
| 1 | 0–3 | 75 | 300 Mbit/s | ❌ FAIL | Reads 0x00000000 |
| 2 | 0 | 37.5 | 150 Mbit/s | ❌ FAIL | Byte-shifted: `0x82000200` |
| **2** | **1–3** | **37.5** | **150 Mbit/s** | **✅ PASS** | Expected `0x20082000` confirmed |
| 3–4 | 0–3 | 25/18.75 | 100/75 Mbit/s | ✅ PASS | Conservative, all pass |

**CLKDIV=1 (75 MHz) error analysis** (`psram_diag`, read-only at 75 MHz after safe 37.5 MHz write):
- 10-run reproducibility: 132–260 errors per 256 KB (0.2–0.4 %), non-deterministic across boot cycles.
- COOLDOWN (0–3), MIN_DESELECT (1–31), PAGEBREAK (none/256/1024/4096) tuning: no improvement — errors are not boundary-related.
- Write+read both at 75 MHz: only 38–64 errors (read/write phase offsets partially cancel), confirming consistent clock-phase shift rather than random noise.
- APS6404L-SQH is rated for 144 MHz — 75 MHz is 52 % of IC rating. Bottleneck is QMI sampling + PCB signal integrity, not PSRAM IC speed.
- Note: earlier sweep runs showed inflated error counts because COOLDOWN=0/MIN_DESELECT=1 test combos violated APS6404L tCPH ≥ 18 ns, corrupting PSRAM QPI state for subsequent reads.

**CLKDIV=3 (25 MHz) QPI failure root cause:**
- Original PSRAM init (SPI mode, cmd=0x03) used M0.timing copy (CLKDIV=3/RXDELAY=2) and worked at 25 MHz.
- QPI mode has higher QMI internal pipeline latency than SPI (simultaneous 4-line latch vs single-line). At CLKDIV=3, RXDELAY=0 already exceeds the valid sampling window — would need negative RXDELAY (impossible). SPI mode is unaffected because single-line capture has lower pipeline depth.
- M0 (Flash) boot2 timing: `0x60007203` = CLKDIV=3, RXDELAY=2, COOLDOWN=1. Flash uses Quad SPI (cmd=single-wire), not full QPI — same lower pipeline depth as SPI.
- Confirmed by diagnostic: RXDELAY phase-shift pattern shows each +1 CLKDIV shifts the baseline sample point by one RXDELAY step (3.33 ns), leaving no valid RXDELAY at CLKDIV=3.

**Final production configuration:**

| Bus | Device | Mode | CLKDIV | RXDELAY | SCK | Throughput | Source |
|-----|---|---|---|---|-----|---|---|
| M0 (Flash) | W25Q128JW | Quad SPI | 3 | 2 | 25 MHz | 100 Mbit/s | boot2 default |
| M1 (PSRAM) | APS6404L | QPI | 2 | 0 | 37.5 MHz | 150 Mbit/s | `psram_init()` |

PSRAM QPI at 37.5 MHz = 150 Mbit/s — a **6× improvement** over the original SPI 25 MHz (25 Mbit/s). Flash can be upgraded to CLKDIV=2/RXDELAY=1 (37.5 MHz, 150 Mbit/s) from RAM in future firmware.

**Rev B note:** Add external 4.7 kΩ pull-up to VCC_1V8 on **both** QSPI chip selects: QSPI_SS (Flash CS0) and GPIO0 (PSRAM CS1). GPIO0 boots with PDE=1 (pull-down), causing PSRAM CE# LOW at power-on → bus contention with Flash on shared QSPI bus. Both CS lines should be held HIGH during boot to prevent either device from being spuriously selected.
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

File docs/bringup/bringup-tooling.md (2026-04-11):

# Bringup Tooling Reference

Reference document for the MokyaLora Rev A bringup shell: build/flash scripts, source
layout, and automated test runner usage. Intended to be loaded as context at the start of
each bringup or debug session.

---

## Hardware Setup

- **Debugger:** SEGGER J-Link (supports 1.8 V VTREF — required for RP2350B)
- **Serial port:** auto-detected by USB VID `0x2E8A` (Raspberry Pi), 115200 baud, USB CDC (RP2350B USB). COM number varies per host and enumeration order — all scripts call `scripts/_mokya-port.ps1::Resolve-MokyaPort`; pass `-PortName COMxx` to override.
- **SWD connection:** SWCLK / SWDIO / GND on board test points
- **Power:** USB-C 5 V input (VSYS via BQ25622)

> Pi Debug Probe is **incompatible** — requires 3.3 V VTREF; RP2350B logic is 1.8 V.

---

## Build & Flash Scripts

All build, flash, and serial helper scripts live in `scripts/`. Run from project root.

| Script | Location | Purpose |
|---|---|---|
| `configure_bringup.sh` | `scripts/` | CMake configure only (run once or after CMakeLists change) |
| `build_bringup.sh` | `scripts/` | Incremental build only (no flash) |
| `build_and_flash_bringup.sh` | `scripts/` | Full build + J-Link flash + reset |
| `flash_bringup.sh` | `scripts/` | Flash pre-built ELF only (no build step) |
| `serial_monitor.ps1` | `scripts/` | Interactive serial terminal |
| `bringup_run.ps1` | `scripts/` | Automated command runner (send commands, capture output) |
| `firmware/tools/recv_pcm_dump.py` | `firmware/tools/` | Binary PCM receiver for `mic_dump` command |

### Build & Flash

```bash
# First time: configure CMake (run from project root in Git Bash)
bash scripts/configure_bringup.sh

# Subsequent builds: incremental build only
bash scripts/build_bringup.sh
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

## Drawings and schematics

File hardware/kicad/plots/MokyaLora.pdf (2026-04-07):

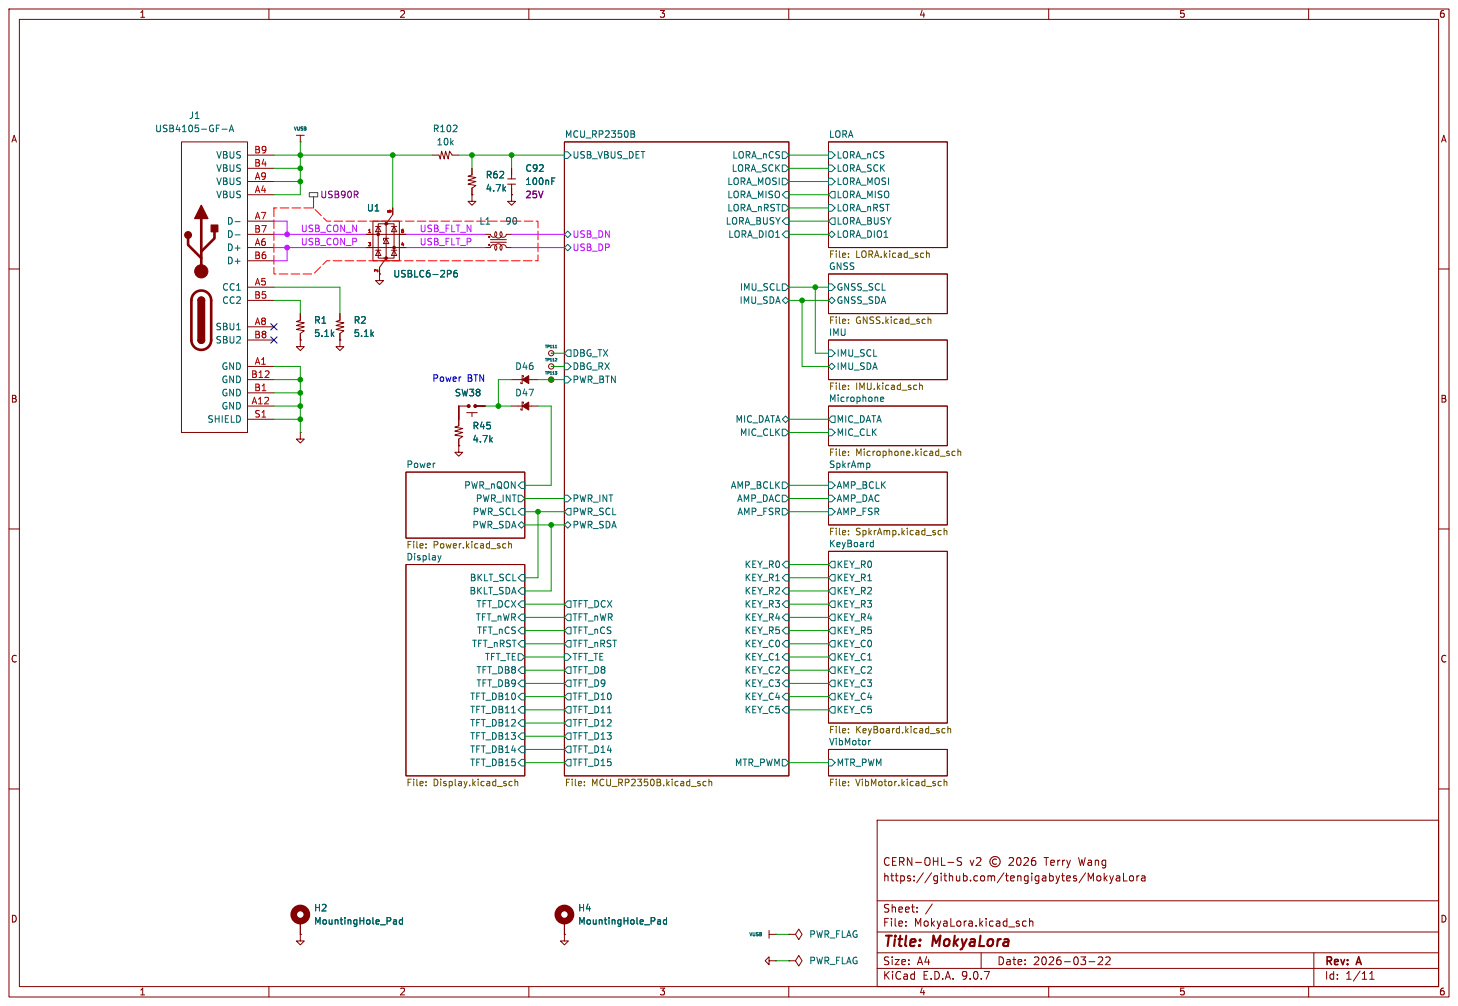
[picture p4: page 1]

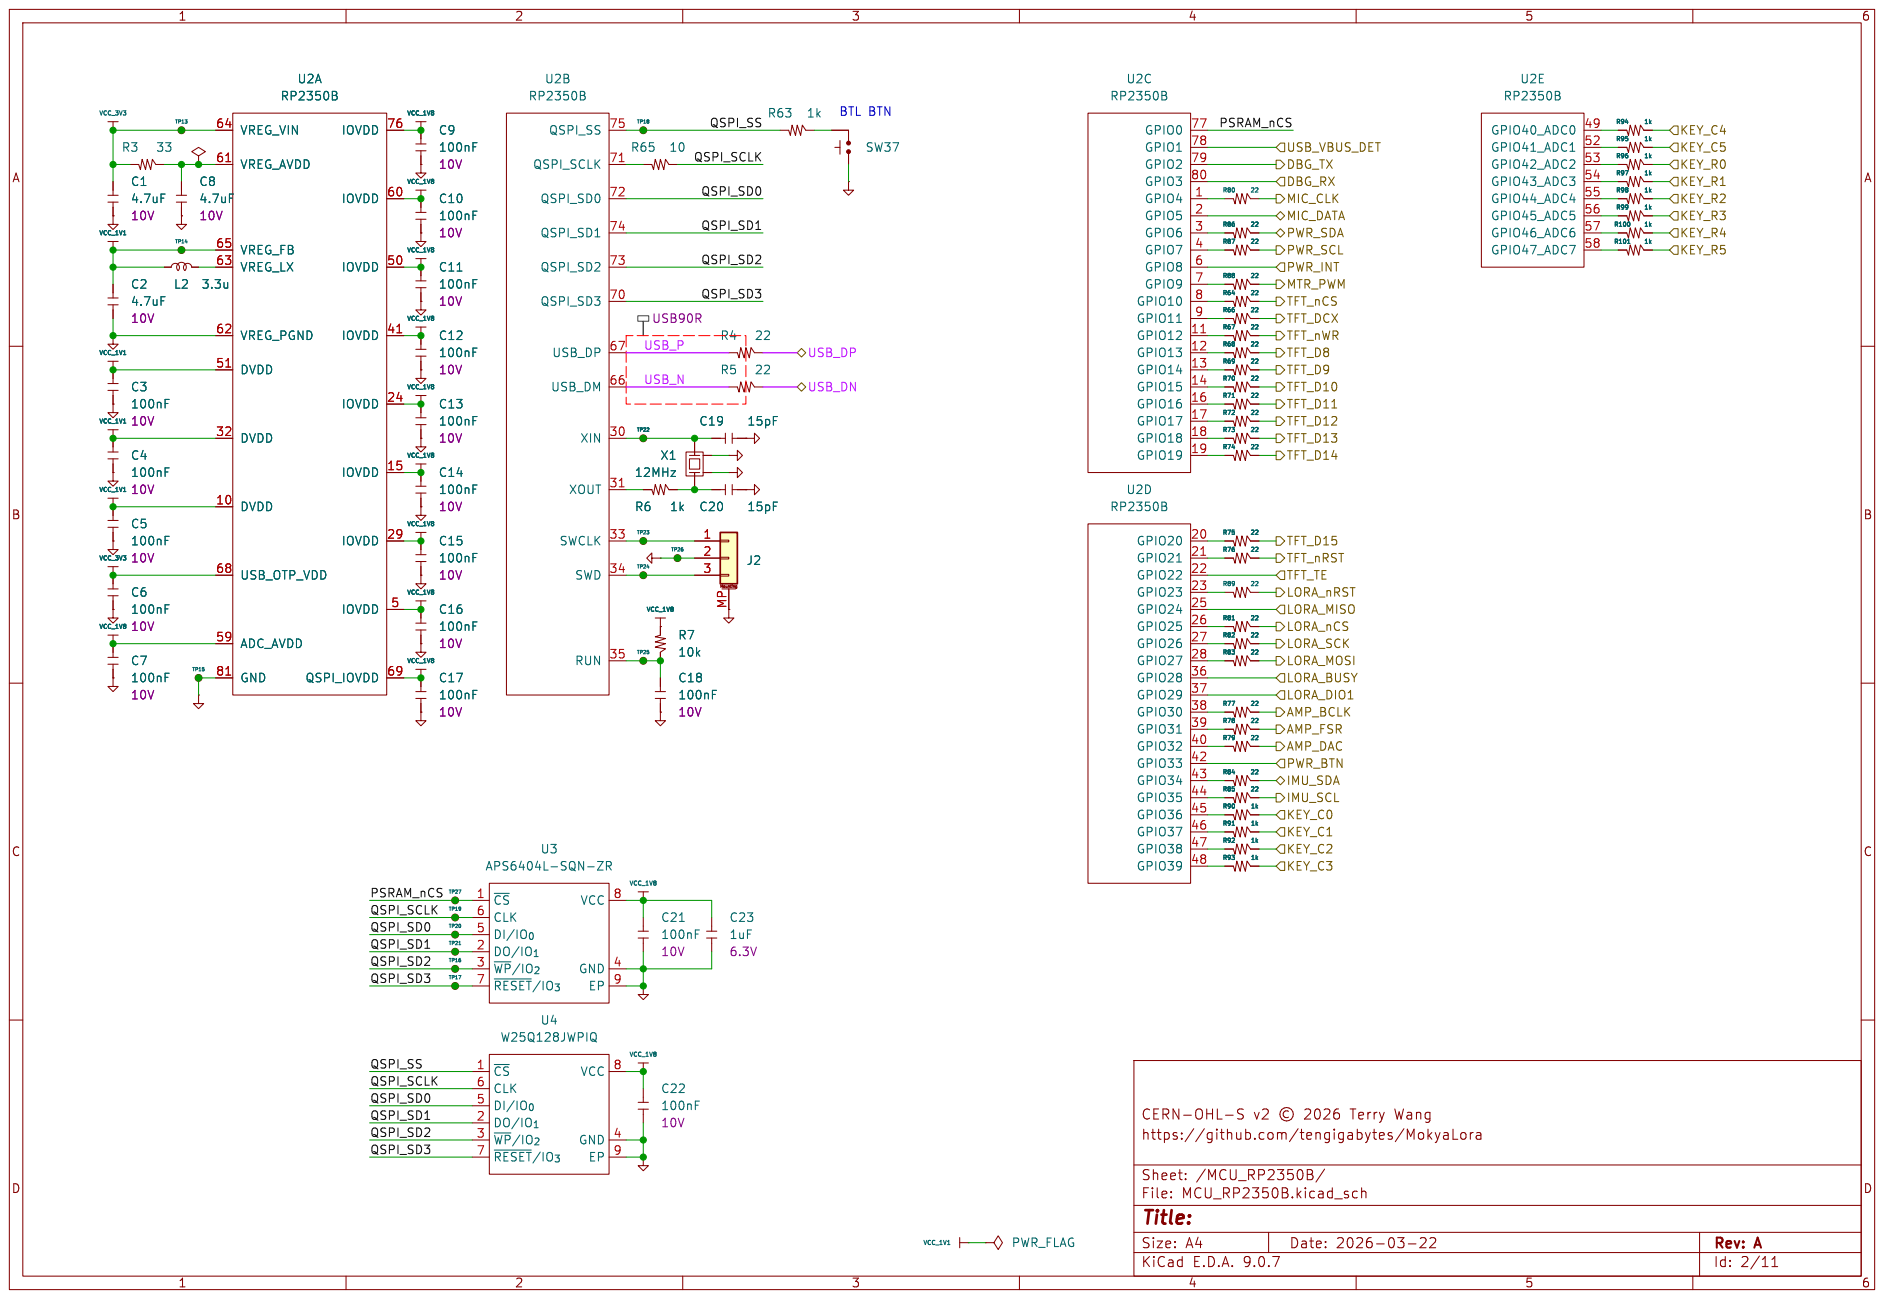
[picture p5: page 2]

VREG_VIN 64 VREG_AVDD 61 VREG_FB 65 VREG_LX 63 VREG_PGND 62 DVDD 51 DVDD 32 DVDD 10 USB_OTP_VDD 68 ADC_AVDD 59 GND 81

Id: 2/11 Title: File: MCU_RP2350B.kicad_sch Sheet: /MCU_RP2350B/

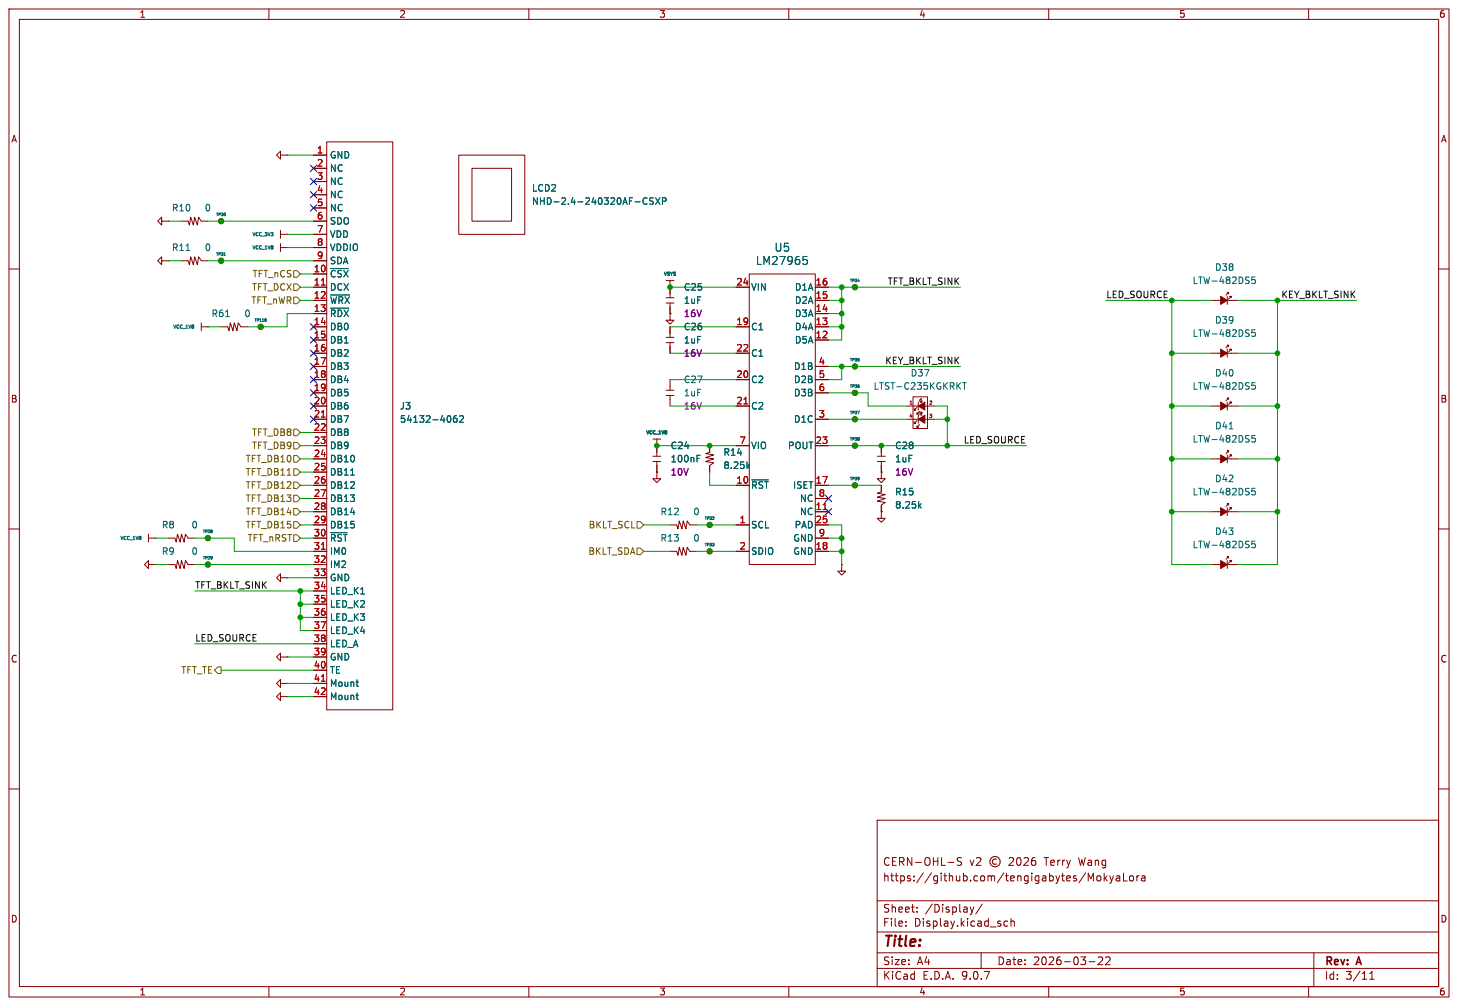
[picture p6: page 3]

Id: 3/11 Title: File: Display.kicad_sch Sheet: /Display/

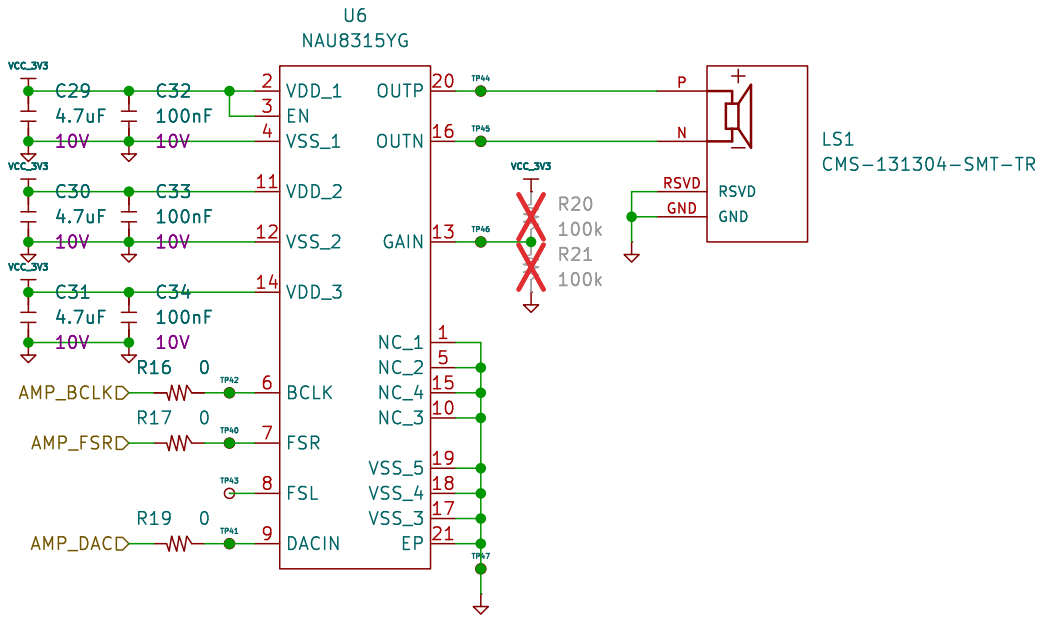
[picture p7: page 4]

Id: 4/11 Title: File: SpkrAmp.kicad_sch Sheet: /SpkrAmp/

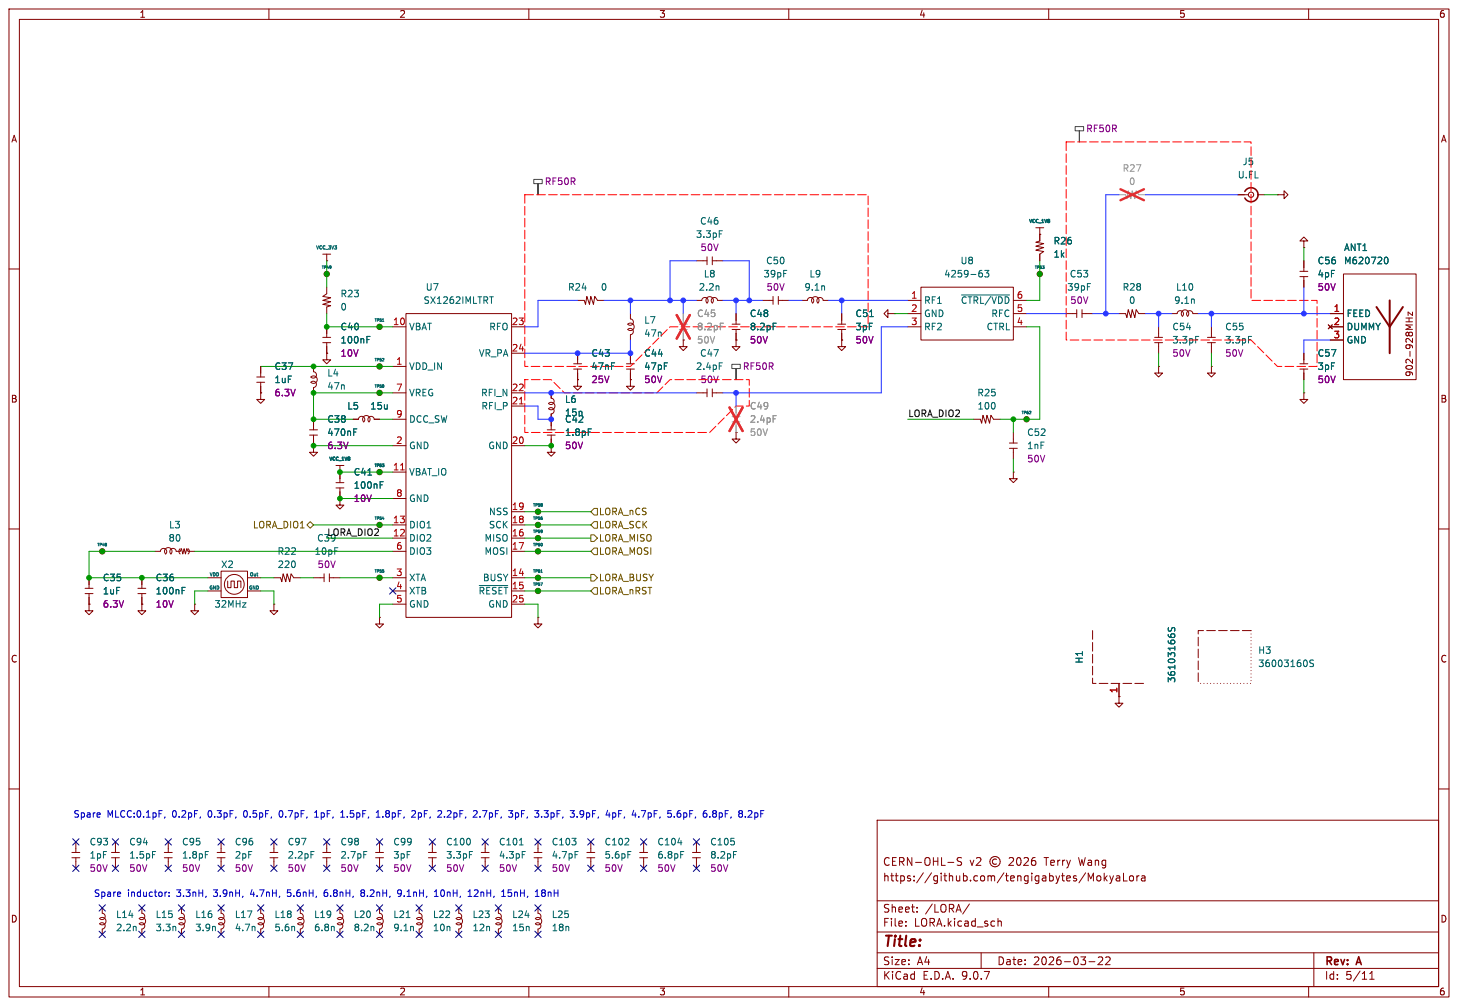
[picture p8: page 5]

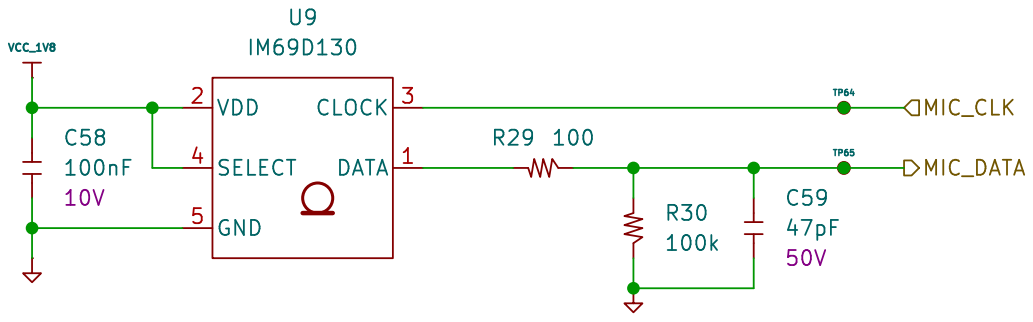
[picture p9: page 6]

Id: 6/11 Title: File: Microphone.kicad_sch Sheet: /Microphone/

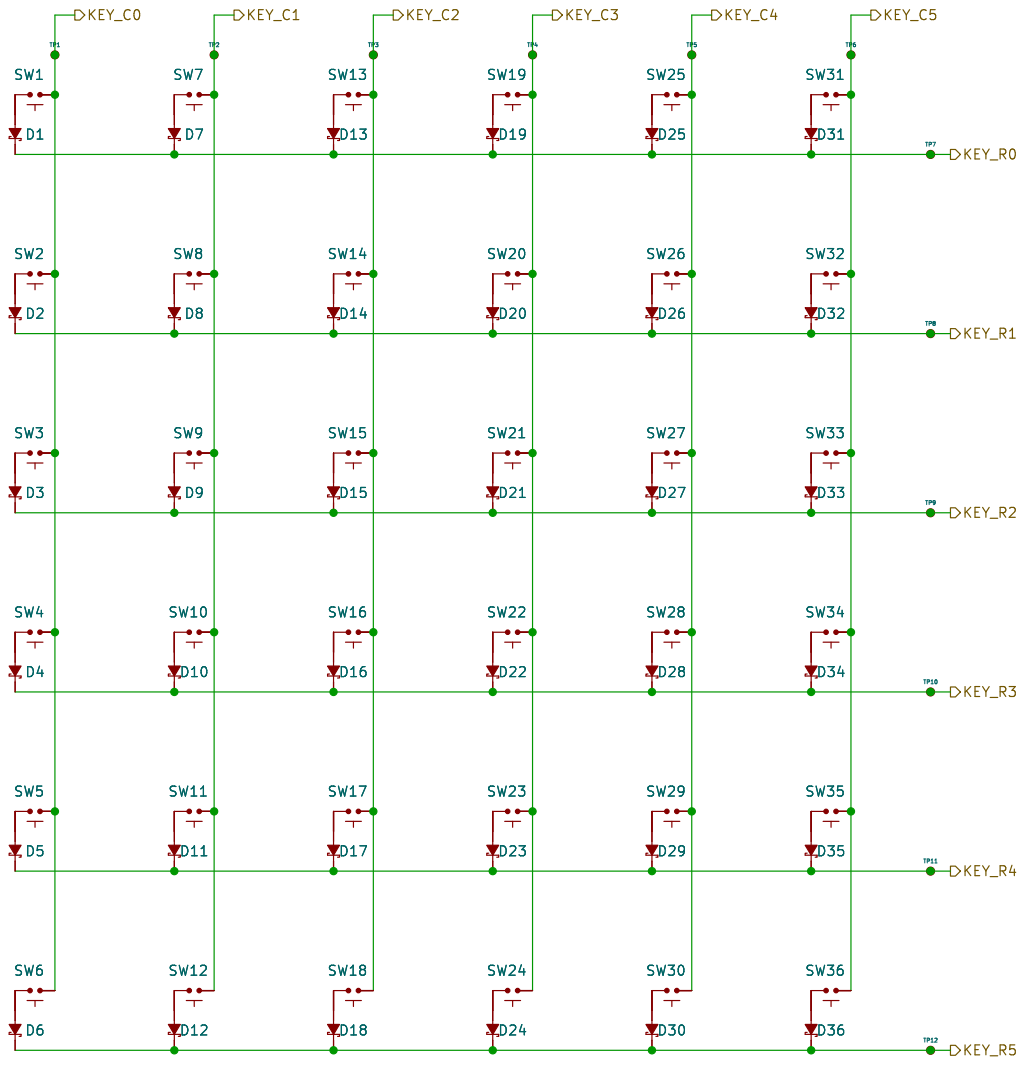
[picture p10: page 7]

TP3 SW4
D19 | D25 SW25 SW18 SW28 | TP8 SW21 D21 SW22

Id: 7/11 Title: File: KeyBoard.kicad_sch Sheet: /KeyBoard/

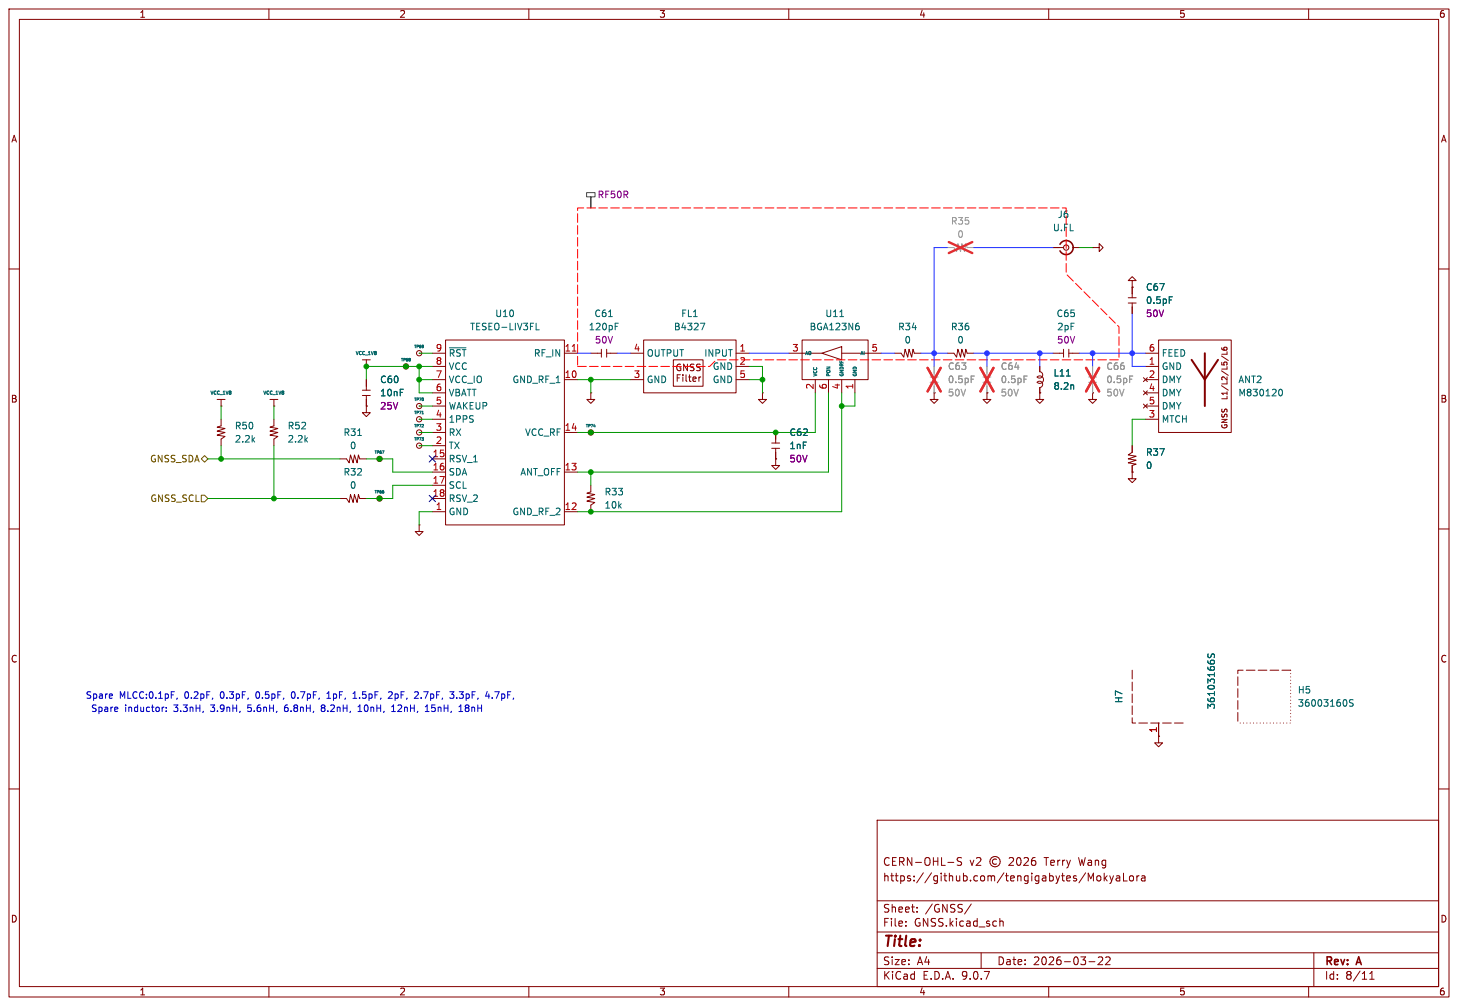
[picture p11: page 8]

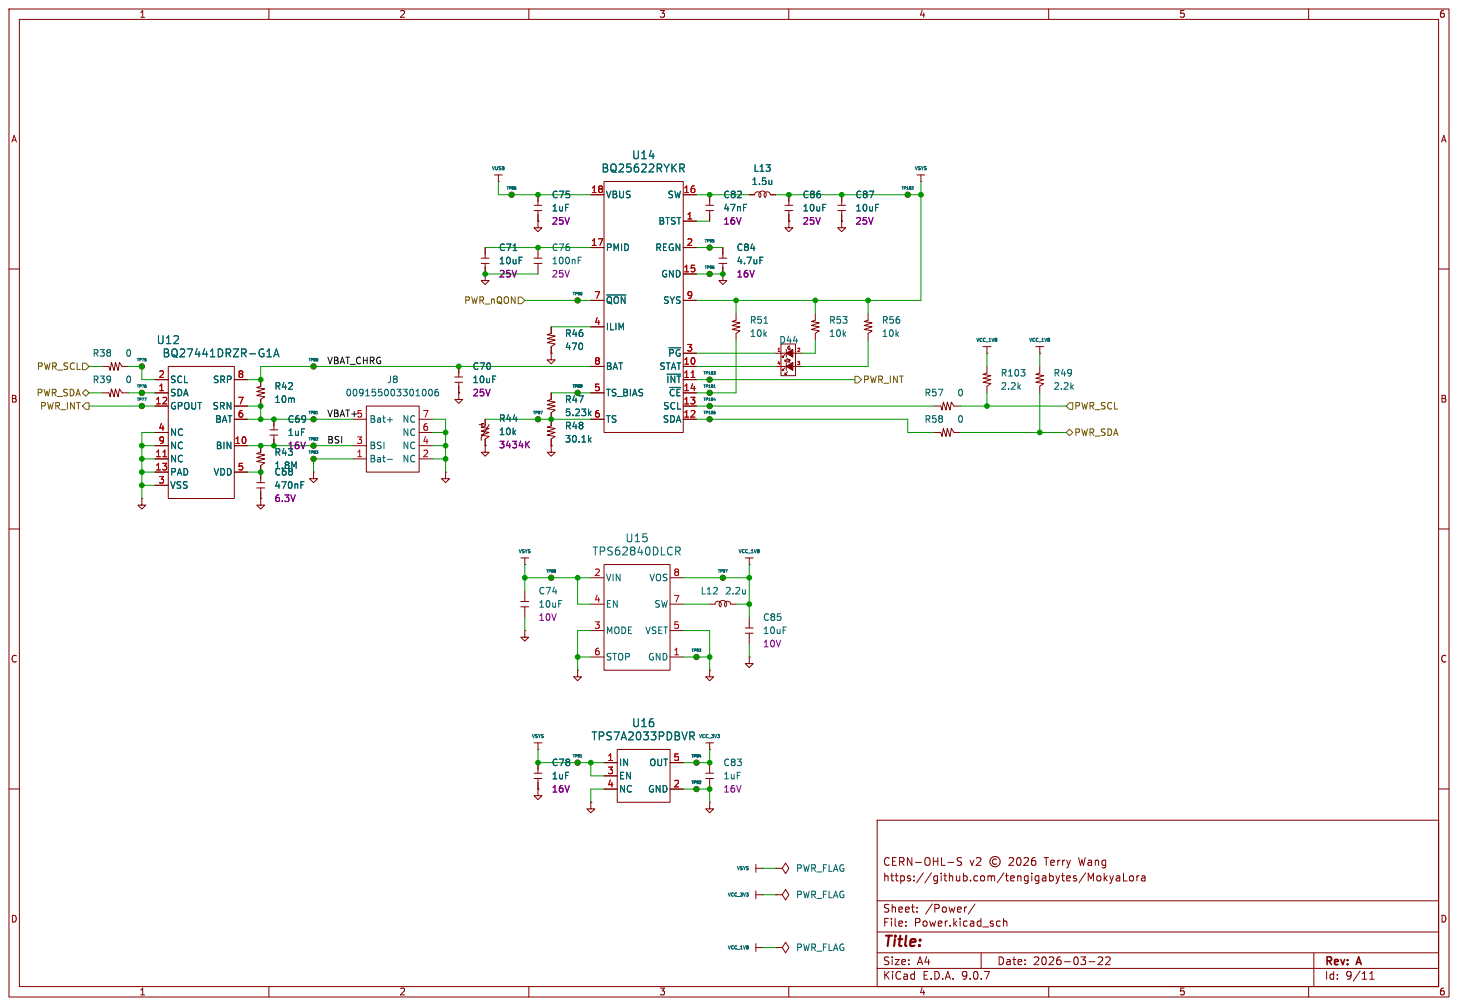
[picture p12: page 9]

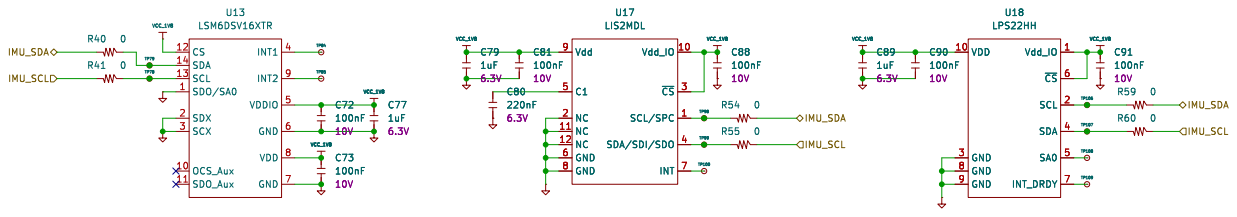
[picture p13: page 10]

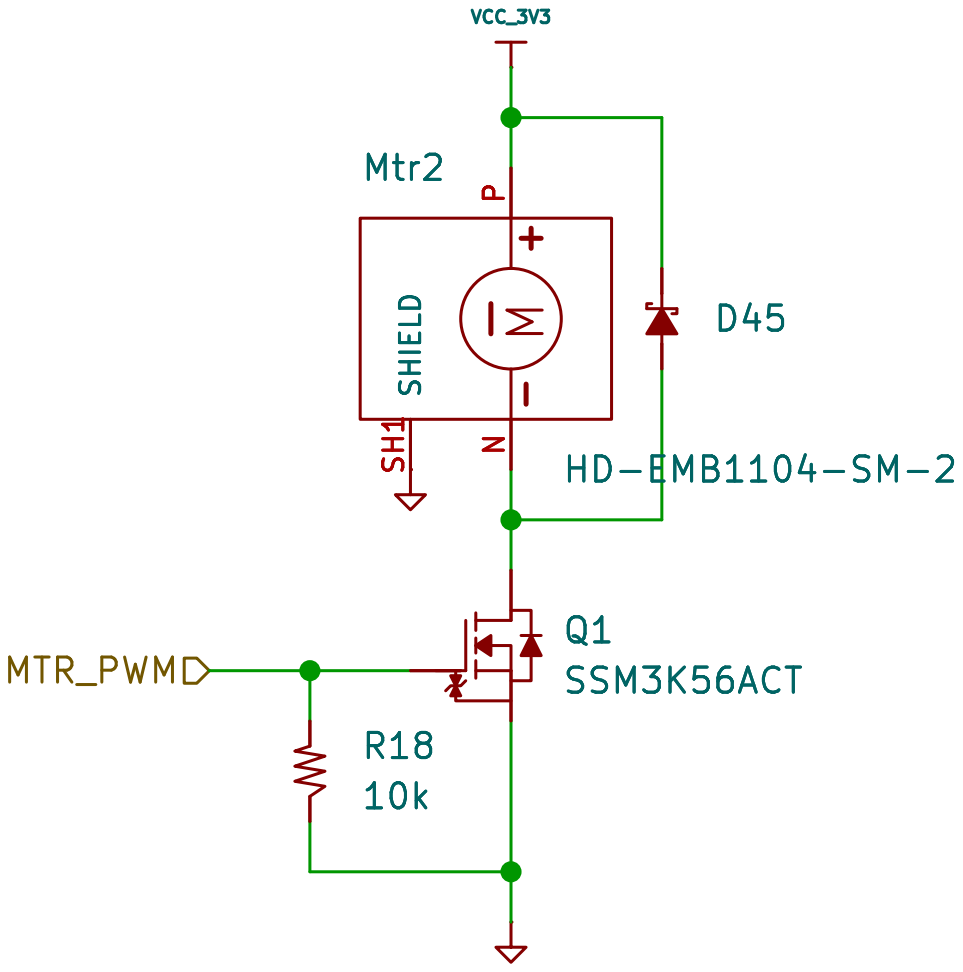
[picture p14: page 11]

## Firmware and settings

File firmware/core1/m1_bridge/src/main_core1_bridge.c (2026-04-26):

/* MokyaLora Phase 2 M1.1-B — Core 1 USB↔SPSC bridge (Pico SDK)
 *
 * Successor to the M1.1-A bare-metal ring validator. This image boots as a
 * full Pico SDK application: SDK crt0 + runtime_init (with dangerous hooks
 * skipped, see CMakeLists.txt PICO_RUNTIME_SKIP_INIT_* defines) + FreeRTOS
 * RP2350_ARM_NTZ port + TinyUSB device stack.
 *
 * Vector table:
 *   Provided by pico-sdk/src/rp2_common/pico_crt0/crt0.S — 48 slots, first
 *   word = __StackTop, second word = _reset_handler, all ISR slots weakly
 *   aliased to isr_invalid. TinyUSB's dcd_rp2040 installs the USBCTRL IRQ
 *   handler at runtime via irq_set_exclusive_handler(). FreeRTOS port
 *   installs SVC/PendSV/SysTick via exception_set_exclusive_handler() at
 *   scheduler start, writing into the SDK's ram_vector_table (populated by
 *   runtime_init_install_ram_vector_table on boot).
 *
 * Boot handshake (same as M1.1-A):
 *   1. Core 0 calls ipc_shared_init() which zeroes g_ipc_shared and stores
 *      IPC_BOOT_MAGIC in boot_magic as the "ready" doorbell.
 *   2. Core 0 calls multicore_launch_core1_raw(), which reads SP/PC from
 *      flash 0x10200000 and wakes Core 1.
 *   3. Core 1 SDK crt0 runs runtime_init hooks, calls main().
 *   4. main() stamps the M1.1-B sentinel (0xC1B01200) at 0x20078000 and
 *      spins on g_ipc_shared.boot_magic until it sees IPC_BOOT_MAGIC. This
 *      is belt-and-braces: Core 0 sets boot_magic BEFORE launching us, so
 *      the first read should already see it.
 *   5. main() resets USBCTRL, calls tusb_init(), and busy-polls tud_task()
 *      for ~2 s so the host PC enumerates the CDC device.
 *   6. main() publishes c1_ready = 1 and pushes a greeting log line into
 *      c1_to_c0.
 *   7. main() creates usb_device_task + bridge_task and starts the
 *      FreeRTOS scheduler. It never returns.
 *
 * Operational counters (SWD-readable via `mem32`, survive resets as long as
 * RAM is not cleared). Every new slot must be registered in
 * firmware-architecture.md §9.3 before use; see feedback on breadcrumb
 * lifecycle discipline — solved-issue breadcrumbs are released in the fix
 * commit, not left as permanent fixtures:
 *   0x2007FFC4  rx total   — bytes drained from c0_to_c1 ring (→ CDC IN)
 *   0x2007FFC8  tx total   — bytes drained from CDC OUT (→ c1_to_c0 ring)
 *   0x2007FFCC  usb state  — bit0=mounted, bit1=cdc_connected (DTR)
 *
 * Note on tud_cdc_connected() vs tud_mounted():
 *   tud_cdc_connected() returns true only after the host sends
 *   SET_CONTROL_LINE_STATE with the DTR bit set. pyserial (and hence the
 *   Meshtastic CLI) does this by default, but Chrome WebSerial, some Linux
 *   /dev/ttyACM consumers, and Meshtastic's web console do not. We therefore
 *   gate CDC writes on tud_mounted() instead (USB enumerated) and rely on a
 *   bounded FIFO-full retry to drop bursts when no client is actually reading
 *   — this way the bit-0 mounted bit reflects "can forward data" and bit-1 is
 *   just diagnostic.
 *
 * SPDX-License-Identifier: Apache-2.0
 */

#include <stdint.h>
#include <string.h>

#include "pico/stdlib.h"
#include "hardware/irq.h"
#include "hardware/resets.h"
#include "hardware/regs/resets.h"
#include "hardware/sync.h"
#include "hardware/structs/sio.h"
#include "tusb.h"
#include "pico/platform/panic.h"

#include "FreeRTOS.h"
#include "task.h"

#include "ipc_protocol.h"
#include "ipc_shared_layout.h"
#include "ipc_ringbuf.h"

#include "i2c_bus.h"
#include "bq25622.h"
#include "sensor_task.h"
#include "gps_task.h"
#include "display.h"
#include "lvgl_glue.h"
#include "keypad_scan.h"
#include "key_event.h"
#include "key_inject.h"
#include "key_inject_rtt.h"
#include "messages_inbox.h"
#include "messages_tx_status.h"
#include "nodes_db.h"

volatile uint32_t g_core1_boot_heap_free = 0;
#include "psram.h"
#include "mie_dict_loader.h"
#include "ime_task.h"

#include "mokya_trace.h"

/* Dict pointers stay file-scope; ime_task_start takes a pointer to it. */
static mie_dict_pointers_t s_mie_dict = {0};

/* ── Doorbell IPC notification (M2) ─────────────────────────────────────── *
 * We use raw SIO register writes instead of pico_multicore API to avoid
 * runtime_init side effects from linking pico_multicore into Core 1.       */
#define NOTIFY_BIT_IPC  (1u << 0)
#ifndef SIO_IRQ_BELL
#define SIO_IRQ_BELL  26   /* RP2350 doorbell IRQ (secure) */
#endif

static TaskHandle_t g_bridge_task_handle;

static inline void doorbell_set_other_core(uint32_t num)
{
    sio_hw->doorbell_out_set = 1u << num;
}

static inline void doorbell_clear_own(uint32_t num)
{
    sio_hw->doorbell_in_clr = 1u << num;
}

/* ── Operational counters in .shared_ipc tail pad ──────────────────────── */
/* Last 64 B of .shared_ipc — guaranteed outside Core 0's heap & task stacks.
 * Registered slots only (see firmware-architecture.md §9.3).                */
#define BRIDGE_RX_COUNT_ADDR   0x2007FFC4u
#define BRIDGE_TX_COUNT_ADDR   0x2007FFC8u
#define BRIDGE_USB_STATE_ADDR  0x2007FFCCu

#define USB_STATE_MOUNTED      (1u << 0)
#define USB_STATE_CDC          (1u << 1)

static inline void dbg_u32(uintptr_t addr, uint32_t val)
{
    *(volatile uint32_t *)addr = val;
}

static volatile uint32_t g_rx_total;
static volatile uint32_t g_tx_total;

/* ── Flash-park handler (MUST reside in RAM — runs while XIP is off) ───── *
 *
 * Called from the doorbell ISR when Core 0 requests a flash write.
 * Protocol:
 *   1. Core 0 sets flash_lock = REQUEST, fires IPC_FLASH_DOORBELL
 *   2. This ISR catches the doorbell, ACKs with flash_lock = PARKED, __SEV()
 *   3. Disables all interrupts on Core 1 (SysTick, USB, etc.)
 *   4. Spins in RAM until Core 0 clears flash_lock back to IDLE + __SEV()
 *   5. Re-enables interrupts and returns — scheduler resumes
 *
 * The __no_inline_not_in_flash_func attribute guarantees the function body
 * and all local data are placed in .time_critical (SRAM), not .text (flash).
 */
static void __no_inline_not_in_flash_func(flash_park_handler)(void)
{
    /* ACK: tell Core 0 we are safely parked */
    __atomic_store_n(&g_ipc_shared.flash_lock,
                     IPC_FLASH_LOCK_PARKED, __ATOMIC_RELEASE);
    __sev();  /* wake Core 0 polling on flash_lock */

    /* Kill ALL interrupts on this core — no SysTick, no USB, nothing
     * can trigger a flash fetch while XIP is off. */
    uint32_t saved = save_and_disable_interrupts();

    /* Spin in RAM until Core 0 clears the lock. __wfe() is a low-power
     * wait; Core 0 will __sev() after the flash operation completes. */
    while (__atomic_load_n(&g_ipc_shared.flash_lock,
                           __ATOMIC_ACQUIRE) != IPC_FLASH_LOCK_IDLE) {
        __wfe();
    }

    restore_interrupts(saved);
}

/* ── Doorbell ISR — Core 0 ring push wakes bridge_task ──────────────────── */

static void __no_inline_not_in_flash_func(ipc_doorbell_isr)(void)
{
    /* Check flash-park doorbell FIRST — time-critical */
    if (sio_hw->doorbell_in_set & (1u << IPC_FLASH_DOORBELL)) {
        doorbell_clear_own(IPC_FLASH_DOORBELL);
        if (__atomic_load_n(&g_ipc_shared.flash_lock,
                            __ATOMIC_ACQUIRE) == IPC_FLASH_LOCK_REQUEST) {
            flash_park_handler();
        }
    }

    /* Normal IPC ring doorbell */
    if (sio_hw->doorbell_in_set & (1u << IPC_DOORBELL_NUM)) {
        doorbell_clear_own(IPC_DOORBELL_NUM);
        if (g_bridge_task_handle != NULL) {
            BaseType_t xHigherPriorityTaskWoken = pdFALSE;
            xTaskNotifyFromISR(g_bridge_task_handle, NOTIFY_BIT_IPC,
                               eSetBits, &xHigherPriorityTaskWoken);
            portYIELD_FROM_ISR(xHigherPriorityTaskWoken);
        }
    }
}

/* ── FreeRTOS tasks ──────────────────────────────────────────────────────── */

/* TinyUSB polling task. OPT_OS_NONE means tud_task() is a non-blocking
 * poll — we call it as fast as practical while still yielding to the
 * bridge task via taskYIELD(). */
static void usb_device_task(void *pv)
{
    (void)pv;
    for (;;) {
        tud_task();
        /* Cooperative yield — no 1 ms floor, so the bridge task runs
         * immediately after each TinyUSB poll. */
        taskYIELD();
    }
}

/* Byte bridge task.
 *   c0_to_c1 ring  ->  tud_cdc_write_n  (host sees Meshtastic output)
 *   tud_cdc_read_n ->  c1_to_c0 ring    (host input reaches Meshtastic)
 *
 * Both directions use IPC_MSG_SERIAL_BYTES slots. Ring slots carry up to
 * IPC_MSG_PAYLOAD_MAX (256 B) at a time; we pass the whole slot straight to
 * TinyUSB. If the TinyUSB TX fifo is full we wait a tick and retry — the
 * c0_to_c1 ring is 32 × 264 B = 8 KB, which is plenty to buffer any burst
 * while the host drains its end.
 */
static void bridge_task(void *pv)
{
    (void)pv;

    uint8_t scratch[IPC_MSG_PAYLOAD_MAX];
    uint8_t tx_seq = 0;
    bool reboot_pending = false;

    /* Enable doorbell IRQ now that the FreeRTOS scheduler is running and
     * PendSV/SVC handlers are installed.  Any pending doorbells from
     * Core 0 during the pre-scheduler busy-wait will fire immediately. */
    irq_set_enabled(SIO_IRQ_BELL, true);

    for (;;) {
        /* If Core 0 announced a reboot, stop all ring/CDC processing and
         * idle until the watchdog fires the chip-wide reset. */
        if (reboot_pending) {
            vTaskDelay(pdMS_TO_TICKS(100));
            continue;
        }

        bool did_work = false;

        /* ── c0_to_c1 DATA ring → CDC IN (high priority) ───────────── */
        IpcMsgHeader hdr;
        if (ipc_ring_pop(&g_ipc_shared.c0_to_c1_ctrl,
                         g_ipc_shared.c0_to_c1_slots,
                         IPC_RING_SLOT_COUNT,
                         &hdr,
                         scratch,
                         sizeof(scratch))) {

            /* ── Message dispatch ─────────────────────────────────────── */
            if (hdr.msg_id == IPC_MSG_REBOOT_NOTIFY) {
                /* Core 0 is about to watchdog-reset the chip.  Gracefully
                 * disconnect USB so the host drops the COM port handle
                 * before the hard reset yanks the controller out. */
                tud_disconnect();
                reboot_pending = true;
                did_work = true;
                continue;   /* skip the rest of this iteration */
            }

            if (hdr.msg_id == IPC_MSG_NODE_UPDATE &&
                hdr.payload_len >= sizeof(IpcPayloadNodeUpdate)) {
                const IpcPayloadNodeUpdate *u =
                    (const IpcPayloadNodeUpdate *)scratch;
                uint16_t header_size =
                    (uint16_t)offsetof(IpcPayloadNodeUpdate, alias);
                uint8_t alias_len = u->alias_len;
                if ((uint16_t)header_size + alias_len > hdr.payload_len) {
                    /* defend against producer-side length lie */
                    alias_len = (uint8_t)(hdr.payload_len - header_size);
                }
                nodes_db_upsert(u->node_id,
                                u->rssi,
                                u->snr_x4,
                                u->hops_away,
                                u->lat_e7,
                                u->lon_e7,
                                u->battery_mv,
                                u->alias,
                                alias_len);
                did_work = true;
                continue;
            }

            if (hdr.msg_id == IPC_MSG_TX_ACK &&
                hdr.payload_len >= sizeof(IpcPayloadTxAck)) {
                const IpcPayloadTxAck *a =
                    (const IpcPayloadTxAck *)scratch;
                messages_tx_status_publish(a->seq,
                                           a->result,
                                           a->error_reason,
                                           a->packet_id);
                did_work = true;
                continue;
            }

            if (hdr.msg_id == IPC_MSG_RX_TEXT &&
                hdr.payload_len >= sizeof(IpcPayloadText)) {
                /* Structured RX text from Core 0 — surface in LVGL inbox.
                 * Snapshot stays valid only until the next RX_TEXT push,
                 * which is fine for the current "show latest" view.
                 * Multi-message backlog is M5 Phase 2 work. */
                const IpcPayloadText *t =
                    (const IpcPayloadText *)scratch;
                uint16_t header_size = (uint16_t)offsetof(IpcPayloadText, text);
                uint16_t text_in_payload =
                    (hdr.payload_len > header_size)
                        ? (uint16_t)(hdr.payload_len - header_size)
                        : 0u;
                uint16_t text_len = t->text_len;
                if (text_len > text_in_payload) text_len = text_in_payload;
                messages_inbox_publish(t->from_node_id,
                                       t->to_node_id,
                                       t->channel_index,
                                       t->text,
                                       text_len);
                did_work = true;
                continue;
            }
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
int main(void)
{
    /* Zero operational counters in the tail pad so SWD sees 0 before the
     * bridge task starts publishing real values. */
    dbg_u32(BRIDGE_RX_COUNT_ADDR,   0u);
    dbg_u32(BRIDGE_TX_COUNT_ADDR,   0u);
    dbg_u32(BRIDGE_USB_STATE_ADDR,  0u);
    __dmb();

    /* RTT trace transport up — see mokya_trace.h. The control block lives
     * at &_SEGGER_RTT in BSS; J-Link / OpenOCD / pyOCD all auto-discover it.
     * Init must run before any TRACE() call. Cheap (~50 instructions),
     * does not touch hardware, safe to call before the boot_magic spin. */
    SEGGER_RTT_Init();
    TRACE_BARE("core1", "boot");

    /* 2. Wait for Core 0's shared-SRAM publication. Core 0 writes
     * IPC_BOOT_MAGIC before it launches us, so this should observe the
     * ready value on the very first load — but we spin defensively in
     * case of a cold-boot race. */
    while (__atomic_load_n(&g_ipc_shared.boot_magic, __ATOMIC_ACQUIRE)
           != IPC_BOOT_MAGIC) {
        __asm volatile ("yield");
    }

    /* 3. Force USB re-enumeration.
     *
     * Core 0 / SDK runtime may have left USBCTRL in a half-initialised state
     * — e.g. after J-Link SWD reset Windows never sees a disconnect event
     * because D+ pullup stayed high. Resetting the USBCTRL block drops D+,
     * holding for 20 ms guarantees the host detects disconnect, and then
     * unreset_block_wait releases it so tusb_init() can do a clean start.
     * This is the same pattern proven in firmware/tools/bringup/
     * core1_rtos_efgh.c (Step 16 Stage B2). */
    reset_block(RESETS_RESET_USBCTRL_BITS);
    busy_wait_ms(20);
    unreset_block_wait(RESETS_RESET_USBCTRL_BITS);

    /* 4. Bring TinyUSB up (registers USBCTRL_IRQ via irq_set_exclusive_handler
     * inside dcd_rp2040_init). */
    tusb_init();

    /* 5. Busy-poll tud_task() long enough for the host to enumerate the CDC
     * device before we hand off to FreeRTOS. 2000 iterations × 1 ms =~ 2 s.
     * This is what Stage B2 does — it's not strictly required (the USB
     * device task will keep polling after scheduler starts) but it means
     * the COM port shows up before Meshtastic starts logging, so we don't
     * lose the boot banner. */
    for (int i = 0; i < 2000; i++) {
        tud_task();
        busy_wait_ms(1);
    }

    /* 6. Announce ourselves on the c1_to_c0 ring. Matches M1.1-A greeting. */
    {
        const IpcPayloadLogLine hdr = {
            .level    = 1u, /* INFO */
            .core     = 1u,
            .text_len = 16u,
        };
        uint8_t packet[sizeof(hdr) + 16u];
        memcpy(packet, &hdr, sizeof(hdr));
        memcpy(packet + sizeof(hdr), "core1 bridge up", 16u);
        (void)ipc_ring_push(&g_ipc_shared.c1_to_c0_ctrl,
                            g_ipc_shared.c1_to_c0_slots,
                            IPC_RING_SLOT_COUNT,
                            IPC_MSG_LOG_LINE,
                            0u,
                            packet,
                            (uint16_t)sizeof(packet));
    }

    __atomic_store_n(&g_ipc_shared.c1_ready, 1u, __ATOMIC_RELEASE);

    /* PSRAM (APS6404L, 8 MB at 0x11000000). Done before any driver so
     * allocations that want PSRAM can succeed from task-start. Core 0
     * does not initialise PSRAM (Arduino-Pico's psram.cpp is gated on
     * RP2350_PSRAM_CS which we do not define), so Core 1 owns it. The
     * read-ID result lands in g_psram_read_id[] for SWD inspection;
     * failure here is logged but non-fatal (IME will panic later when
     * it tries to copy the dict blob). */
    (void)psram_init();

    /* Copy the MDBL dict blob from flash partition (0x10400000) to
     * PSRAM. Status in g_mie_dict_load_status; on failure s_mie_dict
     * is zeroed and the future ime_task will refuse to start. */
    (void)mie_dict_load_to_psram(&s_mie_dict);


    /* Shared I2C bus (time-muxed i2c1). Creates s_bus_mutex and sets
     * the default pinmux to the POWER pair. MUST run before any task
     * that calls i2c_bus_acquire(): lvgl_task (lm27965 backlight),
     * charger_task, sensor_task, gps_task. The call was accidentally
     * dropped in M4 Step 3 when PSRAM init was added — restored here. */
    i2c_bus_init_all();

    /* 7. Register doorbell ISR but do NOT enable yet — enabling before the
     *    FreeRTOS scheduler starts causes a HardFault because portYIELD_FROM_ISR
     *    triggers PendSV before the port has installed the PendSV handler.
     *    The IRQ is enabled at the start of bridge_task (after scheduler runs). */
    irq_set_exclusive_handler(SIO_IRQ_BELL, ipc_doorbell_isr);

    /* 8. Hand off to FreeRTOS.
     *
     * Every task-start is checked. Silent failures here caused a whole
     * class of "HardFault in vTaskStartScheduler" debugging sessions —
     * see phase2-log.md M3.4.5d. The panic message names the failing
     * task so the USB CDC log points straight at the culprit.
     *
     * Heap budget is documented in docs/design-notes/core1-memory-budget.md;
     * keep that file and the stack depths here in sync. */
    #define TASK_START_OR_PANIC(expr, name) \
        do { if (!(expr)) { panic("core1: " name " task_start failed"); } } while (0)

    /* Both tasks at the same priority so taskYIELD() round-robins
     * between them without the 1 ms vTaskDelay floor. */
    TASK_START_OR_PANIC(
        xTaskCreate(usb_device_task, "usb", 1024, NULL,
                    tskIDLE_PRIORITY + 2, NULL) == pdPASS,
        "usb");
    TASK_START_OR_PANIC(
        xTaskCreate(bridge_task, "bridge", 1024, NULL,
                    tskIDLE_PRIORITY + 2, &g_bridge_task_handle) == pdPASS,
        "bridge");

    /* LVGL service task runs at the same priority as usb / bridge so the
     * round-robin scheduler hands it CPU between their yields. A lower
     * priority would be starved by usb_device_task's tight tud_task()
     * + taskYIELD() loop. lvgl_task owns display_init() — main() must not
     * also call it. */
    TASK_START_OR_PANIC(lvgl_glue_start(tskIDLE_PRIORITY + 2), "lvgl");

    /* KeyEvent queue — allocate before creating keypad_scan_task so the
     * very first debounce commit (possible within ~20 ms of boot if a
     * key is held) finds the queue ready. Producer/consumer are both
     * future tasks; only the scan task enqueues in Phase B. */
    key_event_init();

    /* Keypad scan task — MUST run at the same priority as usb / bridge / lvgl.
     * usb_device_task is a `tud_task(); taskYIELD();` loop with no blocking
     * call, so it is always Ready at priority tskIDLE_PRIORITY + 2. Under
     * preemptive scheduling, any strictly-lower-priority task is starved.
     * Equal priority enables round-robin time-slicing, giving keypad its
     * slot between the 5 ms debounce pauses. 512-word stack is plenty
     * for the loop with 6-byte local raw buffer and no nested calls. */
    TASK_START_OR_PANIC(
        xTaskCreate(keypad_scan_task, "kpad", 512, NULL,
                    tskIDLE_PRIORITY + 2, NULL) == pdPASS,
        "kpad");

    /* Charger (BQ25622) 1 Hz poll task — hw init runs inside the task so
     * first I2C traffic is post-scheduler, after i2c_bus mutex is usable. */
    TASK_START_OR_PANIC(bq25622_start_task(tskIDLE_PRIORITY + 2), "chg");

    /* Sensor bus poll task (M3.4.5). LPS22HH + LIS2MDL + LSM6DSV16X on
     * a shared 10 Hz tick with per-sensor divider counters. */
    TASK_START_OR_PANIC(sensor_task_start(tskIDLE_PRIORITY + 2), "sens");

    /* GNSS task (M3.4.5d). Runs separately from sensor_task — NMEA drain
     * cadence is 100 ms, faster than the 1/10 Hz sensor tick, and the
     * line-accumulator parser carries state between ticks. */
    TASK_START_OR_PANIC(gps_task_start(tskIDLE_PRIORITY + 2), "gps");

    /* IME task (M4). Consumes the KeyEvent queue, drives mie::ImeLogic,
     * and exposes composition / candidate / commit state for the LVGL
     * view via the ime_view_* getter API. Priority +3 one notch above
     * the other app tasks so keystrokes get processed before the next
     * LVGL frame. If the dict copy-at-boot failed the pointers are
     * zeroed and ime_task_start returns false → panic, which is the
     * right behaviour (IME unusable means nothing to do). */
    TASK_START_OR_PANIC(ime_task_start(&s_mie_dict, tskIDLE_PRIORITY + 3),
                        "ime");
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

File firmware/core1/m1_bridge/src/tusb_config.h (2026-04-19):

/*
 * tusb_config.h — MokyaLora Phase 2 M1.1-B Core 1 m1_bridge
 *
 * Device-only TinyUSB configuration: single CDC interface, no MSC/HID/other
 * classes. CDC transfer buffers sized generously (1024 B each direction) to
 * absorb burst traffic from Meshtastic's serial console while the host
 * drains it at full-speed USB rates.
 *
 * Pico SDK's tinyusb_device target automatically sets CFG_TUSB_MCU to
 * OPT_MCU_RP2040 (which covers RP2350 as well — same dcd_rp2040 port).
 *
 * SPDX-License-Identifier: MIT
 */

#ifndef _TUSB_CONFIG_H_
#define _TUSB_CONFIG_H_

#ifdef __cplusplus
extern "C" {
#endif

/* ── Board / RHPort ─────────────────────────────────────────────────────── */
#ifndef BOARD_TUD_RHPORT
#define BOARD_TUD_RHPORT      0
#endif

#ifndef BOARD_TUD_MAX_SPEED
#define BOARD_TUD_MAX_SPEED   OPT_MODE_DEFAULT_SPEED
#endif

/* ── Common ─────────────────────────────────────────────────────────────── */
#ifndef CFG_TUSB_MCU
#error CFG_TUSB_MCU must be defined
#endif

/* CFG_TUSB_OS is set by the Pico SDK (tinyusb_device target) to OPT_OS_PICO,
 * which wires TinyUSB's internal sync primitives to hardware_mutex. That is
 * compatible with calling tud_task() from both a busy-poll loop (before the
 * scheduler starts) and a FreeRTOS task (after it starts), because hardware
 * mutexes don't depend on the scheduler. We intentionally do NOT override it
 * here — the SDK's -D from the command line wins. */
#define CFG_TUSB_DEBUG        0

#define CFG_TUD_ENABLED       1
#define CFG_TUD_MAX_SPEED     BOARD_TUD_MAX_SPEED

/* Legacy tusb_init(void) expects CFG_TUSB_RHPORT0_MODE to pick the mode+speed
 * of roothub port 0. OPT_MODE_DEVICE | OPT_MODE_FULL_SPEED matches our single
 * CDC-device configuration running off RP2350's full-speed USB controller. */
#define CFG_TUSB_RHPORT0_MODE (OPT_MODE_DEVICE | OPT_MODE_FULL_SPEED)

#define CFG_TUSB_MEM_SECTION
#define CFG_TUSB_MEM_ALIGN    __attribute__((aligned(4)))

/* ── Device configuration ───────────────────────────────────────────────── */
#define CFG_TUD_ENDPOINT0_SIZE    64

/* Exactly one CDC interface, nothing else. */
#define CFG_TUD_CDC              1
#define CFG_TUD_MSC              0
#define CFG_TUD_HID              0
#define CFG_TUD_MIDI             0
#define CFG_TUD_VENDOR           0

/* CDC FIFOs — the TX fifo absorbs Meshtastic boot log bursts, RX fifo is
 * only touched by user input from the host (meshtastic CLI commands). */
#define CFG_TUD_CDC_RX_BUFSIZE   1024
#define CFG_TUD_CDC_TX_BUFSIZE   1024

/* USB packet buffer. 64 B is full-speed bulk max. */
#define CFG_TUD_CDC_EP_BUFSIZE   64

#ifdef __cplusplus
}
#endif

#endif /* _TUSB_CONFIG_H_ */

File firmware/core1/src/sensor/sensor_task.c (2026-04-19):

/* sensor_task.c — single-task scheduler for all sensor-bus drivers.
 *
 * M3.4.5a carries only LPS22HH (1 Hz). As LIS2MDL (M3.4.5b) and
 * LSM6DSV16X (M3.4.5c) land, they slot into the same tick loop with
 * divider counters so each runs at its own ODR without creating extra
 * tasks. The bus is time-muxed i2c1 (see i2c_bus.h); concurrent access
 * from multiple tasks would just serialise on the mutex anyway.
 *
 * SPDX-License-Identifier: Apache-2.0
 */

#include "sensor_task.h"

#include "FreeRTOS.h"
#include "task.h"

#include "lis2mdl.h"
#include "lps22hh.h"
#include "lsm6dsv16x.h"

#define TICK_PERIOD_MS          100u  /* 10 Hz master tick */
#define LPS22HH_PERIOD_TICKS    10u   /* 1 Hz poll                          */
#define LIS2MDL_PERIOD_TICKS    1u    /* 10 Hz poll (matches device ODR)    */
#define LSM6DSV16X_PERIOD_TICKS 1u    /* 10 Hz poll (device ODR = 30 Hz,
                                       * BDU guarantees fresh sample)      */
#define INIT_RETRY_MS           500u

static void sensor_task(void *pv)
{
    (void)pv;

    /* Init each sensor, retrying forever so a late-plug or brown-out
     * recovery brings the driver online without host intervention. Each
     * retry pauses briefly so the bus isn't hammered. */
    while (!lps22hh_init()) {
        vTaskDelay(pdMS_TO_TICKS(INIT_RETRY_MS));
    }
    while (!lis2mdl_init()) {
        vTaskDelay(pdMS_TO_TICKS(INIT_RETRY_MS));
    }
    while (!lsm6dsv16x_init()) {
        vTaskDelay(pdMS_TO_TICKS(INIT_RETRY_MS));
    }

    TickType_t last = xTaskGetTickCount();
    uint32_t   tick = 0;
    for (;;) {
        if ((tick % LPS22HH_PERIOD_TICKS) == 0) {
            (void)lps22hh_poll();
        }
        if ((tick % LIS2MDL_PERIOD_TICKS) == 0) {
            (void)lis2mdl_poll();
        }
        if ((tick % LSM6DSV16X_PERIOD_TICKS) == 0) {
            (void)lsm6dsv16x_poll();
        }
        tick++;
        vTaskDelayUntil(&last, pdMS_TO_TICKS(TICK_PERIOD_MS));
    }
}

bool sensor_task_start(UBaseType_t priority)
{
    /* 512 words (2 KB): biggest locals are the 5-byte baro burst and i2c
     * SDK call frames; headroom for future IMU 12-byte burst + SFLP
     * quaternion decode. */
    BaseType_t rc = xTaskCreate(sensor_task, "sens", 512, NULL, priority, NULL);
    return rc == pdPASS;
}

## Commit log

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2026-03-22 Add KiCad hardware design files and production outputs (rev-a)
    - hardware/kicad/: full KiCad 8 project — schematics (13 sheets),
    PCB layout, project symbols, custom footprints (MokyaLora.pretty/,
    61 footprints), and component 3D models (packages3D/, 67 models)
    - hardware/production/rev-a/gerber/: Gerber + drill files (6-layer)
    - hardware/production/rev-a/pdf/: schematic PDF + assembly drawing PDF
    - hardware/production/rev-a/MokyaLora.step: full-board 3D export
    Also add:
    - .gitattributes: enforce LF for text/KiCad files; mark STEP/STP/WRL
    and PDF as binary to prevent line-ending corruption
    - .gitignore: add .claude/ exclusion; remove *.kicad_dru so design
    rules are version-controll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
    [BtryChrgr.kicad_sch, Display.kicad_sch, GNSS.kicad_sch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]
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2026-04-06 bringup: Step 18-19 interactive menu, regression test suite, TFT restructure
    Add LCD menu system with keyboard navigation (8 category pages, 51+ commands),
    serial priority state machine, and screen rotation. Restructure TFT tests:
    slow test keeps solid colors only, patterns moved to DMA fast test. Add
    automated regression test script (bringup_test_all.ps1) with 20 tests across
    7 groups. Update KiCad schematics (sheet numbering + BOM datasheet links).
    Steps 18-19 and Issue 13 recorded in bringup log.
    [Display.kicad_sch, GNSS.kicad_sch, IMU.kicad_sch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]
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2026-04-12 phase2: M1.2-B — yield optimization + TX accumulation buffer (2.6× speedup)
    Core 1: replace vTaskDelay(1ms) with taskYIELD(), equalize task priorities.
    Core 0: add TX accumulation buffer to IpcSerialStream — batch single-byte
    log writes, flush on newline or buffer full. Add bench_bridge.py for raw
    bridge timing (bypasses CLI overhead).
    Result: CLI --info 15.0s → 5.9s. Per-KB gap (16×) remains — dominated by
    SerialConsole 5ms polling + no cross-core notification (M2 scope).
    [main_core1_bridge.c]
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2026-04-12 phase2: M2 prep — doorbell deadlock fix + M2 scaffolding (#if 0)
    Fix critical bug: FreeRTOS RP2350_ARM_NTZ port registers doorbell ISR
    (prvDoorbellInterruptHandler) in single-core mode via pico_sync_interop,
    causing spinlock deadlock when Core 1 fires doorbells → Core 0 setup()
    never reaches consoleInit() → meshtastic --info timeout.
    Core 0: new MOKYA_DOORBELL_PATCH disables FreeRTOS doorbell ISR,
    RebootNotifier observer, debug breadcrumbs, linker 0x14000 offset.
    Core 1: doorbell ISR, reboot handler, event-driven bridge_task — all
    #if 0 disabled, to be enabled incrementally in M2 steps.
    Shared: IPC_MSG_REBOOT_NOTIFY, IPC_DOORBELL_NUM definitions.
    All doorbell code disabled — func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
    [main_core1_bridge.c]
2026-04-12 phase2: M2 Steps 1-5 — interrupt-driven IPC + P2-11 discovery
    Enable all M2 doorbell #if 0 blocks across both cores:
    Core 1 (main_core1_bridge.c):
    - Register ipc_doorbell_isr on SIO_IRQ_BELL (Step 1)
    - irq_set_enabled at bridge_task start (Step 1)
    - doorbell_set_other_core on c1→c0 push (Step 3)
    - xTaskNotifyWait replaces taskYIELD polling (Step 4)
    Core 0 (submodule bump):
    - multicore_doorbell_set_other_core on c0→c1 push (Step 2)
    - RebootNotifier doorbell for IPC_MSG_REBOOT_NOTIFY (Step 5)
    Verified: Steps 1-4 pass meshtastic --info (~5.97s, no regression).
    Step 5 reboot test exposed P2-11: flash_range_erase runs with XIP
    off + interrupts enabled + Core 1 active → IACCVIOL HardFau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
    [main_core1_bridge.c]
2026-04-12 phase2: M2 close-out — flash safety (P2-11) + graceful reboot (P2-10) + interrupt IPC
    M2 delivers three features:
    Part A: Interrupt-driven IPC — Core 1 doorbell ISR dispatches both
    IPC_DOORBELL_NUM (ring data) and IPC_FLASH_DOORBELL (flash park).
    bridge_task uses xTaskNotifyWait instead of taskYIELD. --info 5.9s→4.8s.
    Part B: Graceful reboot — RebootNotifier pushes IPC_MSG_REBOOT_NOTIFY,
    Core 1 calls tud_disconnect() before watchdog fires. COM port
    re-enumerates cleanly (fixes P2-10).
    P2-11: Flash write safety — --wrap flash_range_erase/program parks
    Core 1 via shared-SRAM flash_lock protocol + disables Core 0 interrupts.
    Eliminates IACCVIOL HardFault on meshtastic --set.
    Part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
    [main_core1_bridge.c]
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2026-04-13 fix: P2-13 — XIP cache disabled since boot, 30–85× instruction fetch slowdown
    Root cause: RP2350 ROM flash_exit_xip() and PSRAM init clear XIP_CTRL
    EN bits. Pico SDK boot2 restores QMI but never re-enables the 4 KB XIP
    cache. All Core 0 instruction fetches hit 37.5 MHz QSPI flash directly.
    Fix: re-enable XIP cache in initVariant() and after each wrapped flash
    op. Also: -DDEBUG_MUTE compile-time LOG suppression, Core 1 bridge
    taskYIELD in stall loop.
    bench_raw_serial2 results (MokyaLora vs Stock Pico2):
    - Per-frame gap: 12–50 ms → 0–1.6 ms (stock: 1.2–3.3 ms)
    - Burst rate: 2.14 frm/ms (stock: 0.51 frm/ms) — 4.2× faster
    - --info wall time: 15.0 s → 4.4 s (stock: 4.4 s) —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
    [main_core1_bridge.c]
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2026-04-14 m3: add ST7789VI display driver + fix Core 1 SysTick reload
    M3.1 — PIO/DMA 8080-8 parallel bus driver for ST7789VI 240×320 IPS panel.
    display.c owns the bus/DMA flow and LM27965 backlight bring-up (provisional);
    st7789vi.c carries only the panel-specific init sequence behind a callback
    interface so the bus layer can be reused for future panels. PIO program
    emits nWR + D[7:0] at 80 ns TWC (clkdiv=3 @ 150 MHz sys_clk, ~21 % margin
    over ST7789VI TWC_min=66 ns).
    Also fixes two Core 1 bring-up gotchas exposed while standing up the
    display test task:
    * FreeRTOS heap was 16 KB but three 1024-word task stacks plus Timer/Idle
    already total ~16 KB before TCB overhead — xTaskCreate silently fa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
    [display.c, main_core1_bridge.c]
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2026-04-15 m3: integrate LVGL v9.2.2 flush_cb -> ST7789VI (M3.2)
    Replaces the standalone display_test_task with an LVGL-driven
    render loop in lvgl_glue.{h,c}: 240x40 partial RGB565 buffer,
    xTaskGetTickCount tick source, flush_cb does in-place RGB565
    byte-swap then blocking display_flush_rect. Task runs at
    tskIDLE_PRIORITY+2 with a 16 KB stack and clamps lv_timer_handler's
    next-deadline hint to [LV_DEF_REFR_PERIOD, 100 ms].
    Smoke test cycles the active screen's bg_color red -> green -> blue
    at 1 Hz; visually verified on the Rev A panel at ~6 fps.
    P3-2: switched LV_USE_OS from LV_OS_FREERTOS to LV_OS_NONE.
    LVGL v9.2.2's FreeRTOS OSAL creates its global mutex with
    xSemaphoreCreateRecursiveMutex() but ac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
    [main_core1_bridge.c]
2026-04-15 fix(display): Core 1 I2C clock for LM27965 backlight driver
    Root cause: Core 1 skips runtime_init_clocks (Core 0 owns clock init),
    so clock_get_hz(clk_peri) returns 0. i2c_init() uses this to compute
    the baudrate divisor, resulting in garbage SCL timing. Some I2C writes
    succeeded by chance, but BANKA duty register consistently NACKed,
    leaving backlight at 20% instead of 40%.
    Fix: add i2c_set_baudrate_core1() that manually computes SCL timing
    from the known clk_peri frequency (150 MHz). Called after i2c_init()
    to correct the divisor.
    Also adds bus_b_recovery() (9 SCL pulses + manual STOP) and SWD
    diagnostic breadcrumb at 0x2007FFF4.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
    [display.c]
2026-04-15 perf(display): optimize flush with PIO clkdiv + REV16 byte-swap
    Optimizations:
    1. Reduce PIO clkdiv from 3.0 to 2.0 (80 ns → 53 ns write cycle)
    2. Use ARM REV16 instruction for 2-pixel-at-a-time byte-swap
    Result: flush time reduced from 6.3 ms to 1.4 ms (4.5x speedup).
    Also:
    - Enable LV_USE_SYSMON for benchmark FPS overlay
    - Enable LV_FONT_MONTSERRAT_24 for benchmark demo
    - Adjust LV_DEF_REFR_PERIOD to 33 ms (realistic for DIRECT mode)
    [display.c]
2026-04-17 chore(debug): release breadcrumbs from solved issues (P2-5/6, P3-2, P3-3, M1.1-B)
    Prune the 64 B post-mortem region (0x2007FFC0–0x2007FFFF) down to the
    four operational slots that live code actively consumes:
    0x2007FFC4 rx total (bridge_task)
    0x2007FFC8 tx total (bridge_task)
    0x2007FFCC usb state (bridge_task)
    0x2007FFF8 LVGL assert tag (LV_ASSERT_HANDLER)
    Released slots (writers deleted, not renamed):
    FFC0 M1.1-B bring-up sentinel 0xC1B01200
    FFD0 bridge_task loop-count liveness
    FFD4 dual writer — bridge M3.2 build stamp AND lvgl_glue flush_us
    FFD8 LVGL task phase breadcrumb (P3-2 OSAL deadlock debug)
    FFDC main() task-creation result word
    FFE0..FFEC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
    [display.c, main_core1_bridge.c]
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2026-04-17 fix(core1): correct RP2350B board header + wire keypad Phase A
    Root cause fix — GPIO 30-47 were silently dropped by the SDK because
    the stock pico2 board header sets PICO_RP2350A=1, which forces
    NUM_BANK0_GPIOS=30. check_gpio_param(36) then short-circuits every
    SDK GPIO call and leaves the pad at its reset default 0x00000116
    (ISO=1, IE=0, FUNCSEL=NULL). Display at GPIO 10-22 worked by
    coincidence; keypad at GPIO 36-47 did not.
    Replace the board header with a MokyaLora-specific variant at
    firmware/core1/m1_bridge/boards/mokya_rev_a.h (RP2350B, 48 GPIOs,
    W25Q128JW 16 MB flash). CMakeLists appends the directory to
    PICO_BOARD_HEADER_DIRS and sets PICO_BOARD=mokya_rev_a.
    Add Phase A keypad sc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
    [main_core1_bridge.c]
2026-04-17 feat(keypad): switch Phase A to PIO + DMA continuous scan
    Replace the Phase A GPIO-polling scanner (keypad_min) with a PIO0 +
    2-DMA continuous-scan pipeline (keypad_scan). Once keypad_init()
    returns, the CPU never touches PIO FIFOs again — two DMA channels in
    ring mode shuttle a fixed 8-byte mask table into TX FIFO and drain
    RX FIFO into a matching 8-byte result ring, so host code just reads
    the ring at whatever cadence the consumer needs.
    This moves the keypad driver onto the zero-CPU path described in
    firmware-architecture.md §4.4, unlocking the future DMA-driven
    scan-rate bump (currently 8.3 kHz, can go higher by reducing the
    settling nop) without changing the API. `keypad_read(out[6]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
    [main_core1_bridge.c]
2026-04-17 feat(keypad): M3.3 Phase B — debounce + keymap + multi-producer KeyEvent queue
    Per-key 20 ms debounce (5 ms tick × 4-sample stability) on top of the Phase A
    PIO+DMA raw scanner. State changes translate through keymap_matrix.h (Step 6
    scan-order LUT) and enqueue into a 16-slot FreeRTOS queue with a 64-bit
    HW-pressed bitmap for HW-vs-INJECT arbitration (usb-control-protocol §9.1,
    reserved for M9). Verified: 5 physical presses across R1 C0–C4 produce exactly
    10 correctly-decoded press/release events; meshtastic --info still passes.
    [main_core1_bridge.c]
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2026-04-18 feat(i2c): M3.4.1 — Core 1 shared I2C bus module with time-muxed i2c1
    Root issue: both power (GPIO 6/7) and sensor+GNSS (GPIO 34/35) pin pairs
    map to i2c1 only on RP2350 (mod-4 = 2/3 rule; no I2C0 pinmux alternative
    on either pair), so the two buses cannot run as separate SDK peripherals
    as previously documented.
    Firmware:
    - New firmware/core1/src/i2c/i2c_bus.{h,c}: single i2c1 peripheral +
    FreeRTOS mutex; i2c_bus_acquire() flips FUNCSEL between the two pin
    pairs on each acquire. ~200 ns switching cost vs 90 us/byte at 100 kHz.
    - Keeps the Core 1 baudrate fix (clock_get_hz(clk_peri)=0 on Core 1).
    - display.c backlight_init uses acquire/release; all i2c_init/deinit
    removed from drive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
    [display.c, i2c_bus.c, main_core1_bridge.c]
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2026-04-18 feat(charger): extend BQ25622 — TS/TDIE ADC, HIZ, BATFET mode APIs
    Short-term features for M3.5 sleep mode and thermal monitoring:
    - ADC burst extended from 12 → 16 bytes (REG0x28..REG0x37) to include
    TS_ADC (bits [11:0] unsigned, 0.0961 %/LSB per §8.6.2.36) and TDIE_ADC
    (bits [11:0] 2's complement, 0.5 °C/LSB per §8.6.2.37). State struct
    gains ts_pct_x10 and tdie_cx10.
    - bq25622_set_hiz(bool) — RMW CTRL1[4]. High-impedance mode for the
    sleep / DORMANT state machine. WATCHDOG expiry auto-clears EN_HIZ
    (§8.6.2.12) which is desirable — host can no longer respond so
    the safe state is "charge normally".
    - bq25622_set_batfet_mode(mode) — RMW CTRL3[1:0] with BATFET_DLY l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
    [bq25622.c]
2026-04-18 feat(leds): M3.4.3 — LM27965 3-bank LED driver
    Replaces the provisional backlight_init() that lived inline in display.c
    with a standalone driver under firmware/core1/src/power/. The driver
    owns all LM27965 register writes and caches the GP byte so partial
    updates (e.g. toggling EN3B for the green LED) do not clobber other
    enable bits.
    API:
    lm27965_init(tft_duty) — boot-time setup;
    writes Bank A duty
    before asserting ENA
    to avoid a current
    spike from the POR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
    [display.c, lm27965.c]
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2026-04-18 feat(sensor): M3.4.5a — LPS22HH driver + sensor-bus I2C baudrate fix (P2-14)
    Adds the first Core 1 sensor-bus driver: a polling LPS22HH barometer
    plus a new sensor_task that owns the 10 Hz master tick for all
    sensor-bus peripherals (LIS2MDL/LSM6DSV16X slot in next). State
    reports pressure_hpa_x100, temperature_cx10, online, i2c_fail_count.
    Bring-up uncovered P2-14: i2c_set_baudrate_core1() only set the
    standard-speed counters, leaving FS counters and sda_hold at the
    garbage values i2c_init() computed from clock_get_hz=0 on Core 1.
    Power bus tolerated the marginal timing, sensor bus did not — all
    four devices NACKed from cold. Fix mirrors the SDK exactly
    (FS + SS counters, correct sda_ho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
    [i2c_bus.c, lps22hh.c, main_core1_bridge.c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]
2026-04-18 feat(sensor): M3.4.5b — LIS2MDL magnetometer driver
    Second sensor-bus driver (addr 0x1E). Slotted into sensor_task at 10 Hz
    (one poll per master tick), same shape as LPS22HH. Production config:
    ODR=10 Hz, continuous, COMP_TEMP_EN=1, LP=0 (high-resolution), OFF_CANC=1,
    LPF=1 (ODR/4), BDU=1. Exposes mag_raw[3], mag_ut_x10[3] (1.5 mgauss/LSB
    = 0.15 uT/LSB), temperature_cx10, online, i2c_fail_count.
    Key quirk — I2C auto-increment wraps at end of mag OUT block (0x6D to
    0x68), does NOT cross into TEMP_OUT at 0x6E. An 8-byte burst from 0x68
    returns X/Y/Z then repeats X rather than giving temperature. Datasheet
    §6.1.1 doesn't document this wrap — discovered by comparing a single
    8-byte burst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
    [lis2mdl.c, sensor_task.c]
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2026-04-18 feat(gnss): M3.4.5d Part A — Teseo-LIV3FL NMEA driver + gps_task
    Teseo-LIV3FL streams NMEA over I2C (0x3A, sensor bus), so the driver
    lives in its own FreeRTOS task (priority tskIDLE+2, 2 KB stack) with a
    100 ms drain cadence rather than sharing the sensor tick. Byte-level
    line accumulator + checksum-verified parsers for GGA, RMC and GSV;
    state exposed as teseo_state_t (fix / lat / lon / alt / speed / course /
    HDOP / UTC, using lat_e7 / lon_e7 so the next stage can feed
    IpcPayloadDeviceStatus directly) and teseo_sat_view_t (up to 32 sats
    pooled from GP/GL/GA/BD talkers, with per-cycle update_count for UI
    staleness detection).
    Runtime ODR API teseo_set_fix_rate(GNSS_RATE_{OFF,1,2,5,10}HZ)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
    [main_core1_bridge.c]
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2026-04-19 feat(core1): M4 Step 3 — PSRAM init + MDBL dict copy-at-boot
    Core 1 now initialises the APS6404L 8 MB QSPI PSRAM at boot and
    copies the MDBL dict blob (4.76 MB) from flash partition 0x10400000
    into fixed PSRAM slots. Verified end-to-end via SWD: APS6404L
    responds to Read-ID (0D 5D ...), MDBL geometry checks pass, and all
    four MIED section headers are readable at the expected PSRAM
    addresses (zh_dat key_count=125336, en_dat key_count=2897 — both
    match the packager output).
    firmware/core1/src/psram/psram.{c,h} (new)
    Ported from firmware/tools/bringup/bringup_psram.c (Rev A bring-up
    validated 2026-04-05), stripped of diagnostic / sweep / probe code.
    Runs the full QMI M1 init sequence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
    [main_core1_bridge.c, psram.c]
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2026-04-19 fix(core1/psram): set MAX_SELECT=1 for APS6404L DRAM refresh (P2-15)
    M1.timing inherited MAX_SELECT=0 from M0 flash via the bit-preservation
    pattern in psram_init_run, letting QMI hold CS asserted indefinitely
    across back-to-back PSRAM accesses. APS6404L-SQN-ZR is pseudo-SRAM with
    DRAM cells whose self-managed refresh only runs while CS is HIGH
    (datasheet tCEM=8µs standard grade). Result: 93.75% word errors on
    uncached full-8MB round-trip, 46.81% on cached — manifested as IME
    candidate corruption for common shape-byte inputs.
    Set MAX_SELECT=1 (64 sys_clk trigger + <=316 cycle burst completion
    ~= 3.8us total CS-low, comfortably under 8us tCEM). Validated full
    8 MB cached round-trip: 0 / 2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
    [psram.c]
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2026-04-19 fix(core1/bridge): restore i2c_bus_init_all() dropped in M4 Step 3
    The call was accidentally removed when PSRAM init was added. Without
    it s_bus_mutex is NULL and every i2c_bus_acquire() fails, breaking
    lvgl_task (lm27965 backlight), charger_task, sensor_task, gps_task.
    [main_core1_bridge.c]
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2026-04-21 fix(core1/psram): port bringup RXDELAY=CLKDIV fix, CLKDIV 2→1 (75 MHz)
    Applies the same three-part PSRAM timing correction validated in
    bringup (previous commit). Net effect on this firmware:
    - CLKDIV 2→1 : SCK 37.5 → 75 MHz (1.7× throughput)
    - RXDELAY 0→2 : =CLKDIV, Arduino-Pico's formula; fixes the real
    board-variance root cause
    - DUMMY_LEN 28→24 b : 6 clocks per datasheet §9.5 (was 7 — legacy
    "empirically requires" comment was compensating
    for wrong RXDELAY)
    MAX_SELECT=1 kept (P2-15). COOLDOWN=2 still meets tCPH≥18 ns at 75 MHz
    (26.7 ns).
    Expected gains for production workload:
    - MIE di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
    [psram.c]
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2026-04-21 docs(core1/psram): correct write-back cache comments from psram_wthru evidence
    Follow-up cleanup after the RXDELAY=CLKDIV fix uncovered that some of
    the surrounding documentation was either outdated, wrong, or directly
    contradicted by the code. No behavioural change — this is a pure
    comment/docstring refresh, validated by a clean Core 1 build.
    Source of the corrections: the bringup psram_wthru test (previous
    commit) which empirically characterised RP2350 XIP cache semantics
    against APS6404L.
    Specific fixes:
    * psram.h frequency: CLKDIV=2 (37.5 MHz) → CLKDIV=1 (75 MHz), adds
    RXDELAY/DUMMY/MAX_SELECT summary and a WRITE-BACK cache warning.
    * psram.c WRITABLE_M1 comment: the old text c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
    [psram.c]
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2026-04-23 wip(core1): RTT key-inject transport — disabled pending tight-loop debug
    Firmware + host scaffolding for the alternate key-injection transport
    (RTT down-channel, 256 B ring). Coexists with the SWD-RAM path and
    parses into the same key_event_push_inject_flags(). Binary wire frame
    (magic 0xAA55 + type + len + payload + crc8), shared parser in
    key_inject_frame.{c,h}, task body in key_inject_rtt.{c,h}, host side
    in scripts/mokya_rtt.py.
    Host-side direct memory write works: WrOff in the down descriptor
    advances and bytes land in the 256 B ring (pylink.rtt_write itself
    proved unreliable on RP2350 + J-Link V932 — subsequent writes in a
    session silently drop; memory_write8 into the SEGGER contr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
    [main_core1_bridge.c]
2026-04-23 feat(core1): RTT key-inject transport — end-to-end working
    Enables the RTT path committed in WIP bb4c550. Two independent root
    causes masked each other during the first landing attempt; both fixed
    here:
    1. Boot-time heap panic. `key_inject_rtt_task_start` requests a ~1 KB
    TCB+stack from FreeRTOS heap. Pre-existing 20 % reserve policy
    (heap_min = configTOTAL_HEAP_SIZE / 5 = 9.6 KB) tripped silently
    when heap_free dropped to 8.8 KB, so `panic()` fired before
    `vTaskStartScheduler()`. xTickCount never advanced → every task
    appeared to run (pxCurrentTCB held the last-created TCB forever)
    but no body executed. Loosen reserve to 15 % (7.2 KB) and expose
    boot heap_free as `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
    [main_core1_bridge.c]
2026-04-23 feat(scripts): ime_text_test --transport swd|rtt + mokya_swd.rtt_send_frame
    Host-side plumbing for dual key-injection transport:
    - MokyaSwd.rtt_send_frame(frame, timeout_s): locate the SEGGER RTT
    down-buffer for channel 1 from the ELF (_SEGGER_RTT symbol + fixed
    descriptor offsets), then write bytes straight into the ring +
    publish WrOff. Bypasses pylink.rtt_write entirely (it proved
    unreliable on RP2350 — second write per session silently drops).
    Cached after first call.
    - MokyaSwd.rtt_ring_empty(): fast wr==rd check used by the host
    drain-wait loop.
    - ime_text_test.py --transport swd|rtt flag. SWD path unchanged.
    rtt path builds MOKYA_KIJ_TYPE_KEY_EVENT frames (magic + t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
    [main_core1_bridge.c]
2026-04-23 chore(core1): disable RTT key-inject task start, document as P1.6.1
    ime_text_test --transport rtt pathway is host-side complete, but
    enabling key_inject_rtt_task_start() alongside the SWD key_inject
    consumer wedges SWD regression: the SWD ring producer can't get
    enough CPU to push events before the 2 s host-side inject deadline
    expires, even after priority tuning attempts (+2 starves, +3
    starves ime_task, 20 ms idle poll on RTT didn't help enough).
    Root cause is three tasks (key_inject, key_inject_rtt, ime) all
    at the same band with no explicit arbitration.
    Proper fix is a single consumer task with transport-specific
    producers — tracked as P1.6.1. Leaving RTT firmware activation
    commented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
    [main_core1_bridge.c]
2026-04-23 feat(core1): mode-based SWD/RTT key-inject arbitration
    Both transports coexist at runtime, controlled by a shared
    g_key_inject_mode byte. Whichever task isn't selected long-sleeps
    (50 ms) so ime_task never competes with two hot pollers at the
    same priority band — fixing the scheduler starvation from the
    original dual-activation attempt.
    - Firmware: g_key_inject_mode (volatile u8, default SWD). Each task
    checks it at loop top; mismatch → vTaskDelay(50 ms) continue.
    Active task keeps its original 5 ms (SWD) / 5-20 ms (RTT) cadence.
    - Host: MokyaSwd.set_key_inject_mode() writes the byte via SWD and
    sleeps 60 ms so the target observes the switch before the burst
    starts. __exit__ alw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
    [main_core1_bridge.c]
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2026-04-25 fix(ipc): P2-17 — IPC byte bridge must not truncate mid-frame
    Both directions of the Core 0 ↔ Core 1 ↔ USB CDC byte bridge had
    "timeout-then-break" paths that silently dropped bytes mid-frame,
    permanently desyncing the host's Meshtastic stream-protocol parser:
    Core 0 IpcSerialStream::write — 50 ms ipc_ring_push deadline
    (committed in submodule)
    Core 1 bridge_task data ring — 10 stall_ticks tud_cdc_write_available
    timeout (this commit)
    Stream protocol has no frame-level retransmit. Once the 4-byte
    0x94 0xC3 LEN_HI LEN_LO header is on the wire, the host reads exactly
    LEN payload bytes — any drop caus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
    [main_core1_bridge.c]
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2026-04-25 fix(phoneapi+ipc): P2-19 — PhoneAPI heartbeat clobbered every reply; settings page spin
    Meshtastic submodule patch: PhoneAPI::getFromRadio()'s heartbeat fast-path
    LOG_DEBUG'd "STATE_SEND_QUEUE_STATUS, numbytes=N" *after* pb_encode_to_bytes
    had written queue_status to the caller's txBuf. With SerialConsole's
    post-want_config protobuf log encapsulation enabled, LOG_DEBUG re-enters
    StreamAPI::emitLogRecord, which shares txBuf and fromRadioScratch with
    the same flow — encoding a 66-byte log_record over the just-written
    queue_status. writeStream() then emits the original numbytes (=6) from
    the now-clobbered buffer, so the wire shows a clean log_record frame
    followed by a truncated frame whose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
    [main_core1_bridge.c]
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

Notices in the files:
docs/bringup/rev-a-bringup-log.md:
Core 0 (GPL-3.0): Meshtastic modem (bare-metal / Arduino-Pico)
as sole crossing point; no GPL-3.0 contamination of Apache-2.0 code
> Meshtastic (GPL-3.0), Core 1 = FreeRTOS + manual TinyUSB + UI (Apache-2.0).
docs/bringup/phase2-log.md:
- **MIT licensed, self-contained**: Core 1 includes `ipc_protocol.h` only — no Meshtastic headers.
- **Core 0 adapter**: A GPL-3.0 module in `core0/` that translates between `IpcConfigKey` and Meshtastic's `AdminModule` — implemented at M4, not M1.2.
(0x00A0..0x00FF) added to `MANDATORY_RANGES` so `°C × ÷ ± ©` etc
